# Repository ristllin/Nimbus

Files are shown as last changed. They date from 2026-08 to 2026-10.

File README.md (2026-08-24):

<p align="center">Nimbus - dotted teal ring logo</p>

# Nimbus

<!-- HERO PHOTO PLACEHOLDER: assembled device on a desk - ring lit, the touch
     panel showing the status screen. Add the photo to assets/ and embed it here. -->

<p align="center">
  
  
  
</p>

A DIY desk device that keeps you informed without stealing your screen.
Two modes on one firmware: an ambient **status light for AI coding sessions**
(encrypted Bluetooth, per-session ring segments), and a **self-hosted AI
assistant** with voice, Telegram, and long-term memory on its own SD card.
A 45-LED ring plus a 2.8" color touchscreen (or a Freenove all-in-one touch
board) on an ESP32-S3. Bring your own API key (Mistral, OpenAI, or Anthropic);
about **$60–75 in commodity parts** to build.

**Documentation: https://docs.cumulo-nimbus.ai/**

## What you need

- The electronics - dev board, display, LED ring, mic/amp/speaker, microSD,
  battery section: full list with sourcing links and prices in the
  **[bill of materials](docs/hardware/bom.md)** (~$60–75)
- A data-capable USB-C cable
- A computer with a Chromium browser (web flasher) or Python 3 + PlatformIO
- A 2.4 GHz Wi-Fi network
- One AI provider API key (Orchestrator mode; skip for the status light)
- Optional: a FAT32 microSD card for long-term memory, and a Telegram account

## Quick start

The step-by-step path - parts → flash → setup wizard → first conversation -
lives on the docs site:

1. **[What you need](https://docs.cumulo-nimbus.ai/quick-start/what-you-need)**
2. **[Flash the firmware](https://docs.cumulo-nimbus.ai/quick-start/flash)**
   - browser flasher, or `python3 tools/setup_device.py` over the DevKit's
   **UART** port (a factory-fresh board flashes only through that port)
3. **[Set up the device](https://docs.cumulo-nimbus.ai/quick-start/setup-wizard)**
   - join the `Nimbus-setup` network, walk the wizard
4. **[Your first conversation](https://docs.cumulo-nimbus.ai/quick-start/first-conversation)**
   - or the **[Notifier quick start](https://docs.cumulo-nimbus.ai/quick-start/notifier-quick-start)**
   for the status light

## Safety

This build contains a **2S lithium-ion pack** (two 18650 cells in series).
Use brand-name cells from a reputable vendor, always keep the 2S BMS between
the cells and everything else, never charge outside the BMS, and power off
immediately if anything gets warm that shouldn't. The firmware caps LED
brightness at 60% of maximum: sustained higher levels have been tested and
can overheat and damage internal electronics, so do not raise the limit. See
the [BOM safety note](docs/hardware/bom.md#safety-note--2s-li-ion).

**You build and operate this project entirely at your own risk.** It is a DIY
prototype, not a certified product, and comes with no warranty of any kind;
the author accepts no liability for damage or injury arising from building or
using it. Read [DISCLAIMER.md](DISCLAIMER.md) before you start, especially if
your build includes the battery.

## Building the firmware

Board support lives in the public
[solide-drivers](https://github.com/ristllin/solide-drivers) repository,
consumed as a PlatformIO library. `platformio.ini` expects it as a **sibling
checkout** (`symlink://../solide-drivers`):

```bash
git clone https://github.com/ristllin/Nimbus.git
git clone https://github.com/ristllin/solide-drivers.git   # sibling directory
cd Nimbus
pio test -e native            # host unit tests, no hardware
pio run -e esp32s3            # compile production firmware
python3 tools/setup_device.py # guarded install over the UART port
```

If you prefer not to keep a sibling checkout, point the `lib_deps` entry in
`platformio.ini` at the public git URL instead.

Nimbus speaks the [nimbus-notify](https://github.com/ristllin/nimbus-notify)
wire protocol (`pip install nimbus-notify` for the host-side broker), and
ships signed firmware updates from
[nimbus-fw-releases](https://github.com/ristllin/nimbus-fw-releases).

## Layout

- `lib/core/` - portable logic (no Arduino): protocol codec, profiles, power
  policy, the orchestrator memory engines and turn contract. Host-tested.
- `src/` - firmware: hardware glue (`hw/`), modes (`modes/`), the agent
  subsystem (`agent/`), the web surface (`net/`), entry point.
- `lib/harness/` - the agent policy/orchestration layer, host-testable.
- `test/` - Unity C++ **host** suites per module (run under `pio test -e native`,
  no hardware); golden framebuffers pin every screen.
- `tests/hil/` - the Python **hardware-in-the-loop** suite (drives a real board).
  (The `test` *build environment* is a third, unrelated thing - the firmware plus
  a serial console the HIL suite drives.)
- `docs/` - the canonical documentation tree
  ([map](docs/README.md)); `website/` publishes it to GitHub Pages.
- `hardware/` - the physical build: PCB manufacturing files (`fab/`) and a home for
  assembly notes, BOM, and CAD. The published build guides live in `docs/hardware/`.
- `tools/` - installer, recovery, calibration, generators, test harnesses
  ([index](tools/README.md)).
- `evals/` - orchestrator behavior benchmark (scenario corpus, scoring, reports).

Contributor guide: [CONTRIBUTING.md](CONTRIBUTING.md) and the
[development guide](docs/development.md) (build environments, test ladder,
golden-test flow, hard-won constraints).

## Community

Questions, builds, and ideas:
[GitHub Discussions](https://github.com/ristllin/Nimbus/discussions).
Bugs: [issues](https://github.com/ristllin/Nimbus/issues).

## License

Nimbus is **source-available for noncommercial use**:

- **Code, firmware, scripts** - [PolyForm Noncommercial License 1.0.0](LICENSE)
- **Documentation, hardware design files, images** -
  [CC BY-NC-SA 4.0](LICENSE-docs)
- Attributions and third-party notices: [NOTICE](NOTICE)

Build one, modify it, share your fork - just not commercially.

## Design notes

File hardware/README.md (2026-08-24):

# Hardware

Everything physical about a Nimbus build - what to source, how to assemble it, and
the board manufacturing files.

> **New here?** Start with the documentation, which walks the whole build:
> - [Bill of materials](../docs/hardware/bom.md) - what to buy, with sourcing links
> - [Build guide - Touch TFT](../docs/hardware/build-tft.md)
> - [Hardware reference](../docs/hardware.md) - pinout, wiring, power
>
> Those pages are also on the [documentation site](https://docs.cumulo-nimbus.ai/).

> **Safety and liability:** you build at your own risk. This is a DIY
> prototype involving lithium-ion batteries, not a certified product; no
> warranty, no liability. Read [DISCLAIMER.md](../DISCLAIMER.md) first.

## What's in this folder

| Path | Contents |
|---|---|
| [`fab/`](fab/) | PCB manufacturing outputs (Gerbers, drill, ODB++) for the Solide S3 carrier board, [how to order it (e.g. JLCPCB)](fab/README.md#ordering-the-pcb), and the [3D-printable enclosure STLs](fab/README.md#3d-printing-the-enclosure). Not required if you build from off-the-shelf modules. |

## Assembly notes, BOM extras, and CAD

This folder is the home for build material that isn't firmware: assembly photos and
step notes, a spreadsheet BOM, enclosure/CAD files, and any wiring harness details.
It starts light on purpose - add to it as the physical design settles. The canonical,
published build documentation stays under [`docs/hardware/`](../docs/hardware/) so it
ships to the docs site; this folder holds the source artifacts those pages describe.

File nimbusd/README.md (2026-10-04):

# nimbusd - the hosted Nimbus daemon

A **virtual nimbus**: the same Nimbus orchestrator the desk device runs (turn
engine, memory, tools, provider adapters, Telegram persona), running as a Linux
process in a container instead of on an ESP32. To cumulo it is just a device.
This directory is Phase 0 of the Virtual Nimbus plan
(`../../cumulo/docs-internal/virtual-nimbus-plan.md`): the daemon itself, before
the relay sidecar (Phase 1) and provisioning/billing (Phase 2).

## What is the real code, and what is new

Everything above the transport seam is the **same portable engine** the firmware
compiles - `lib/core` (turn contract, memory engines, tool registry, RBAC) and
`lib/harness` (turn engine, provider adapters, compose/apply). nimbusd is a
composition: it wires that engine to durable POSIX stores and a real network
transport, exactly as `tools/harness-lab` wires it to RAM and libcurl for host
testing. A bug reproduced here is a bug on the board, and vice versa.

New code lives only in this directory:

| File | What it is |
|---|---|
| `src/posix_fs.h` | `PosixEpiFs` (the `EpiFs` byte-file seam over a POSIX tree) + `fsutil` atomic tmp->rename writer |
| `src/posix_platform.h` | `agent::Platform` with **cgroup v2 heap accounting** so the engine sheds load before the kernel OOM-kills the pod |
| `src/daemon_http.h` | `agent::HttpTransport` over one persistent, connection-reusing curl handle; bodies never retained; keeps only the bounded error headers a request asks for (a 429's `x-ratelimit-*` quota window) |
| `src/posix_files.h` | disk-backed `files.*` / `artifact.save` (real bytes + `FileStore` index, `validSegment` gate) |
| `src/daemon_config.h` | `HarnessConfig` inputs from env + an optional config file (env wins); secret masking |
| `src/telegram.h` | Telegram channel over the portable `nimbus::tg::parseUpdates` + offset arithmetic; durable offset |
| `src/tg_access.h` | who may talk over Telegram: the device's fail-closed allowlist + approval queue + the shared RBAC `TenantStore`, durable on the instance volume |
| `src/tg_inbound.h` | routes each getUpdates batch through `tg_access.h`: approved text becomes a turn, anyone else is queued for approval and told so |
| `src/tg_web.h` | the device's `/api/telegram*` + `/api/tenant` routes over `tg_access.h`, so the web app's Telegram panel manages a hosted instance unchanged |
| `src/rig.h` | `NimbusdRig` - the composition, rehydrating all stores on construct and flushing after each turn |
| `src/engine_thread.h` | the concurrency layer: one engine thread + request mailbox + a snapshot for lock-free reads |
| `src/http_control.h` | the 127.0.0.1-only control surface (serves the web app + logo, health, replies, message, MCP, backup; delegates `/api/*` to `WebApi`), web-token gated |
| `src/web_api.h` | the `/api/*` surface the web app calls, answered with honest Virtual Nimbus semantics (real chat/memory/providers; hardware panels honestly virtual) |
| `src/web_ui.h` | assembles the served page and seeds the tunnel sign-in token ahead of the app script |
| `src/webui_page.h` | GENERATED (`tools/gen_webui.py`): the device's web app fragments, byte-parity with `tools/webui_page.snapshot`, plus the brand logo |
| `src/reply_buffer.h` | the bounded, thread-safe ring of recent chat entries (seq + timestamp + role) that backs `GET /api/replies` and `/api/chat` |
| `src/main.cpp` | the daemon entrypoint (config, threads, Telegram poll, graceful shutdown) |

## Durable data layout (`/data` by default)

```
/data/mem/vectors.bin        associative (vector) memory - atomic snapshot
/data/mem/episodic/*.jsonl   episodic append-log day-streams (durable per write)
/data/mem/scratchpad.txt     the model's working-memory tiers
/data/mem/memconfig.txt      retrieval/decay knobs
/data/mem/files/             file artifacts + .index
/data/mem/telegram.txt       Telegram allowlist, display names, consumed legacy seed and the
                             RBAC roles + limits, in ONE atomically written file
/data/tg_offset              Telegram long-poll offset (no re-delivery on restart)
```

**Memory survives restart.** The episodic append-log is durable per message; the
whole-file stores are flushed (atomic tmp->rename) after every turn and on a
clean shutdown, and rehydrated on construction. This is proven offline by
`tests/test_posix_stores.cpp` and `tests/test_rig.cpp`, and live (with real
embeddings) by the `restart` scenario.

## Build and test

```bash
make test        # offline unit/T2 suite (no keys, no network) - the CI marker
make daemon      # build ./build/nimbusd
make scenarios   # build ./build/nimbusd-scenarios (PAID to run - see below)
make check       # compile-only anti-rot gate
```

Host builds need ArduinoJson (populate `.pio/libdeps/native` once with
`pio test -e native` at the repo root) and a sibling `../solide-drivers` checkout
(the portable headers). The Docker build fetches both itself.

### Docker

```bash
docker build -f nimbusd/Dockerfile -t nimbusd:dev .   # context = repo root
docker run --rm -e TELEGRAM_BOT_TOKEN=... -e MISTRAL_API_KEY=... \
  -e NIMBUSD_WEB_TOKEN=... -v nimbus-data:/data nimbusd:dev
```

The build stage runs `make test`, so a broken build never produces an image.

### Connectors e2e (live, paid)

`tools/vn_connectors_e2e.py` drives a running instance over its HTTP surface the
way the web app does: it configures Studio connectors (gcal, notion, slack on
Mistral), runs the workspace probe via `POST /api/verify` and checks that the
connector badge, the Capabilities row and the model catalog agree; then it asks
"What is on my calendar today?" and asserts the reply names an event that one
independent Mistral call with the calendar connector sees. Secrets come only from
the environment (`NIMBUSD_WEB_TOKEN`, `MISTRAL_ORACLE_KEY`) and every evidence
file is redacted. `--skip-bc` runs the free configuration + probe step only. It
waits between paid calls (`--settle`) because a Mistral key's Studio connectors
have their own per-minute and per-day request quota (`x-ratelimit-*-custom-*`
headers). A turn the provider refused is retried once, after `--settle`, only
when the reply names a window that can reopen by then (per-minute, or none
named); a spent daily quota or a plan that allows no such request is recorded,
not retried. It recognizes those replies by the engine's own 429 copy
(`lib/harness/src/rate_limit.cpp`), which `tools/test_vn_connectors_e2e.py`
pins as part of `make test`.

## Configuration

Secrets come from the environment (a mounted Secret in k8s); non-secret settings
may also live in `<data>/config.env`. Env always wins. Nothing secret is logged
(masked to 4 chars).

| Key | Meaning |
|---|---|
| `OPENAI_API_KEY` / `ANTHROPIC_API_KEY` / `MISTRAL_API_KEY` | BYOK provider keys (Phase 0 key mode) |
| `TAVILY_API_KEY` | web.search (the router does not proxy it) |
| `TELEGRAM_BOT_TOKEN` | the instance's bot (validate with `nimbusd --getme`) |
| `NIMBUSD_TG_CHAT_ID` | **legacy**, optional: a one-time seed of an EMPTY Telegram allowlist (see Telegram access below). It is no longer a gate |
| `NIMBUSD_WEB_TOKEN` | required to reach the control surface (the sidecar injects it) |
| `NIMBUSD_DATA_DIR` | durable store root (default `/data`) |
| `NIMBUSD_CONTROL_ADDR` / `NIMBUSD_CONTROL_PORT` | control surface bind (default `127.0.0.1:8787`) |
| `NIMBUSD_DEVICE_NAME`, `NIMBUSD_PRIORITY`, `TZ` | display name, provider failover order, timezone |
| `NIMBUSD_SUB_PRIORITY` | sub-agent provider order (device `subPrio`); unset = same as `NIMBUSD_PRIORITY` |
| `NIMBUSD_ORCH_HOST` | pin the head provider (device `orchHost`); unset = the first keyed provider in `NIMBUSD_PRIORITY` |
| `NIMBUSD_TOOL_LOOP` | `1` (default) head tool loop, `0` single-shot head turns (device `orchLoop`) |

## Telegram access (the device model)

A hosted instance trusts **no** Telegram chat by default, exactly like the desk
device. With a bot token set and nobody approved, every chat is refused: it gets
no turn, one polite message saying the owner has to approve it (at most once per
10 minutes per chat), and it waits in the approval queue (the newest 5, RAM only).
The owner approves people in the instance's own web app (**Assistant, Connectors,
Telegram**): one tap on a waiting sender, or **Add** by chat ID. The allowlist and
the roles are stored on the instance volume, so they survive restarts and ride
`GET /backup`.

- **Roles are the existing RBAC.** An approved chat is a **user**; admin is only an
  explicit grant (click a chip's role to cycle admin, user, guest, or `POST
  /api/tenant`). This differs from the device, which adopts the first approved chat
  as admin: on a hosted instance the owner lives in the web app, and that rule would
  hand owner rights to whoever was approved first. A user or guest runs as
  themselves: their own memory namespace, their own recall, a prompt that says who
  is speaking, and no access to the owner's files. An approved chat of any role can
  use the owner's connectors and start sub-agents: approving someone is granting
  that.
- **One namespace's sub-agent work at a time.** The shared job engine keeps one pool
  of sub-agent results and folds it into whoever speaks next, so a hosted instance
  keeps queued, running and unreported work inside one data namespace: a spawn
  from another namespace is refused with the reason, and a member's turn from
  another namespace is held on the engine thread until that work is reported (the
  owner's own turns never wait).
- **Revoking** (role `unknown` through `POST /api/tenant`) or removing a chat takes
  effect on its next message; a revoked chat is told its access was removed, and a
  removed chat's role is erased (re-approving starts it as a user). Work it left
  running is not reported to it.
- **No open access.** The device's "Open access" switch is refused on a hosted
  instance: a public bot would spend the owner's keys and reach the owner's
  connectors.
- **`NIMBUSD_TG_CHAT_ID` is legacy.** If set, it seeds an EMPTY allowlist once (that
  chat becomes the admin, since the operator named it as the owner's) and is then
  consumed: a list the owner already manages is left alone, and a seeded chat the
  owner removes does not come back on restart.
- The web chat and the token-gated control API are the owner's own surfaces and
  always run as the admin; a Telegram chat id posted to `POST /api/message` is held
  to the same allowlist as the Telegram poll.

The routing and every rule above are host-tested offline in
`tests/test_tg_access.cpp` and `tests/test_sub_fabric.cpp`.

## Control surface (the seam the Phase-1 sidecar forwards to)

Bound to **loopback only**. The data routes require the web token
(`X-Nimbus-Token` header, `Authorization: Bearer <token>`, or `?token=`); only the
app shell (`/`, `/index.html`), the brand logo (`/logo.svg`), `/healthz` and the
pre-auth sign-in exchange are ungated. The relay sidecar injects the token on
every forwarded request, so the browser reaches all of these through the tunnel.

| Method + path | Purpose |
|---|---|
| `GET /` and `GET /index.html` | the assembled Nimbus web app (ungated shell; seeds the tunnel sign-in token) |
| `GET /logo.svg` | the brand mark (ungated; a logo is not sensitive) |
| `GET /healthz` / `GET /readyz` | liveness (ungated) / readiness (200 iff the engine thread is running) |
| `GET /api/state`, `/api/health`, `/api/orch` | Home / Assistant snapshots, served from the engine snapshot + immutable config (never enter the engine) |
| `POST /api/chat` + `GET /api/chat` | send a turn, then poll for the reply (the web app's chat surface) |
| `GET /api/replies?after=<seq>` / `POST /api/message` | the CUM-263 reply ring + enqueue-a-turn contract (kept stable) |
| `GET/PUT /api/mem/*`, `GET /api/tools` | memory dashboard, dispatched onto the engine thread (single-context safe) |
| `GET /api/themes`, `/api/qr`, `/api/docs/search` | pure/static surfaces (no engine, no hardware) |
| hardware panels (`/api/audio/*`, `/api/wifi`, `/api/ota/*`, ...) | honest "not on a hosted instance" - never a faked value or a dead control |
| `POST /mcp`, `GET /backup` | JSON-RPC to the tool registry / a consistent tar of the mem tree |
| `GET/POST /api/connectors` | the connector registry (device contract); each configured entry carries the derived `auth` the badge reads |
| `GET /api/connectors/catalog` | the model-facing `[PROVIDERS & CONNECTORS]` block exactly as the next turn gets it (text) |
| `POST /api/verify` | `provider=mistral` re-runs the Mistral workspace probe in the background; other providers are acknowledged |
| `GET /api/telegram`, `POST /api/telegram/{add,approve,deny,remove,rename,role,public}` | the Telegram allowlist + approval queue (device routes and shapes); `public` (open access) is refused on a hosted instance |
| `GET/POST /api/tenant` | RBAC roles + limits per approved chat (device routes, device guards) |

**Mistral Studio connectors (device parity).** A Studio connector (gcal, notion,
slack, ...) has no stored credential: it is usable once the Mistral key's workspace
lists it as active in `GET /v1/connectors` (the shared rule in
`lib/core/.../connectors_wire.h`; `is_authenticated` is only a hint, since it reads
false for connectors that work). The device runs that probe after each Mistral
verify; the hosted page has no verify button, so the daemon runs it at startup,
after a Mistral key is saved, after a connectors write while the workspace is still
unchecked, and on `POST /api/verify provider=mistral`. It is skipped (no request)
without a Mistral key or an enabled Studio connector, and until an answer lands a
Studio connector reads not usable (fail-closed). The catalog, the `/api/connectors`
badges and the `/api/tools` connector rows all read one auth-stamped view, and the
catalog names the head the turn really runs on (the first keyed provider, or the
`NIMBUSD_ORCH_HOST` pin). Studio connectors never ride a Mistral HEAD turn here
(`headProviderDeps`): the head's single-shot turn always carries the strict
structured-output schema, and Mistral does not answer a call that combines it with
a Studio connector (closed at 60 s, measured), so they run on a spawned Mistral
sub-agent (free text), and the catalog and `/api/tools` report them sub-agent-only.

**The web app (CUM-265).** `GET /` serves the device's own single-page app - the
exact fragment bytes the device serves (`tools/gen_webui.py` assembles them from
`include/web/ui_*.h`, byte-parity with `tools/webui_page.snapshot`) - so a Virtual
Nimbus is recognizably the same product, not a bare chat page. The shell is
ungated because it holds no instance data; every byte it shows comes from the
gated `/api/*` routes. **Tunnel sign-in:** the app gates its views on a per-device
token in the browser, which inside the tunnel there is no device screen to scan
for, so the served page seeds this instance's web token ahead of the app script -
the tunnel equivalent of the device's first-run auto sign-in. **Honest virtual
semantics:** the assistant panels (chat, memory, providers, usage, tools) are the
real engine; the hardware panels (ring, display, touch, battery, audio, Wi-Fi, ESP
OTA) report their honest virtual truth and never fabricate a reading or leave a
dead control, and software update is the platform rolling the instance image, not
an ESP OTA. A keyless instance still says so plainly rather than sitting silent.

## Sub-agent fan-out (device parity)

A spawned sub-agent is how the device runs a provider's connectors off its own
turn (a Mistral sub carries the Studio connectors server-side) and how it farms out
research. The hosted instance now runs the same machinery: the portable
`JobEngine` (queue, one dispatch per pump, round-robin poll, the synthesis turn)
over a fabric of five adapters (`src/sub_fabric.h`: anthropic, openai, mistral,
zai, cumulo) that call the same `providers::*Dispatch/Poll/Cancel` wire functions
the device adapters wrap, each resolving the instance's current key, model and
connectors at call time. The engine thread pumps the jobs after every task and on
every idle tick, so dispatches and the synthesis turn stay serialized with turns
(the device's one-work-slot rule). The job journal lives on the instance volume
(`<data>/mem/journal/j<slot>.json`), so an unfinished job re-attaches after a
restart instead of being dispatched again.

Every spawn runs the configured sub model for its provider (no live model catalog
to validate a per-spawn pick against), and a spawn on an unkeyed provider is
answered with an honest "couldn't start" message; one the provider refuses with
HTTP 429 also names the quota window, read the same way as a head turn's 429.
Not wired yet on a hosted
instance: skill capsules, document attachments, auto-saving a sub's result into a
project, and provider file capture (the engine passes the task through and notes
attachments instead of splicing them).

This replaces the Phase 0 "fabric-less" composition, under which the JobEngine
had no fabric and every spawn was dropped without a message, so a Mistral Studio
connector could never run under the default tool loop.

## The scenario suite (live, paid)

`make scenarios` builds `build/nimbusd-scenarios`, which runs the harness-lab
outcome scenarios **against the daemon composition** (real provider turns), plus
a daemon-only `restart` scenario (write a fact, tear the rig down, rebuild on the
same data dir, recall). Provider keys come from the env or a dotenv file
(`--env`, `NIMBUS_ENV_FILE`, `~/.env`). Scenarios with no key **skip loudly** - a
silent skip reads as a pass. A full run is ~100K input tokens.

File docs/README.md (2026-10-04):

# `docs/` - the canonical documentation tree

This directory is the **canonical source** for all Nimbus documentation. The
published site (https://docs.cumulo-nimbus.ai/) is a generated *view* of it:
`website/scripts/migrate-docs.mjs` copies every page listed in its `PAGES` table
into `website/docs/**` with front matter and link fixes. Edit here, re-run the
migrate script, commit. Two site pages are hand-written and live only under
`website/docs/` (the intro and the getting-started guides); the generated mirror
under `website/docs/{quick-start,guides,reference,contributing}/` is rebuilt on
deploy and is not committed.

Three other generators read this tree - keep them in sync when you edit:

- `tools/gen_docs_pack.py` (CURATED list) - embeds selected docs into the firmware
  so the on-device assistant can read them. Re-run after editing a curated file.
- `tools/check_status_doc.py` - CI gate keeping `notifier-status-language.md`
  byte-consistent with `lib/core/src/status_style.cpp`.
- `tools/sounds/gen_sfx_map.py` - **generates `sfx-map.md`. Never edit that file by
  hand.**

## The docs tree

### Quick start
| File | Covers |
|---|---|
| `quick-start/what-you-need.md` | Parts, tools, and prerequisites |
| `quick-start/computer-setup.md` | Set up your computer for the command-line flasher (terminal, Python, PlatformIO, drivers) |
| `quick-start/flash.md` | Flashing the firmware (browser flasher or the UART port) |
| `quick-start/setup-wizard.md` | Joining the setup network and walking the wizard |
| `quick-start/first-conversation.md` | First Orchestrator conversation |
| `quick-start/notifier-quick-start.md` | Bringing up the status light |

### Hardware
| File | Covers |
|---|---|
| `hardware.md` | Pinout, wiring, and first-flash guidance (overview) |
| `hardware/README.md` | Folder map for the hardware directory |
| `hardware/bom.md` | Consolidated bill of materials (all configurations) |
| `hardware/build-tft.md` | Build guide - touch TFT |
| `hardware/touch-tft.md` | Configuration A - touch TFT (Solide S3) |
| `hardware/all-in-one-cyd.md` | Configuration B - all-in-one (Freenove CYD) |

### Using Nimbus
| File | Covers |
|---|---|
| `modes-and-signals.md` | Every user-facing knob and what it changes |
| `led-ux.md` | The LED experience - motion and color |
| `notifier-status-language.md` | Session-status → color/animation map (CI-checked against code) |
| `sfx-map.md` | Audio state language (**generated** - never hand-edit) |
| `connectors.md` | External tools per provider |
| `mcp.md` | The device as an MCP client and server |
| `people-and-privacy.md` | Roles, quotas, and what stays private |

### Cloud
| File | Covers |
|---|---|
| `cloud-relay.md` | Cloud access: reach the device from anywhere (remote tunnel) |
| `cloud/cumulo-key.md` | Use your Cumulo key on the device and from your own code |

### How it works
| File | Covers |
|---|---|
| `architecture.md` | The system, layer by layer |
| `turn-anatomy.md` | What the model sees in a turn |
| `architecture/orchestrator-live-turn.md` | The live orchestrator turn |
| `orchestrator-world.md` | The agent's memory and control surface |
| `memory.md` | RAM pools, the turn budget, and compaction |
| `orchestrator-storage.md` | Storage tiering (SD / PSRAM / NVS / LittleFS) |
| `sub-sessions.md` | Background sub-agents, end to end |
| `harness.md` | The agentic harness |
| `provider-wire.md` | Structured outputs, tool loops, model catalog, and fallbacks per provider |
| `security.md` | The auth model and open items |

### Reference
| File | Covers |
|---|---|
| `reference/config-and-nvs.md` | Config keys and NVS layout |
| `reference/tool-catalog.md` | The tool catalog |
| `reference/turn-contract.md` | The turn contract |
| `reference/capabilities-matrix.md` | Provider x role x feature matrix, plus the memory-embeddings request per provider (generated from the catalog and the embeddings builder) |
| `tools-and-commands.md` | User and contributor tools and console commands |
| `changelog.md` | Release history |

### Forking & contributing
| File | Covers |
|---|---|
| `development.md` | Build environments, the test ladder, golden-test flow, constraints |
| `ota.md` | Over-the-air firmware updates |
| `self-hosted-ota.md` | Running your own OTA release channel |

## Page types (Divio)

Every page is one of the four [Divio](https://docs.divio.com/documentation-system/)
types, and the sidebar groups them by type so a reader lands in the right mode.
Keep new pages to one type; the few intentional blends below are called out so
they are not "fixed" into fragments (coherency over richness).

| Type (learning mode) | Sidebar group(s) | Pages |
|---|---|---|
| **Tutorial** (learning by doing) | Quick Start | `what-you-need`, `computer-setup`, `flash`, `setup-wizard`, `first-conversation`, `notifier-quick-start` |
| **How-to** (task recipes) | Hardware Build, Using Nimbus, Cloud, Forking & Contributing | `hardware/*`, `modes-and-signals`, `connectors`, `mcp`, `people-and-privacy`, `cloud-relay`, `cloud/cumulo-key`, `ota`, `self-hosted-ota`, `development` |
| **Reference** (look it up) | Reference | `reference/*`, `tools-and-commands`, `changelog`, `notifier-status-language`, `sfx-map`, `hardware/bom` |
| **Explanation** (understand why) | How It Works | `architecture`, `turn-anatomy`, `architecture/orchestrator-live-turn`, `orchestrator-world`, `memory`, `orchestrator-storage`, `sub-sessions`, `harness`, `provider-wire`, `security`, `led-ux` |

Intentional blends (kept whole on purpose):

- `what-you-need` is a tutorial that opens with a reference checklist; the
  checklist is what a first build needs in front of it.
- `flash` is a how-to whose back half is reference (reflash, recovery, build
  environments), clearly separated by a rule and a "the rest of this page is
  reference" line.
- `hardware.md` and `modes-and-signals.md` carry a short "for developers" source
  table at the end so a reader never has to leave the page to find where the
  behavior lives; the body stays single-type.

## Rules of the road

- **Site structure** lives in `website/sidebars.js`; a page migrated by `PAGES`
  but absent from the sidebar is an orphan the site never links to.
- **Generated files are never hand-edited**: `sfx-map.md`,
  `website/docs/{guides,reference,quick-start,contributing,cloud}/**`, and
  `lib/core/include/nimbus/docs_pack_data.h`.
- **Docs follow every commit**: rename or move anything user-visible and you grep
  for the old wording and fix every hit in the same commit; before a release,
  `cd website && npm run build` must pass with zero broken links.
- Copy style (Title Case for tabs/buttons, sentence case for labels, "Wi-Fi" not
  "WiFi", "restart" not "reboot", US English) is defined in `AGENTS.md`.

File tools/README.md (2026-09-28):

# tools/ - quick index

One line per tool, grouped by audience. This is the fast map; the full catalog
(what each does in depth, plus every console and Telegram command) is
[`docs/tools-and-commands.md`](../docs/tools-and-commands.md).

Run host scripts with `python3` from the repository root unless noted. Most need
only the standard library.

**⚠ Load-bearing** tools are marked below - breaking one breaks CI, the build, or
a release. See the [maintenance contract](AGENTS.md) before adding or moving a
tool.

## End-user device tools

Everything you need to install, recover, and manage a device you own.

| Tool | One-liner |
|---|---|
| `setup_device.py` | Guarded firmware installer over the UART port (MAC-confirmed; seeds display + mode on a fresh board). |
| `usb_reset.py` | Programmatic unbrick - a libusb bus reset, equivalent to replugging a wedged USB-serial port. |
| `tcal_wizard.py` | Touch-calibration wizard for the TFT variant (four-corner press → axis/orientation flags via `TCAL`). |
| `connectors_setup.py` | Push connector credentials from the root `.env` to a board via the token-gated API (`--list` to inspect). |
| `backup_device.py` | Pull a board's user data (files, vectors, scratchpad, state) over the web API into a dated folder. Read-only; never exports secrets. |
| `ring_check.py` | Quick LED-ring smoke test over serial (`LEDTEST` acknowledgement). |

## Generators (edit the generator, re-run, commit the output)

Every tool here owns a committed output; the generator is the source of truth.
The generator→output contracts are enumerated in the root
[`AGENTS.md`](../AGENTS.md) "Docs follow every commit" section - never hand-edit
a generated file.

| Tool | Generates |
|---|---|
| **⚠ `gen_docs_pack.py`** | `lib/core/include/nimbus/docs_pack_data.h` - the on-device docs pack (ships in firmware.bin). |
| `gen_nsn_vectors.py` | `tools/nsn_vectors.json` + embedded header - nsn codec test vectors, byte-locked to `nsnotify`. |
| `gen_qr_vectors.py` | QR known-answer vectors from Project Nayuki's `qrcodegen` (needs `pip install qrcodegen`). |
| `sounds/` | The sound-pack pipeline → `dist/` + manifest + `src/sfx/sfx_basic_data.h` + `docs/sfx-map.md` (see its README). |
| `logo/gen_logo.py` | The Nimbus logo and every derived artifact (`assets/logo*.svg`, website logo/favicon/social card, `include/web/ui_logo.h`). |

## CI gates (run in `.github/workflows/checks.yml`)

| Tool | ⚠ Breaks if it fails |
|---|---|
| **⚠ `check_param_consumers.py`** | Fails the build if a settings parameter has no functional consumer (a knob that changes nothing). |
| **⚠ `check_status_doc.py`** | Fails when `docs/notifier-status-language.md` drifts from `status_style.cpp`. |
| **⚠ `webui_concat_check.py`** | Asserts the `include/web/ui_*.h` fragments re-concatenate into a well-formed page (byte-compares the blessed snapshot). |

## Build & release

| Tool | Role |
|---|---|
| **⚠ `git_version.py`** | PlatformIO `extra_scripts` - injects `git describe` as `NIMBUS_FW_BUILD`. Runs on **every** build (platformio.ini). |
| **⚠ `make_manifest.py`** | Signs the OTA release manifest (release.yml). Message byte-identical to `nimbus::ota::buildSigMessage()`. |
| **⚠ `release/make_webflash_manifest.py`** | Builds the web-flasher manifest (release.yml). |
| **⚠ `release/check_known_patterns.sh`** | Pre-commit leak gate (private `ops/leak_patterns.txt`; warns-and-passes for public contributors). |
| `release/seed_public_root.sh` | Maintainer gate - builds + verifies the public-repo root cut. Needs the private `ops/leak_patterns.txt`; refuses to run without it. |
| `release/lizard_whitelist.txt` | Baseline for the pre-commit lizard complexity gate. |
| `build_all.sh` | Compile-only gate: builds every PlatformIO environment and flag path. |

## Dev / contributor

| Tool | One-liner |
|---|---|
| `tftpreview.py` | Color counterpart for the TFT golden suite - `contact` sheet + tap-`regions` linter. |
| `nsn_send.py` | End-to-end broker→Bluetooth→device validation (needs `bleak` + macOS BT entitlement). |
| `harness-lab/` | Runs the real agent harness on the Mac instead of the device (see its README). |
| `test_setup_device.py` | Unit tests for `setup_device.py`. |
| `test_tcal_wizard.py` | Unit tests for `tcal_wizard.py`. |
| **⚠ `release_gate/tag_shape.py`** | Release channel gate (release.yml): OTA tag vs virtual vn- tag, version.h coherence. |

Bench-only and board-specific scripts (a live connector-QA harness, the quality
benchmark, panic-capture, the connector-shape grid) live in the private `ops/`
tree, not this public repo. The **Battery Lab** is its own project at
[ristllin/nimbus-battery-lab](https://github.com/ristllin/nimbus-battery-lab);
it drives the firmware's `DRAIN`/`STORAGE` commands, which remain here.

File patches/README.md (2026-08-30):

# Pending driver patches (for the orchestrator)

## solide-drivers-0.7.2-healthy-flip-aware.patch

The real fix for CUM-231 (white-screen regression), against solide-drivers **v0.7.1**.
Touches `src/device/display_tft.cpp` (`healthy()`) and `CHANGELOG.md`.

**What it does.** v0.7.1's `healthy()` masked the MY/MX flip bits (0xC0) out of the
RDDST compare on both sides (`kMask=0x3E`) to stop the flip=1 watchdog thrash. That
also dropped fault detection: a partial state loss that raises MY/MX in RDDST
(got=0xE8) while the fixed bits stay correct read HEALTHY. v0.7.2 instead compares the
full byte (minus the refresh scan-toggle bit0) against `madctlFor(g_flip)` with the
flip bits cleared - `(got & 0xFE) == (madctlFor(g_flip) & ~0xC0)`, which is 0x28 for
both orientations. Keeps the no-thrash property; restores detection of got=0xE8; reset
(0x00) still fails.

**How the orchestrator lands it:**
1. `git -C <solide-drivers> checkout v0.7.1 && git apply <this patch>` (or cherry-pick
   the equivalent commit), review the one-line compare change.
2. Tag **v0.7.2** and push (driver repo: github.com/ristllin/solide-drivers).
3. Bump the nimbus pin: `platformio.ini` line 63 `...solide-drivers.git#v0.7.1` ->
   `#v0.7.2`, and the note at line 7 / the pin-bump commit message
   (`2b7a3fa`-style).

**Verification already done (host):** nimbus `test/test_panel_health` pins the exact
compare arithmetic and asserts both directions - v0.7.0 thrash at flip=1, v0.7.1 mask
miss at got=0xE8, and v0.7.2 correct on all. `pio test -e native -f test_panel_health`.

**Bench verify still owed** (CUM-231 DoD 4): repro white on v4.4.3 in setup mode, then
confirm the fix on the TFT. Blocked on device availability (owner onboarding nimbus-6);
lane TF-F6B will patch `.pio/libdeps/*/solide-drivers` locally for the bench build when
a device window opens (host-side first per TASK.md).

**Open RCA item (see CUM-231 comment):** the driver fix corrects `healthy()`'s
semantics, but a *stuck* white in setup mode is only fully explained together with the
firmware `renderAndPush()` dirty-gate probe (`src/hw/tft_out.cpp:142`). See the lane's
`src/hw/tft_out.cpp` change and the CUM-231 DECISION comment.

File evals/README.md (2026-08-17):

# Nimbus orchestrator benchmark

A reproducible evaluation of the on-device orchestrator's real behavior - honesty,
security, sub-agent fan-out, and connector use - run against a fixed scenario corpus
on live hardware. Each run produces a machine-readable corpus that reduces to a
comparable summary and renders to a human report.

## The two-layer verdict

Every scenario turn is graded twice, and the layering is the point:

- **Oracle - the hard gate.** A deterministic, ground-truth side-effect check
  (marker round-trip, a real file appearing at `GET /api/files/dl`, an error-free
  `/api/log`, a fan-out peak > 0). The oracle catches a lying "Done!" that no
  amount of fluent prose can talk its way past. A test asserts on the oracle.
- **Judge - a soft signal.** An independent, cross-provider LLM scores each reply
  for quality and honesty, given the prompt, the reply, the real device-side tool
  trace, and the oracle verdict. It is deliberately run on a *different* provider
  from the one under test, so a model is never its own judge. The judge never gates
  a build; it flags dishonesty and quality drift the oracle cannot express.

A scenario passes only when no repetition fails the oracle and none is judged
dishonest.

## The scenario corpus

The 51 scenarios live in [`tests/hil/scenarios_complex.py`](../tests/hil/scenarios_complex.py),
in four categories:

| category | focus |
|---|---|
| `multi-subsession` | sub-agent fan-out, review-then-synthesize, cross-turn recall |
| `research-artifacts` | research, citation, artifact save/deliver |
| `resilience` | degraded capabilities, refusals, honesty under failure |
| `connector-chains` | provider-hosted connector delegation (Gmail, Notion, Drive, ...) |

Each scenario names a deterministic `oracle` (a function in `ORACLES`) and is also
scored by the judge. Scenarios declare a `feasibility` (`runs_now` / `honesty_test`
/ `owner_setup`) and a `host` provider to pin.

## Triage vocabulary

A failing scenario is triaged so history can tell a harness fault from a device
fault. Triage never changes pass/fail - it only classifies the failure:

| class | meaning |
|---|---|
| `apparatus` | the test rig was wrong (bad prompt, bad oracle, flaky fixture) |
| `behavior` | suboptimal device behavior, but not a regression |
| `regression` | the device got worse than a previous known-good run |
| `transient` | a one-off (network blip, provider 429) unlikely to reproduce |
| `untestable` | cannot be judged on this device/config (e.g. trace needs an SD card) |

Overrides are supplied in a `triage.json` next to a corpus (see `SCHEMA.md`).

## Cost and time warning

This benchmark drives **real, paid LLM turns on live hardware**. A full run costs
provider spend and takes roughly minutes per scenario (sub-agent fan-out and
connector turns are the slowest). It is not a unit test - run it deliberately.

## Running a benchmark

The runner is [`tests/hil/run_scenarios.py`](../tests/hil/run_scenarios.py). It
drives each scenario over HTTP against a device on the LAN, applies the oracle,
invokes the judge, and appends a JSONL corpus (one row per scenario x repetition)
under `tests/hil/qa_runs/`.

```bash
python3 tests/hil/run_scenarios.py --reps 3 --cat multi-subsession
```

See the runner's `--help` for scenario/category selection, repetition count, and
preflight gating. Provider keys and device address come from the HIL secrets
fixture, never the command line.

## Turning a run into a report

```bash
# reduce a corpus to the comparable summary point (summary.json)
python3 evals/summarize.py <corpus.jsonl> --run <name> --fw <describe> \
    --board <id> --date <YYYY-MM-DD> --cats <a,b>

# render one or more corpora to a report (text | md | html); 2+ files show deltas
python3 evals/report.py <a.jsonl> [<b.jsonl> ...] --format text
```

`summarize.py` writes a `summary.json` (see `SCHEMA.md`) - per-scenario pass/fail
plus totals broken out by triage class. `report.py` prints headline metrics, a
per-category breakdown, and a per-scenario grid; with multiple corpora it prints
the first-to-last delta.

## Reading a result

- **Corpus** (`*.jsonl`) - the raw record, one JSON object per scenario x
  repetition. Fields are documented in `SCHEMA.md`.
- **Summary** (`summary.json`) - `totals.pass` / `totals.fail`, `fail_by_class`,
  and a `scenarios` map with each scenario's pass, repetition count, and oracle /
  judge failure counts.
- **Report** - headline oracle-pass and mean-judge, wedged count, and the grid.
  A `P` is a pass, `F` a fail, `-` a scenario absent from that run.

## Known limitations

- **N = 1 variance.** A live LLM benchmark is noisy; a single run is a data point,
  not a proof. Compare across repetitions and runs.
- **Trace needs an SD card.** Some oracles read the episodic tool trace, which is
  SD-gated. On a card-less board those scenarios are `untestable`, not failures.
- **The judge is a soft signal.** It can be wrong. It never gates a build; the
  oracle does.

## Layout

```
evals/
  README.md            this file
  AGENTS.md            contributor notes
  SCHEMA.md            the versioned corpus + summary contract
  summarize.py         corpus.jsonl -> summary.json
  report.py            corpus(es) -> text | md | html report
  samples/             a small redacted corpus + its summary (fresh-clone runnable)
  tests/               unit tests for summarize.py + report.py
  runs/                archived run artifacts (gitignored, local only)
```

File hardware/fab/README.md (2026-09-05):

# `fab/` - PCB manufacturing outputs

Fabrication files for the **Solide S3 carrier PCB** - the artifacts a board house needs
to manufacture the board.

**You do not need anything in here to build, flash, or use the Nimbus firmware.** For
wiring and pinouts see the [hardware reference](../../docs/hardware.md) and the
[touch TFT configuration page](../../docs/hardware/touch-tft.md).

| Path | Contents |
|---|---|
| [`gerbers/`](gerbers/) | Gerber layers (copper, silkscreen, soldermask, solderpaste, profile), the drill file, and the Gerber job file |
| [`odb/pcb3_v7.zip`](odb/pcb3_v7.zip) | ODB++ export of the same board (zipped - most fabs accept either format) |
| [`nimbus_classic_case.stl`](nimbus_classic_case.stl) | 3D-printable enclosure for the classic (touch TFT) build |
| [`nimbus_classic_case.3mf`](nimbus_classic_case.3mf) | Bambu Studio print project for the classic case: the case split into its two-color parts with print settings already set (Bambu Lab X1 Carbon, 0.4 mm nozzle, 0.2 mm layers) |
| [`nimbus_light_front.stl`](nimbus_light_front.stl) | Nimbus Light (Freenove CYD) enclosure, front half |
| [`nimbus_light_back.stl`](nimbus_light_back.stl) | Nimbus Light enclosure, back half |
| [`nimbus_light_stand.stl`](nimbus_light_stand.stl) | Desk stand for Nimbus Light (optional) |

Both PCB formats describe the same board; supply whichever your fab prefers. The
STLs are for 3D printing and are not board files.

## Ordering the PCB

This is a **2-layer** board. Any PCB house that accepts Gerber or ODB++ can make it.
These files were last ordered from **[JLCPCB](https://jlcpcb.com/)**, which was cheap
and straightforward for a board this size; the steps below are for that service, but
any fab works the same way.

1. **Zip the Gerbers.** Compress the whole [`gerbers/`](gerbers/) folder into one
   `.zip`. (Or skip this and upload [`odb/pcb3_v7.zip`](odb/pcb3_v7.zip) as-is -
   JLCPCB accepts either.)
2. Go to **[jlcpcb.com](https://jlcpcb.com/)**, click **Add gerber file**, and upload
   the zip. The board renders in the viewer so you can confirm it parsed correctly.
3. The auto-detected settings are right for this board. The ones worth checking:
   - **Layers:** 2
   - **Dimensions:** read from the profile layer automatically
   - **PCB thickness:** 1.6 mm
   - **Surface finish:** HASL (lead-free) is cheapest; ENIG if you prefer
   - **PCB Qty:** 5 is the usual minimum
   Leave the rest (colour, copper weight) at default unless you have a reason to change it.
4. **Add to cart** and check out. Turnaround is usually a few days plus shipping.

> This produces a **bare board** only. You still populate it with the parts in the
> [bill of materials](../../docs/hardware/bom.md). JLCPCB also offers assembly (PCBA),
> which needs a BOM and pick-and-place file that are not generated here.

## 3D-printing the enclosure

PLA or PETG both work for every part; the main bodies print without supports on most
machines.

- **Classic (touch TFT) build:** print
  [`nimbus_classic_case.stl`](nimbus_classic_case.stl). On a Bambu printer, open
  [`nimbus_classic_case.3mf`](nimbus_classic_case.3mf) in Bambu Studio instead: it
  carries the two-color part split and the print settings, so nothing needs
  configuring.
- **Nimbus Light (Freenove CYD):** print both halves,
  [`nimbus_light_front.stl`](nimbus_light_front.stl) and
  [`nimbus_light_back.stl`](nimbus_light_back.stl). The board and its parts are captive
  between the two halves, so there is nothing else to fasten.
- **Desk stand (optional):** [`nimbus_light_stand.stl`](nimbus_light_stand.stl) angles
  Nimbus Light up on a desk.

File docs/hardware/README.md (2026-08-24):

# `docs/hardware/`

Hardware documentation for the Nimbus device. Start at the
[hardware reference](../hardware.md) - it covers everything common across the boards
and links into the configurations.

Nimbus runs in **one of two display configurations**:

| File | Configuration |
|---|---|
| [`touch-tft.md`](touch-tft.md) | **Touch TFT** (`screenModel=tft`) - color ILI9341 + XPT2046 resistive touch, hand-built on the Solide S3 board |
| [`all-in-one-cyd.md`](all-in-one-cyd.md) | **All-in-one (Freenove CYD)** (`SOLIDE_BOARD=freenove_s3`, `screenModel=tft`) - one off-the-shelf module, capacitive touch, lowest effort |

The first is hand-built on the Solide S3 board; the second is a separate
off-the-shelf board with its pinout fixed at flash time.

Building one from parts? Start with the parts list ([`bom.md`](bom.md)) and
the step-by-step build guide: [`build-tft.md`](build-tft.md) (touch TFT).
The all-in-one needs no build guide - see its [pinout & happy-path page](all-in-one-cyd.md).

## Folder layout

| Path | Contents |
|---|---|
| `../hardware.md` | Top-level reference: board configurations + everything shared (first flash, peripherals, power, battery) |
| `touch-tft.md`, `all-in-one-cyd.md` | The per-configuration pages (pinout, config-specific pins, notes) |
| [`bom.md`](bom.md) | Consolidated bill of materials (all configurations, prices, sourcing links) |
| `build-tft.md` | The step-by-step build guide |
| [`diagrams/`](diagrams/) | Pinout SVG (`pinout-tft.svg`), block-level wiring SVG (`wiring-tft.svg`), the ring status-language drawing (`ring-status-language.svg`, embedded by `../led-ux.md`), and the touch-UI screenshots (`tft-*.png`) |
| [`hardware/fab/`](https://github.com/ristllin/Nimbus/tree/main/hardware/fab) | PCB manufacturing outputs (Gerbers, ODB++), now at the repo top level - archival, not needed to build or use the firmware |

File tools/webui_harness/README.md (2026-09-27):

# Web-app test harness (lane N1)

Host-side sim-e2e (T4) harness + Playwright suite for the embedded web app
(`include/web/ui_*.h`). It reconstructs the exact page the device serves - the
ordered concatenation of the PROGMEM fragments (`concat.mjs`, byte-identical to
`tools/webui_page.snapshot`) - serves it with mock `/api/*` responses
(`server.mjs` + `fixtures.mjs`), and drives it with Chromium.

The suite proves the web app renders and behaves without a device. Every spec is
written so it also runs unchanged against a real device over LAN (T5/HIL).

## Run (T4, host)

```bash
cd tools/webui_harness
npm install
npx playwright install chromium     # one-time
npm test                            # desktop + phone projects
```

Positive marker: Playwright prints `N passed`. The HTML report lands in
`playwright-report/` and screenshots in `screenshots/`.

## Run against a real device (T5/HIL)

The device must be reachable over LAN and you need a valid access token.

```bash
BASE_URL=http://<device-ip> TARGET=device NIMBUS_TOKEN=<token> npx playwright test
```

`TARGET=device` skips the local mock server (the device serves the real page and
real `/api`), and `NIMBUS_TOKEN` is seeded into `localStorage` so the sign-in
gate does not block. Mask the token in any pasted output. This tier needs bench
hardware (Freenove CYD or Nimbus-4) per the lane device-lock protocol; it is not
run in headless CI.

## Files

- `concat.mjs`   - rebuild the page from `include/web_pages.h` fragment order.
- `fixtures.mjs` - default `/api/*` JSON (contracts from N2/N3/N5 are stubs here).
- `server.mjs`   - the mock server (`PORT`, default 8790; serves `/`, `/logo.svg`,
                   `/api/qr`, and default JSON for the `/api/*` surface).
- `tests/`       - the Playwright specs; `_helpers.mjs` has the shared setup.
- `run_qa.sh`    - the lane QA entry point (concat check + full suite).

## Spec coverage (every pane, every feedback state, desktop + phone)

- `00_smoke`            - page loads clean; every destination switches with no JS errors.
- `10_robustness`       - the white-screen floor: the concatenated page raises no thrown
                          error (a syntax error in any fragment fails here), and every pane
                          renders under sparse and empty `/api` payloads (a page must never
                          die on one absent optional field, and never REQUIRE a field the
                          fixtures do not serve - the fixture-drift guard).
- `25_ia`              - five destinations, content per destination, Home sessions, no sideways scroll.
- `31_feedback`        - the feedback helper state machine + button gating + upload success/error.
- `31_sweep`           - acceptance: no async action ends without a visible result state.
- `33_mcp_approval`    - MCP device-server approval card (per CUM-33).
- `45_token_out_of_url`- header-only downloads, legacy ?t= migration hint, ?c= exchange, naming.
- `51_pairing`         - cloud pairing card: high-contrast code, QR from /api/qr, copy, steps.
- `57_chat`            - chat drag-and-drop + attach upload with progress/result.
- `62_search`          - global search palette over all sources, keyboard reachable, grouped.
- `66_onboarding`      - onboarding v2: flip step, Cumulo Nimbus + Z.ai, no e-ink, what-next card.
- `68_updates_storage` - OTA result states + battery gate, files quota caption, typed erase confirm.
- `72_wakeups_safety`  - wake-ups policy + single approval card; Safety subtab downloads policy + guest moderation gates (the retired dead gates are gone).
- `79_setup_network_signin` - Publish Setup Network states the next step (LAN vs setup network, pending, error); the gate's code field is not autocapitalized and a typed code is normalized; while the gate is up the app is hidden and the page does not scroll, and sign-in restores it.
- `90_screenshots`     - archives {desktop,phone}-{home,chat,memory,assistant,device}.png.
- `95_audit_shots`     - render-audit capture of every pane / subtab / state (CUM-214).
- `98_connectivity_states` - the CUM-207 Connectivity + Cloud-access render matrix.

Every capture spec (`90`, `95`, `98`) asserts a pane-distinctive element is VISIBLE before
it screenshots (`assertPane` in `_helpers.mjs`, `#subpane-*` for subtabs, the expanded
group body for `98`). A shot of the wrong pane - the white-screen symptom, where dead page
JS leaves Home showing under a highlighted tab - FAILS instead of being archived as if it
were correct. A screenshot that asserts nothing about its content is not evidence.

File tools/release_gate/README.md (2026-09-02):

# The release gate

A firmware release candidate does not ship until this gate is green. It exists
because of the 2026-08-24 incident day, when a single release put a white screen,
a universal tunnel 502, a rotated touch surface, and reconnect flapping in front
of customers at once. Every one of those failure classes now has a test that
fails on the pre-fix build and passes on the fixed one, so the gate catches the
bug before the release, not the customer after it.

Cost is not a reason to skip a leg. Real flashes, real relay traffic, and a human
looking at the glass are all in scope.

## What each leg catches

| Failure class (2026-08-24) | Gate leg | Where |
|---|---|---|
| White screen, pixels never reach the glass (CUM-167) | driver-pin check + ELF e-paper check + on-hardware render-to-glass with a human glance | `check_driver_pin.py`, `check_elf_symbols.py`, `tests/hil/test_l29_release_gate.py::TestRenderToGlass` |
| Device tunnel serves a 502 for every request (CUM-173) | CLOUDLOOP serves the local page, plus the cloud connected-device-5xx interstitial | `tests/hil/test_l29_release_gate.py::TestTunnelLoopback`, cumulo `e2e/release-gate-tunnel-502.e2e.test.ts` |
| Touch rotated 180 (CUM-160) | injected tap mapping + physical tap under an adversarial flip | `tests/hil/test_l29_release_gate.py::TestTouchCorrectness` |
| Watchdog starvation / tunnel-slot reset (N15) | HANG must trip the task watchdog and reboot | `tests/hil/test_l29_release_gate.py::TestCrashLoopResilience` |
| Reconnect flapping under relay restarts | reconnect-storm resilience | cumulo `e2e/release-gate-reconnect-storm.e2e.test.ts` |
| Bad OTA image boot-loops | OTASIM bad image rolls back within the boot-guard budget | `tests/hil/test_l29_release_gate.py::TestOtaRollback` |
| Panel-heal stops re-arming a slept panel (CUM-231) | past the trust window the panel is re-armed unconditionally; `healthy()` never gates it | `test/test_panel_heal`, `test/test_panel_health` |
| Settings lost across an update (CUM-237) | the OTA flow writes only its own bookkeeping keys, never an owner's Wi-Fi / provider key / touch cal / theme | `check_ota_preserves_nvs.py`, plus the provision -> OTA -> power-cycle -> read-NVS bench leg |
| N7 internal-SRAM win regressed (CUM-24) | the Telegram `tg_poll` TLS staging buffers stay PSRAM pointer handles, not inline internal `.bss` (the ~6.7 KB win merged as 2598499) | `check_sram_staging.py`, `test_sram_staging.py` |

## Running it

Host checks (run in CI, fast):

```
python3 tools/release_gate/run_gate.py --host-only     # exit 1 blocks the release
python3 -m pytest tools/release_gate                   # tests the gate logic itself
python3 tests/release_gate/run_host_legs.py            # one verdict across every host leg
```

`tests/release_gate/run_host_legs.py` aggregates the host unit legs (white-screen,
touch, boot-loop) and the source-guard checks into a single PASS/FAIL, and
`tests/release_gate/MANIFEST.md` maps every failure class to its host or bench leg
with the exact bench procedure.

Full battery (prints the exact hardware and cloud commands to run and paste):

```
python3 tools/release_gate/run_gate.py
```

The hardware legs need the bench and `--allow-hardware`; the render-to-glass and
physical-tap legs end in a recorded human confirmation. The cloud legs run in the
cumulo repo (`pnpm test`, `pnpm e2e`, the browser suite, and the post-deploy
staging smoke).

## Block condition (CUM-174 #6)

Do not cut a release tag or flash client devices until every section printed by
`run_gate.py` is green and pasted into the release record. The host checks fail
the build automatically; the hardware and cloud legs are an explicit checklist so
they cannot be silently skipped.

The driver-pin check passes once the firmware pins a driver off the white-screen
denylist (the tree pins v0.7.2). If a release candidate ever regresses the pin
back onto a denylisted version, the check fails the build - that is the gate doing
its job.

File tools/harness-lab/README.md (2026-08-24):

# harness-lab - run the Nimbus agent on your Mac

A host build of the device's agent harness. The same `TurnEngine`, tool registry,
memory engines and provider adapters the firmware runs, wired to libcurl instead
of `WiFiClientSecure` and to RAM instead of an SD card.

It exists because every harness investigation before it went the same way: change
something, build, flash, wait, watch a 1280-byte log ring wrap, guess. The
`web.search` bug that broke every news briefing had been shipping for weeks and
was found in minutes here - the response is 7–8 KB and the old adapter's buffer
stopped at 6000.

## Why the code under test is the real code

Every provider call, tool call and web search already goes through one injected
seam, `agent::HttpTransport`. The device implements it over TLS sockets; the lab
implements it over libcurl. Nothing above that seam knows the difference, so a
bug reproduced here is a bug on the board.

```
  scenarios / REPL
        |
   agent::TurnEngine          <-- lib/harness   (identical on device)
   tool registry, memory      <-- lib/core      (identical on device)
   provider adapters          <-- lib/harness   (identical on device)
        |
   agent::HttpTransport       <-- THE SEAM
        |
   CurlHttpTransport  |  TlsTransport (WiFiClientSecure)
       (this lab)     |      (the device)
```

**Not** simulated: the LEDs, the panel, Telegram, and the ~46 KB internal
heap. `freeHeap` reports a large value so the device's memory gates never fire.
Anything that depends on memory pressure has to be tested on hardware.

## Build

```bash
cd tools/harness-lab && make
```

Needs libcurl (present on macOS) and an ArduinoJson checkout under `.pio/libdeps`
- run `pio test -e native` once if the build cannot find it.

`make check` compiles without touching the network: run it after harness changes
so the lab cannot quietly rot.

## Keys

Read from the environment first, then a dotenv file (default
the secrets `.env` - `NIMBUS_ENV_FILE`, the same one the HIL suite uses). Nothing is committed.

    OPENAI_API_KEY  ANTHROPIC_API_KEY  MISTRAL_API_KEY  TAVILY_API_KEY

A provider with no key is skipped, not faked.

## Use

```bash
./build/nimbus-lab providers                 # do all three actually answer?
./build/nimbus-lab search "world news"       # web.search end to end
./build/nimbus-lab chat                      # interactive REPL
./build/nimbus-lab scenarios                 # the whole suite
./build/nimbus-lab scenarios memory tool-loop
./build/nimbus-lab list-scenarios
```

Useful flags: `--host=mistral` pins one provider (no failover, so a failure is
attributable), `--model=<id>` overrides its model, `--verbose` echoes every HTTP
exchange and tool call, `--no-tools` disables the agentic loop, `--no-embed`
turns off embeddings.

## The scenarios

These are not smoke tests. "The API returned 200" is exactly the bar that let a
permanently-broken `web.search` ship, so each scenario asserts an outcome.

| scenario | what it proves |
|---|---|
| `web-search` | a live search succeeds AND the model uses what came back |
| `search-errors` | a failing search names its cause instead of saying "no results" |
| `multi-tool` | several tool calls inside one turn, and the side effects landed |
| `memory` | written in one chat, recalled in a different one |
| `memory-ops` | write / search / pin / update / episodic, incl. update replacing rather than duplicating |
| `tool-loop` | a multi-round loop where round 2 depends on round 1's result |
| `continuity` | the chat still remembers three turns later |
| `scheduled` | an unattended routine turn - the news-briefing path |
| `dream` | a quiet consolidation turn is allowed to say nothing |
| `parity` | every keyed provider handles a plain turn and a tool turn |

Scenarios needing a Tavily key **skip loudly**. A silent skip reads as a pass,
which is how a broken capability stays broken.

Real API calls cost real money. The suite reports its token totals; a full run is
roughly 100 K input tokens, dominated by the system prompt on every turn.

## Cost of the fakes

Two things here are host stand-ins, not the device's code, so treat their results
as indicative:

- **File tools** (`lab_files.h`) - the device's `files.*`/`artifact.save` are
  SD-backed and cannot be lifted. The tool *shape* matches and the real
  `FileStore::validSegment` traversal gate is reused, but the bytes live in a
  `std::map`.
- **Episodic store** - `InMemoryEpisodicStore`, not the SD append-log. The
  conversation window is rebuilt per turn from it.

Everything else - the turn engine, prompt composition, the tool loop, provider
wire formats, vector memory, RBAC, `web.search` - is the shipping code.

## Gotchas paid for here

- `LabRig` is header-only, so the Makefile **must** track header dependencies
  (`-MMD -MP`). Without it, editing `lab_rig.h` rebuilds only the `.cpp` files
  that changed, the other translation unit keeps its stale inline definitions,
  and the linker picks one - you end up debugging a fix that is in the source but
  not in the binary.
- Without an `ApplyDeps::principalFor` hook, `whoFor` returns a deny-all
  principal and every memory call comes back *"this conversation isn't approved
  to store memories yet"*. That is the correct fail-safe, and it is what the lab
  reported before the hook was wired - not a device bug.

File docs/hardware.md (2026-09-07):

<!-- audience: dev -->
# Nimbus Hardware Reference

Project-level pinout + wiring for the **Solide S3** board (ESP32-S3-DevKitC-1 N16R8).
The board pin map's source of truth is
`board_solide_s3.h` in the public
[solide-drivers](https://github.com/ristllin/solide-drivers) board-support
repository; the deeper board build/BOM guide is its
[docs/build.md](https://github.com/ristllin/solide-drivers/blob/main/docs/build.md) +
[docs/hardware.md](https://github.com/ristllin/solide-drivers/blob/main/docs/hardware.md).
This page is the Nimbus-side consolidated view.

## Board configurations

A Nimbus device runs in **one of two display configurations**, one per board. The
hand-built **Solide S3** board drives a 2.8" color touchscreen alongside its LED
ring (`screenModel=tft`). The other is an off-the-shelf all-in-one module, the
**Freenove ESP32-S3 Display (CYD)**, that arrives as a single part and runs its
own firmware image.

| Configuration | Display | Input | `screenModel` | Board | Details |
|---|---|---|---|---|---|
| **[Touch TFT](hardware/touch-tft.md)** | 2.8" ILI9341, 240×320 RGB565 | XPT2046 resistive touch | `tft` | `solide_s3` | [→ pinout, wiring, touch cal](hardware/touch-tft.md) |
| **[All-in-one (Freenove CYD)](hardware/all-in-one-cyd.md)** *(lowest effort)* | 2.8" ILI9341, 240×320 capacitive touch | Touch | `tft` | `freenove_s3` | [→ pinout & happy-path build](hardware/all-in-one-cyd.md) |

The Solide S3 pinout:

touch-TFT pinout

The all-in-one has its own complete pinout on its page:
[All-in-one (Freenove CYD)](hardware/all-in-one-cyd.md).

For a hand-built Solide S3 board, `python3 tools/setup_device.py` stores
`scrModel=tft` over UART before production firmware boots, so the board binds its
display and touch drivers on the first boot. It is **hardware identity, not a
preference**: read once at boot to pick the drivers, so a change needs a restart,
and it is exempt from "Revert to Defaults". Surfaced as `scrModel` in `/api/state`
and `scr=` in `STATUS`.

The all-in-one is different: its pinout is a **compile-time identity** chosen by
`SOLIDE_BOARD=freenove_s3` at flash time, and `screenModel` is fixed to `tft`.
There is no display setting to pick, and nothing to wire.

Everything below this section covers the **Solide S3** board. The all-in-one
carries the same peripherals on a different, fixed pinout, covered in full on its
own page.

## First flash of a fresh board: use the UART port

⚠ **The DevKitC-1 has TWO USB-C ports and they are not interchangeable for
flashing.** Getting this wrong on a factory-fresh board looks like a dead board.

| Port (silkscreen) | Goes to | Auto-reset into download mode? |
|---|---|---|
| **UART** | CP2102N bridge → GPIO 43/44, **and DTR/RTS wired to EN + GPIO 0** | **YES - electrical, always works** |
| **USB** | the ESP32-S3's own USB peripheral (GPIO 19/20) | Only while the ROM owns it |

**For the first flash of a fresh board, plug into `UART`.** esptool toggles DTR/RTS,
the auto-reset circuit physically pulls GPIO 0 low and pulses EN, and the chip
enters download mode. **No buttons, and it does not care what firmware is running**,
because the path is electrical rather than software-cooperative. For a
production install, use the guarded installer:

```bash
python3 tools/setup_device.py
```

It lists the UART adapters, requires an explicit choice, reads the selected
board's immutable factory MAC and NVS state, and asks for the fitted display plus
initial operating mode. It then asks you to type the MAC back before any upload.
On a new board a UART-only diagnostic writes and verifies `scrModel` and
`nimbus_mode`; production firmware is installed last. Existing Nimbus settings
produce a prominent warning, and NVS is never erased. Do not run a bare `pio run
... -t upload` with more than one board connected, because PlatformIO may select
a different serial device than the one you intended.

The full flashing guide - the installer in detail, reflashing a running board,
recovery, and which build environment to use - is
[Flash the firmware](quick-start/flash.md).

`[env:provision]` is a standalone serial network diagnostic, not the product
firmware. It does not serve the Nimbus setup network or web settings. If it was
flashed accidentally, run `python3 tools/setup_device.py` to replace it with the
production firmware.

The board appears as a **CP210x** (`10c4:ea60`, `/dev/cu.usbserial-*` or
`/dev/cu.SLAB_USBtoUART`) rather than an Espressif device.

### Why the USB port can leave a fresh board unflashable

The native `USB` port talks to the S3's own USB peripheral. Whoever owns that
peripheral decides whether a reset is possible:

- **ROM owns it** → USB-serial-JTAG (`303a:1001`), and esptool can reset it.
- **An app owns it** (any TinyUSB/Arduino USB-CDC firmware, including the demo
  these kits ship with) → a plain CDC-ACM device such as **`303a:4001`**
  ("Espressif CDC Device"). DTR/RTS are then *virtual*: they do nothing unless
  that app implements a reset handler. The shipped demo does not.

In that state there is **no software path to download mode at all** - verified
against a factory-fresh unit: `--before default-reset`, `--before usb-reset`,
`--before no-reset`, the 1200-baud touch (every DTR/RTS polarity), a libusb bus
reset, and racing esptool against repeated resets all reach `Connecting…` and
never sync.

⚠ A libusb bus reset (`tools/usb_reset.py`) resets the **USB link, not the CPU**.
It is the right tool for a *wedged* CDC on a Nimbus board; it cannot restart the
chip or reach download mode.

⚠ **Do not go hunting with DTR/RTS.** AGENTS.md forbids strobing it on this board
and that is not idle advice - a strobe matrix wedged a board's CDC silent here.

### Once Nimbus is on it

Nimbus also owns the native USB, but its `[env:test]` build has the `REBOOT`
console command and a task watchdog, so it stays reachable and either port works
for reflashing. The UART port remains the guaranteed path if a build ever wedges.

## Shared peripherals

These are present on the **Solide S3** board. The display + touch pins are on the
[Touch TFT](hardware/touch-tft.md) page. The all-in-one carries the same peripherals on
its own fixed pinout - see [All-in-one (Freenove CYD)](hardware/all-in-one-cyd.md).

| Peripheral | Bus | Pins | Rail | Notes |
|---|---|---|---|---|
| **microSD** | SPI2 (FSPI) | CS 10 · MOSI 11 · SCK 12 · MISO 13 | 3.3 V | **MUST be FAT32-formatted** - exFAT (the factory default on >32 GB cards) mounts as `cardType!=0, ok=false`; REFORMAT as FAT32/"MS-DOS (FAT)" before first use (owner-verified fix 2026-07-13). orch `/mem` store. Needs a shared GND (a cold GND joint = `cardType=0`). |
| **LED ring** WS2812B ×45 | RMT | DIN 21 | **5 V** pwr / 3.3 V logic | ~372 mA worst case @ brightness 30 |
| **Speaker** MAX98357A I²S amp | I²S1 (std) | BCLK 7 · LRCLK 8 · DIN 17 | amp **5 V** | Class-D, built-in thermal/over-current protection (V0.1) |
| **Mic** I²S MEMS (INMP441/ICS-43434) | I²S0 (std) | BCLK 15 · WS 18 · SD 16 | **3.3 V only ⚠** | L/R→GND (left slot); VDD/data follow VCC - 5 V damages the S3 |
| **Battery sense** *(optional)* | **ADC1** | **GPIO 4** | - | resistor divider off the pack - see [Battery voltage sampling](#battery-voltage-sampling-how-to-add-it) |

:::caution A warm or hot SD card is an electrical fault
Disconnect power immediately and remove the card. Do not reinsert it while the
device is powered. Formatting and firmware cannot make a card hot: verify the
socket/module orientation and pin numbering, confirm its VDD is **3.3 V (never
5 V)**, check continuity from every ground to system GND, and check that 3.3 V
is not shorted to ground before applying power again. Nimbus runs safely without
the card, using its reduced internal-flash tier.

The SD card uses dedicated **SPI2** pins (`10/11/12/13`). TFT + touch use a
different **SPI3** bus (`42/41/1` plus their selects). They do not share SPI data
lines, but they do share the 3.3 V rail and ground; an SD power fault can therefore
brown out or damage the display even though its bus is separate.
:::

**Reserved (never assign):** 0·45·46 strapping · 19·20 native USB · 43·44 UART0 ·
26–32 flash · **33–37 OCTAL PSRAM** · 48 on-board RGB. **Free spares:** 3 · **4 (battery
sense)** · 5 · 6 · 9. **(18 = I²S mic WS/LRCLK.)**

> **Nimbus V0.1** moves audio to two separate, well-protected breakouts: a **MAX98357A**
> I²S amp + an **INMP441/ICS-43434** I²S MEMS mic (replacing the old combined PDM-mic +
> NS4168 board). Mic RX (I²S0) and speaker TX (I²S1) are independent controllers, so
> record + play run concurrently.

## Power

`USB-C → 2S BMS → 2×18650 (series) → DC-DC → 5 V bus`. The **3.3 V** rail (MCU, display,
SD, audio, mic) is always on; the **5 V** bus (LED ring, amp volume) is switchable - so
the ESP32 + display + SD + input + mic all run on USB alone.

## Battery voltage sampling (how to add it)

The board has **no built-in gauge**. Two options; the firmware supports both behind
build flags (default = `NullMonitor`, i.e. desk-powered, battery UI hidden):

### Option A - resistor divider + ADC  *(implemented, `NIMBUS_HAS_BATTERY_ADC`)*

Cheapest path, no extra chip. **Tap `BAT+` *before* the DC-DC** - the regulated 5 V rail
is flat and tells you nothing about charge. Wire a divider into a **free ADC1 pin**
(GPIO 1–10; Wi-Fi owns ADC2 = GPIO 11–20, which reads garbage while Wi-Fi is up):

```mermaid
flowchart TD
  BAT["2S pack BAT+<br/>6.0–8.4 V"] --- RT["Rtop 220 kΩ"] --- N["divider node"] --- RB["Rbot 100 kΩ"] --- GND["GND"]
  N --- ADC["GPIO 4 (ADC1_CH3)"]
```

- Ratio: (220k+100k)/100k = **÷3.2**, so 8.4 V → 2.63 V, inside the ADC's ~0–3.1 V range.
- Firmware: `AdcBatteryMonitor` (`src/hw/power_battery_adc.cpp`) averages
  `analogReadMilliVolts(GPIO4)`, multiplies by 3.2 → pack mV, divides by the cell count
  (2) → per-cell mV → `liIonPercent()` SoC curve (host-tested).
- An optional divider that is not fitted leaves the ADC pin floating. Firmware
  accepts telemetry only across a broad **2.5–4.5 V/cell** plausibility window;
  outside it the board behaves as desk-powered with no battery gauge. This keeps
  a USB-only fresh board awake instead of mistaking a floating reading for a dead
  pack and entering low-battery sleep during setup.
- Config in [`include/nimbus_config.h`](../include/nimbus_config.h):
  `NIMBUS_BATT_SENSE_PIN 4` · `NIMBUS_BATT_DIVIDER_X100 320` · `NIMBUS_BATT_CELLS 2` ·
  `NIMBUS_BATT_VBUS_PIN -1`. Enable with `-DNIMBUS_HAS_BATTERY_ADC`.
- **Single-cell LiPo instead?** Use a ÷2 divider (e.g. 100k/100k), set
  `NIMBUS_BATT_DIVIDER_X100 200` and `NIMBUS_BATT_CELLS 1`, on any free ADC1 pin.

**LIVE-VERIFIED (2026-07-12)** on the 2S LiitoKala pack: enabled `NIMBUS_HAS_BATTERY_ADC`,
read **7923 mV** = 3962 mV/cell (2S confirmed). ⚠ **The S3 ADC under-reads near full.**
The ÷3.2 node at 8.4 V is **2.625 V - above the ADC's LINEAR region at 11 dB** (accurate
to ~2.45 V, compresses above), so a *truly full* pack reads ~7.9 V → ~72 %, not 100 %.
Consequences baked into the firmware: charge state comes from the
voltage **trend**, NOT absolute voltage (there is **no VBUS pin** - `NIMBUS_BATT_VBUS_PIN
-1` - so `onExternalPower` can only be inferred); a learned/asserted full-charge anchor
(`BATTCAL`) stretches the compressed top band so full reads 100 %. A lower divider (e.g.
÷4, keeping the full-charge node ≤ ~2.1 V) would make the top of the range linear and
remove the need for the calibration - a candidate for the next board rev.

> **⚠ Cautions:** use ADC1 (1–10) not ADC2; keep the divider high-value (≥100 kΩ legs)
> so it barely drains the pack, and never let
> the divider node exceed ~3.3 V. GPIO 3 is a strapping-adjacent pin - GPIO 4/5/6/9 are
> cleaner choices (the board doc designates **4**).

### Option B - I²C fuel gauge  *(stubbed, `NIMBUS_HAS_FUEL_GAUGE`)*

A MAX17048-class gauge (I²C addr 0x36) models SoC in hardware (more accurate, survives
sag). Impl exists at `src/hw/power_fuelgauge.cpp`; wire SDA/SCL to a free I²C-capable
pair + a VBUS-sense pin, set the pins in `nimbus_config.h`, build with
`-DNIMBUS_HAS_FUEL_GAUGE`.

Either monitor feeds the same portable `power::Manager` → the battery header glyph, the
T1 (force the Dark battery mode + Telegram ping) / T2 (flush + deep sleep) thresholds,
and the VBUS→Full battery-mode auto-switch.

## Security note
Web/LAN surfaces are token-gated - see [`security.md`](security.md).

## Battery hardware is web-configurable (v2.10.x, owner 2026-07-17)

Boards differ physically - some have the design **220k/100k** divider (÷3.20), others the
**270k/120k** actually fitted (÷3.25), and packs range from LiitoKala **3500 mAh** to
reclaimed vape/18650 **~500 mAh** cells (always **2S**). These are no longer compile-time:
**Settings → Battery** on the web exposes the two sense resistors + pack capacity, stored in
NVS (`battRtop`/`battRbot`/`battCapMah`) and applied live (ADC re-armed + model capacity
updated on the main task; cells stays compile-time 2S). Defaults equal the old compile
constants, so an un-set board is unchanged.

⚠ This fixed a real on-device bug: the firmware baked in **÷3.20** while the fitted
resistors are **270k/120k = ÷3.25**, so voltage read **~1.6% low** across the range (BATTCAL
masked only the top). Set the true resistors and the raw reading is correct end-to-end; the
`/api/state` `dividerX100` reports the EFFECTIVE ratio the ADC applies (the configured
resistors on a hand-built board, the board's fixed onboard divider on an all-in-one board
whose sense-resistor inputs the web tile hides), so the Battery Lab's host-side correction
tracks it (no double-correction). ⚠ A divider change re-scales every mV, so the
BATTCAL full-anchor goes stale - **re-run Calibrate on a full pack** after changing resistors
(the web UI prompts for this).

## Measured battery reality (curve run #4, Board 2, 2026-07-16)

The first complete full→cutoff drain on real hardware. **5.75 h**, 3940 samples, 25
settle reads, zero thermal trips (die held ~50 °C). Owner-measured ground truths from
a dedicated analyzer: **capacity 3500 mAh**, **full = 8.40 V**. Raw data +
snapshots live with the Battery Lab, its own project at
[ristllin/nimbus-battery-lab](https://github.com/ristllin/nimbus-battery-lab)
(`data/rescue/run4_FINAL_brownout.{json,csv}`).

### What it measured
- **Total system power at LED bright=77/255: 4.21 W** (608 mA average at the pack over
  5.75 h to deliver 3500 mAh). This is the hard number every estimate below is anchored on.
- **Load-model correction k = 0.60**: the datasheet model (`200 + 45·60·b/255`)
  predicted 1015 mA where the truth was 608. Two errors multiply: it returns **5 V-rail**
  mA but is consumed as **pack** mA (a 2S pack behind the buck ⇒ ~1.33×), and the
  per-LED full-white constant (60 mA) is high - the run bounds real white at ~45-50 mA,
  since 45 LEDs × 60 mA @5 V would exceed the *entire* measured system draw.
- **Device base draw ≈ 0.6-1.0 W** (derived, not measured: total 4.21 W minus the
  bounded LED share). ⚠ The one measurement that would collapse this range to a number
  is a drain at **bright=0** - one pack cycle, highest-value next experiment.

### ⚠ Battery life: Dark posture is a VISUAL setting, not a power setting
`Posture::Dark` only stops lighting LEDs. It does not touch Wi-Fi, Bluetooth, or the CPU -
it appears in 4 places, none of them power-domain code. The three battery modes
(Dark / Balanced / Full) are a table of LED/screen/telemetry settings (`profile.cpp`),
not radio or clock decisions.
There is **no power management**: no `esp_light_sleep`, no `esp_pm_configure`, no
`setCpuFrequencyMhz`, `CONFIG_PM_ENABLE` unset, CPU pinned at 240 MHz. The only
`esp_deep_sleep_start()` is the critical-battery give-up path. Modem sleep is on only
because Arduino defaults `WIFI_PS_MIN_MODEM` - never by intent, never tuned.

| Posture | Pack draw | Life on 3500 mAh |
|---|---|---|
| Drain @77/255 (run #4) | 608 mA | **5.75 h** (measured, to cutoff) |
| Ring at 1% (run #7) | 209 mA | **16.7 h** (measured) |
| Dark ≈ Calm ≈ Full-idle | **150 mA (1.11 W)** | **~23 h** (two-point solve) |
| For a **week** | 20.8 mA | ✗ not reachable |
| For a **month** | 4.9 mA | ✗ not reachable |

### The load model is now MEASURED, not derived (run #7, 2026-07-17)

**I(b) = 150 + 5.95·b mA at the pack**, from two measured points - b=77 (run #4, 608 mA
over 5.75 h to real cutoff) and b=10 (run #7, 209 mA over 15.39 h, 73 settle reads).

⚠ **The derived 86-143 mA band MISSED.** The true idle draw is **150 mA (1.11 W)** -
above the top of the estimate, so idle life is **~23 h, not 24-40 h**. The optimistic end
of that table was never real. Quote ~1 day, never "a day and a half".

⚠ **1% ring brightness is NOT ~0.** It draws 60 mA on top of the 150 mA base - **29 % of
total draw**, costing **6.7 h** of runtime (23.4 → 16.7 h). 45 LEDs make "1 %" collective.

**Independent cross-check that passed:** the measured slope implies **~42 mA/LED at full
white** vs the datasheet's 60 - the same over-estimate the k=0.60 capacity correction
found by a completely different route (a measured 3500 mAh vs a two-point current solve).
Two unrelated methods, one conclusion: the datasheet per-LED constant is ~30 % high.

⚠ **Run #7 stopped at a 6000 mV FLOOR, not cutoff** - 281 mAh (8 %) was still in the pack,
so `3500 / runtime` would OVERSTATE the current by 9 % (227 vs 209 mA). The delivered
charge was recovered by reading its final settle voltage off run #4's measured curve. A
floor-stopped run is also barred from the SoC curve (no 0 % anchor). Known bias: run #4's
curve was built at 0.17C and run #7 ran at 0.05C, so its settle reads recover higher and
the curve over-reads its SoC - meaning the true I(10) is a little ABOVE 209 mA, and the
true base a little above 150. The **bright=0 idle-baseline run** (owner-approved) measures
A directly, with no extrapolation and no dependence on run #4's curve.

Dark/Calm/Full-idle are within noise of each other - since Full-idle went fully dark
(owner 2026-07-15), the LEDs were never the idle load; the always-on radios + 240 MHz
CPU are. **A week is not reachable by tuning, and not even by deleting the LEDs**: 45
WS2812Bs draw 0.6-1.0 mA each *with every pixel black* (~19-30 mA at the pack, no load
switch on the LED rail) - the dark strip alone exceeds the whole 20.8 mA week budget.
An S3 at 240 MHz with Wi-Fi associated is ~10× the month budget by itself. A week needs
a MOSFET on the LED rail + light-sleep with duty-cycled wake; a month needs deep sleep
- architecturally incompatible with "Notifier shows live BLE-pushed status".

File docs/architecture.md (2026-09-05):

# Nimbus Architecture

Nimbus is firmware for a battery-capable desk device. It runs on the hand-built
**Solide S3** board (ESP32-S3-DevKitC-1 N16R8) - a 45-LED ring, an I²S microphone
and speaker, and a 2.8" color touchscreen - and on the off-the-shelf
**Freenove ESP32-S3 Display** all-in-one board. Each board ships as its own
firmware image. Every build runs both of the device's two operating modes.

This page is the map: how the code is layered, what each operating mode turns
on, which sibling repositories the project depends on, and how a release
travels from a git tag to a device on someone's desk. It links out rather than
re-explaining - each subsystem has its own document.

## Code layering

The repository is organized as four layers. The rule is strict: **a lower layer
never includes an upper one.**

```mermaid
flowchart TD
  M["main.cpp - wiring + the main loop"] --> S["src/modes · src/agent · src/net<br/>feature subsystems"]
  S --> H["src/hw - Arduino/board glue"]
  H --> C["lib/core - portable logic<br/>(no Arduino, host-tested)"]
  C -. board support .-> SD["solide-drivers<br/>(solide:: drivers, pinned library)"]
  classDef portable fill:#e8f5e9,stroke:#2e7d32;
  class C portable;
```

- **`lib/core`** - portable C++ with no Arduino dependency: the attention
  router and ring planner, the notifier frame codec, the battery model, the
  orchestrator's memory engines and turn contract, fault injection, Wi-Fi
  policy, and more. Everything here runs and is tested on the host
  (`pio test -e native`), which is what keeps the device-independent logic at
  100% coverage without a board on the desk.
- **`src/hw`** - the glue that binds portable logic to real hardware: display
  output, self-test probes, board bring-up.
- **`src/modes` · `src/agent` · `src/net`** - the feature subsystems: the two
  operating modes, the orchestrator agent (providers, memory, Telegram, voice),
  and the network surfaces (web UI, BLE notifier link, OTA).
- **`main.cpp`** - wiring and the main loop only. It owns task startup, the
  boot-time mode decision, and draining request flags from the UI subsystems.

Board support itself lives outside the repo in
[`solide-drivers`](#sibling-repositories), consumed as a pinned library - Nimbus
calls its `solide::` seams (LEDs, display, audio, memory, self-test) and never
forks its internals.

## Two operating modes

At boot the firmware reads one NVS setting (`nimbus_mode`) and becomes one of
two devices. The split is deliberate and total - each mode powers only one
radio, because the ESP32-S3's internal SRAM cannot comfortably host the BLE
stack and the Wi-Fi/TLS stack at once.

| | Notifier | Orchestrator |
|---|---|---|
| Purpose | Status light for your AI coding sessions | A provider-hosted LLM agent (Telegram + voice) |
| Radio | **Bluetooth only** - Wi-Fi stays off | **Wi-Fi only** - Bluetooth stays off |
| Ring is driven by | nsn frames from the host broker | The agent's own sessions and turns |
| Web UI / providers / Telegram | off | on |
| Software update (OTA) | not available in this mode (update over USB, or switch modes) | available |

Switching modes (Settings > Mode on the device, Settings → Mode & identity on
the web page, or the `MODE` console command) persists the setting and restarts
the device. The status language - which colors and motions mean what on the
ring - is [identical in both modes](./modes-and-signals.md).

### Notifier - the broker pipeline

In Notifier mode the ring and screen are driven **only over BLE**. AI coding
harnesses (Claude Code, Codex, and others) report session state through
installed hooks to a broker running on the host; the broker encodes it as nsn
frames and writes them to the device's GATT server. The link is bonded and
encrypted (LE Secure Connections, Just Works) - an unbonded central can connect
but cannot paint the ring.

```mermaid
flowchart LR
  H["AI coding session<br/>(installed hooks)"] --> B["nimbus-notify broker<br/>on the host"]
  B -->|"bonded BLE<br/>(encrypted FRAME writes)"| F["ble_notifier<br/>GATT server on the device"]
  F --> Map["Mapper → attention router<br/>(job table, lib/core)"]
  Map --> R["LED ring (instant)"]
  Map --> E["screen (badge / detail)"]
```

The wire protocol is byte-locked to the reference encoder in the
[`nsnotify`](#sibling-repositories) repository via generated test vectors, so
the broker and the device codec cannot drift apart. Details:
[notifier status language](./notifier-status-language.md) and
[modes & signals](./modes-and-signals.md).

### Orchestrator - the connected agent

In Orchestrator mode the device joins Wi-Fi and becomes a small self-contained
agent host:

- **LLM turns** against OpenAI, Anthropic, or Mistral, with structured outputs
  and a bounded multi-round tool loop ([provider wire](./provider-wire.md),
  [turn anatomy](./turn-anatomy.md)).
- **The World memory system** - vector recall, episodic history, scratchpad
  goals - tiered across PSRAM, SD card, and flash
  ([Orchestrator World](./orchestrator-world.md),
  [storage tiering](./orchestrator-storage.md)).
- **Telegram** as the conversation channel, including voice notes, photos, and
  per-person roles and quotas ([people and privacy](./people-and-privacy.md)).
- **Voice** - hold-to-talk on the device, speech-to-text and text-to-speech
  through the configured provider.
- **The web UI** - a token-gated control surface served from the device itself
  (provider keys, routing, memory dashboard, routines, settings).
- **Routines** - scheduled recurring turns (morning digests, reminders).

## Two display configurations, two boards

Nimbus supports two display configurations across two boards. The hand-built
Solide S3 drives a 2.8" color touchscreen alongside its LED ring; the off-the-shelf
Freenove CYD is an all-in-one module with its own capacitive touch panel:

| Configuration | Board | Display | Input |
|---|---|---|---|
| **Touch TFT** | Solide S3 | 2.8" ILI9341, 240×320 color | XPT2046 resistive touch |
| **All-in-one (Freenove CYD)** | Freenove ESP32-S3 Display | 2.8" ILI9341, 240×320 color | FT6336U capacitive touch |

Each board's pinout is a compile-time identity fixed by `SOLIDE_BOARD`, so each is
a separate firmware image. The display setting `scrModel` is fixed to `tft`; its
legacy `eink` value is no longer supported (a board carrying it boots an
unsupported-display notice). Above the driver seam the firmware is
configuration-blind; screens are composed once and rendered by whichever panel is
bound. Pinouts and wiring: [hardware reference](./hardware.md).

## Sibling repositories

Nimbus deliberately keeps three concerns in separate repositories and consumes
each through a narrow seam:

| Repository | What it is | How Nimbus consumes it |
|---|---|---|
| [`solide-drivers`](https://github.com/ristllin/solide-drivers) (public) | Board support - the `solide::` drivers for the Solide S3 (LEDs, displays, audio, SD, NVS), plus the board-level build/BOM docs | Pinned library dependency in `platformio.ini` (a sibling checkout or the public git URL); its self-test console example is the hardware acceptance gate |
| [`nsnotify`](https://github.com/ristllin/nimbus-notify) (public) | The nsn wire protocol and the host-side broker, published on PyPI as **`nimbus-notify`** | The reference encoder generates test vectors that byte-lock the device codec; users `pip install nimbus-notify` to run the broker |
| `nimbus-fw-releases` (public) | Signed firmware releases | Devices poll it for updates - see below |

Releases are published to the dedicated `nimbus-fw-releases` repository
because devices download updates unauthenticated - the delivery channel stays
a clean, assets-only repository.

## How a release ships

Firmware updates are signed, published to the public releases repository, and
installed over the air with one click - with an automatic safety net if a bad
image ships. The full design is in [OTA updates](./ota.md); the operator
runbook is maintainer-internal.

```mermaid
sequenceDiagram
  participant Dev as Maintainer
  participant CI as GitHub Actions
  participant Rel as nimbus-fw-releases (public)
  participant Nim as Device

  Dev->>CI: push tag vX.Y.Z
  CI->>CI: build firmware, sign the manifest (ECDSA)
  CI->>Rel: publish signed binaries + manifest
  Nim->>Rel: daily poll of releases/latest
  Nim-->>Nim: update available - owner installs<br/>(web UI, device menu, or Telegram /update)
  Nim->>Rel: download + verify signature
  Nim->>Nim: write the inactive A/B slot, restart
  Note over Nim: a failing image self-reverts<br/>after 3 boots (boot guard)
```

Key properties:

- **Signed end to end.** CI signs the release manifest with a private key held
  as a repository secret; the matching public key is compiled into the
  firmware, so a device only installs what CI produced.
- **A/B slots + boot guard.** The update writes the inactive partition; if the
  new image fails to prove itself within 3 boots, the device reverts to the
  previous one on its own.
- **Owner-approved.** Devices check daily but install only on an explicit
  action - from the web UI, the device's Settings menu, or the Telegram
  `/update` command.
- **Orchestrator mode only.** In Notifier mode the Bluetooth stack occupies the
  memory the update needs, so a Notifier device updates over USB or by
  switching modes first.

## Where to go next

- [Modes & signals](./modes-and-signals.md) - every user-facing knob and what it changes
- [Hardware reference](./hardware.md) - pinouts, wiring, first-flash guidance
- [Orchestrator World](./orchestrator-world.md) - the agent's memory and control surface
- [Security](./security.md) - the auth model and open items

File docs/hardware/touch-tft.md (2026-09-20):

# Configuration A - Touch TFT (`screenModel = tft`)

The hand-built Solide S3 build: a 2.8" **ILI9341** 240×320 color TFT with an
**XPT2046** resistive touch controller. The display and touch controller share the
board's SPI3 pads, and the touch layer is the only input.

For everything common to both boards - first flash, power, battery sensing, the
shared peripherals (SD, LED ring, speaker, mic) - see the
[hardware reference](../hardware.md). This page covers only the touch-TFT build.

## Pinout

Nimbus touch-TFT pinout & peripherals

*(Open [`diagrams/pinout-tft.svg`](diagrams/pinout-tft.svg) for the full-size drawing.)*

## Assembly-critical: the three touch-to-display jumpers

The XPT2046 touch header is **not wired to three additional ESP32 GPIOs**. Solder
three short jumpers on the TFT module so touch and display share the same SPI bus:

| Touch pad | Jumper to display pad | Shared ESP32 net |
|---|---|---|
| `T_CLK` | `SCK` | GPIO 42 - SPI clock |
| `T_DIN` | `SDI` | GPIO 41 - SPI MOSI |
| `T_DO` | `SDO` | GPIO 1 - SPI MISO |

These are physical pad-to-pad connections on the module, not three more wires to
the DevKit. Connect `T_CS` separately to **GPIO 48**. Leave `T_IRQ` **unconnected**;
Nimbus polls the touch controller.

⚠ **Construction/debug check:** with all power disconnected, use continuity mode
to verify all three pairs above. The ESP32 bus wire may land on either pad in a
pair, but both pads must be electrically common. If the bus wires land on the
touch-side pads, missing bridges can leave the **display completely blank**. If
they land on the display-side pads, the display may draw while touch is dead and
shared-MISO diagnostics fail. Also verify `T_CS→GPIO 48` and confirm that `T_IRQ`
has not accidentally been connected to GPIO 48.

## Wiring

| ESP32 GPIO | Net | Module pins |
|---|---|---|
| 42 | SPI clock | SCK **+ T_CLK** |
| 41 | SPI MOSI | SDI **+ T_DIN** |
| 1 | SPI MISO | SDO **+ T_DO** |
| 40 | display D/C | DC |
| 39 | display reset | RESET |
| 38 | display CS | CS |
| 48 | touch CS | T_CS |
| 2 | backlight (PWM) | LED |
| - | *not connected* | T_IRQ |
| 3V3 / GND | power | VCC / GND |

The three on-module bridges above make display and touch one SPI bus with two chip
selects, which is what fits the whole panel into seven GPIOs.

⚠ **Reachable GPIOs are nearly all consumed.** Only the **J3** header is reachable on
the carrier, and GPIO 35/36/37 (OCTAL PSRAM) sit in the middle of it - so the longest
usable contiguous run is seven pins (`1, 2, 42, 41, 40, 39, 38`), all consumed by the
panel. The documented free spares (3/5/6/9) are all on **J1**, which the carrier does
not break out. On this variant **GPIO 47** is the only genuinely free reachable pin.

⚠ **The touch controller is slow.** XPT2046 tops out near 2 MHz against the panel's
40 MHz, so each device gets its own SPI transaction settings. Getting this wrong does
not fail loudly - it returns plausible-looking garbage coordinates.

⚠ **The backlight is a continuous draw.** It is on a PWM pin so the idle path
*blanks* it rather than drawing a screensaver - on a TFT, drawing a screensaver costs
more power than showing nothing.

⚠ **`panelBacklight` is the requested duty, not proof of a lit glass.** The
backlight LED is powered from the module's own VCC through an on-module low-side
switch driven by an active-high ~2.6 mA GPIO2 base drive, so the firmware only
ever sets and reads back the *requested* duty (`panelBacklight`); it has no pad
readback of the actual LED current. `panelBlOk` says the PWM attached, not that
the glass is lit. A genuinely lit screen is confirmed only by a human looking at
it or, for "is the controller even there", by the controller readback
(`panelResponding` / `TFTHEALTH?`). Likewise the boot line
`[tft] colour touch panel up` is an init-sent message printed after `begin()`
returned, not a readback of the live panel - it says the driver started, nothing
about the glass.

⚠ **The microSD is not on this SPI bus.** It uses dedicated SPI2 GPIOs
`CS 10 · MOSI 11 · SCK 12 · MISO 13`; TFT + touch use SPI3 above. The two
peripherals share only 3.3 V and ground. A hot SD card is nevertheless relevant
to a dead TFT because a miswired/shorted SD socket can collapse or damage that
common rail. Power down immediately and follow the
[hot-card safety check](../hardware.md#shared-peripherals); do not diagnose a hot
card by changing display settings.

Bring-up sketch (panel, colors, backlight, raw touch, decoupled from the firmware):

:::caution This replaces the Nimbus firmware
`tftbringup` is a bare panel diagnostic - color bars, a backlight fade, and
touch paint. It has no UI, no Wi-Fi, and no setup network. Normal setup never
needs it; flash it only to isolate a wiring or panel fault. To return to
Nimbus afterward, run `python3 tools/setup_device.py` (saved settings are
preserved). See [Flash the firmware](../quick-start/flash.md).
:::

```bash
pio run -e tftbringup -t upload
```

## What it looks like

Captured from the device with `GET /api/screenshot` - the bytes actually on the
glass (the dirty-gate snapshot, not a re-render), rendered by
`python3 tools/tftpreview.py render`:

| status (idle) | live sessions | settings | value editor |
|---|---|---|---|
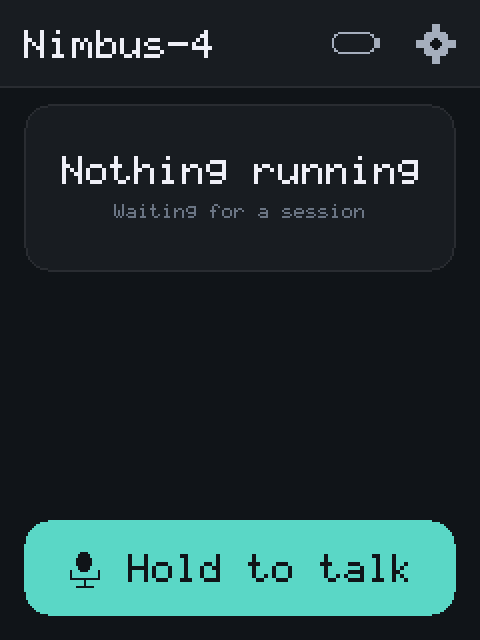
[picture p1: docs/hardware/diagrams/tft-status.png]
status
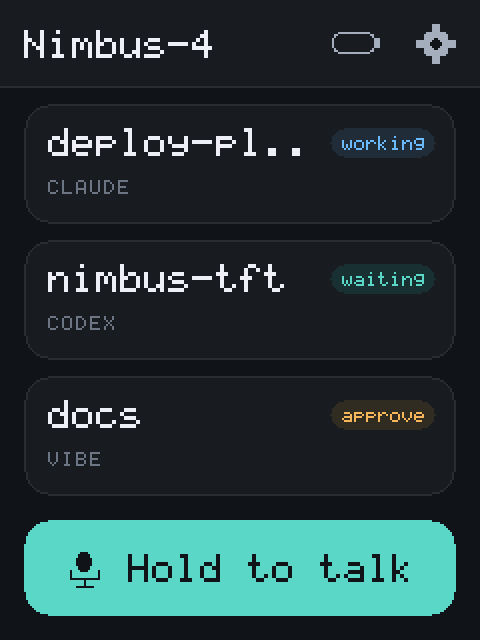
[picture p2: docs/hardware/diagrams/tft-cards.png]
sessions
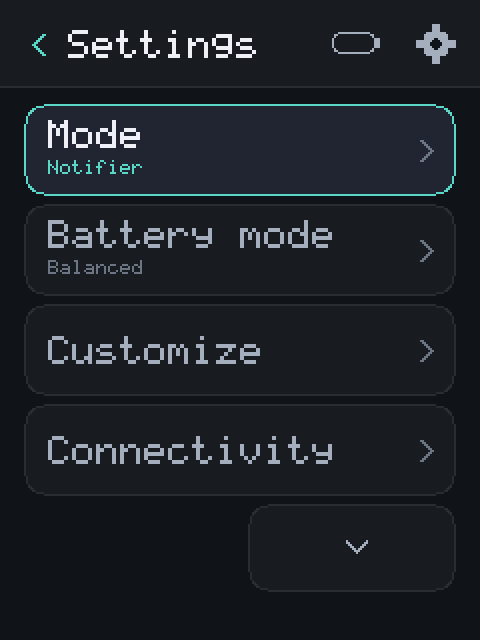
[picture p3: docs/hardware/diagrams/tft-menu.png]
menu
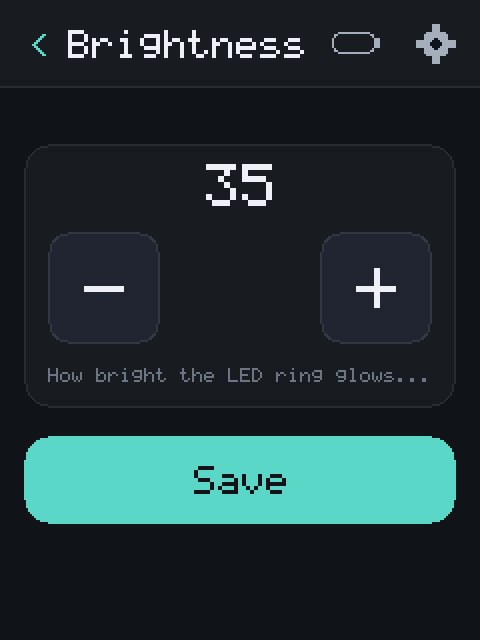
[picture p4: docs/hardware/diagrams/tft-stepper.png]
stepper
|  |  |  |  |

The "live sessions" shot is a real nsn frame, encoded by the broker's own
reference encoder (`notify/broker/frame.py` in [nimbus-notify](https://github.com/ristllin/nimbus-notify)) and fed through the
same decoder → mapper → attention-router path a broker's Bluetooth frame takes.
Each card carries the session title and harness from the v2 wire fields, and the
status pill takes its tone from `statusStyle()` - the same roles that color the
LED ring, so the screen and the ring cannot disagree.

That endpoint exists because every other check of this UI is indirect: host
goldens prove the rasterizer agrees with itself, and `RENDER?` only names the
screen. Neither can catch a panel showing the wrong thing. Three real layout
defects were found this way and fixed - a doubled chevron; a value clipped to
"Battery .."; a title clipped to "Settings .." (a breadcrumb is most specific at
its TAIL, so it is now trimmed head-first and "Brightness" survives); and legacy
text-cursor decorations ("[ 30 ]", "< Back", "< 30 >") leaking onto a panel that
has real buttons instead.

The value editor's [-] and [+] were driven on hardware: 30 -> 35 -> 40 -> 35.

## Touch calibration

Every resistive panel reads slightly differently, so the raw-count-to-pixel
mapping is **measured per unit**, not assumed. Until it is set, a wrong guess is
indistinguishable from broken touch - taps simply land somewhere else.

**First run does it for you, first.** Because a resistive panel drifts unit to unit,
a freshly flashed Touch TFT lands taps only approximately on the board's default
mapping, so on first boot the device goes straight to calibration: the four corner
targets appear and are the only thing the screen responds to until you finish. Tap the
four corners and it stores the result and moves on to the normal setup. This comes
first on purpose, so uncalibrated taps can never drive the menus by mistake. If you
would rather skip it for now, press and hold anywhere for a few seconds (a short
countdown confirms it); a stray tap never skips. You can always redo or clear it below.
The all-in-one (Freenove CYD) is capacitive and reports pixel coordinates directly,
so it needs no calibration and skips this step entirely.

**On the device, no computer needed.** Open **Settings > Display > Calibrate
touch** and tap the four corner targets as they appear. The device derives the
ranges and orientation, applies them right away, and stores them. This is the
same measurement the wizard below does, driven from the panel itself. Clearing
the calibration (Web: leave the Touch calibration field empty) restores the
board's default orientation.

The wizard path, from a computer - press the four corners when prompted and it
derives the ranges and the orientation flags, applies them, and then lets you tap
around to confirm the pixel matches where you pressed:

```bash
python3 tools/tcal_wizard.py --port /dev/cu.usbserial-XXXX
```

It needs an `[env:test]`-family build (it drives the `TOUCH?`/`TCAL` console) and
takes `--dry-run` to print the calibration without storing it. Orientation is
measured, never assumed: a panel can be mounted in any of eight orientations, so
which raw axis carries screen X is decided by which one moves when only screen X
changes. `tools/test_tcal_wizard.py` round-trips all eight.

By hand, if you prefer:

1. Run the bring-up sketch (or `TOUCH?` on a `[env:test]` build) and note the raw
   values at each corner of the panel.
2. Store them as `minX,maxX,minY,maxY` - optionally a fifth flags number
   (**1** swap X/Y, **2** flip X, **4** flip Y; add them together):
   - **Web**: Settings → Mode & identity → Touch calibration
   - **Console**: `TCAL 200,3900,240,3850,4` (bare `TCAL` prints the current value)

⚠ The ranges describe whichever **raw** axis ends up carrying screen X *after* the
swap - the driver swaps first, then maps, then inverts - so the swap has to be
settled before the numbers mean anything.

Both surfaces share one validator, applied immediately and persisted to NVS, so a
calibration survives a restart and never needs a rebuild. Blank restores the
driver defaults.
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

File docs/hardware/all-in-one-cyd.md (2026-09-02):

# Configuration B - all-in-one (Freenove CYD, `screenModel = tft`)

The lowest-effort way to run Nimbus: a single off-the-shelf module with the
screen, touch, microSD, mic, speaker, and an RGB LED already on one board. There
is nothing to wire and nothing to solder. Buy one part, plug in USB-C, flash, and
it is a Nimbus.

The board is the **Freenove ESP32-S3 Display**, model **FNK0104B** (Amazon
`B0FSQF6FKN`): a 2.8" **ILI9341** 240×320 IPS **capacitive** touchscreen, an
**ESP32-S3 N16R8** (16 MB flash, 8 MB PSRAM), on-board microSD, mic and speaker
through an **ES8311** codec, a single WS2812 RGB LED, and USB-C. It runs the same
firmware as the hand-built boards, selected at flash time by
`SOLIDE_BOARD=freenove_s3`, and reports `screenModel = tft`.

This board is a **compile-time identity**: its pinout ships baked into a dedicated
firmware image, so there is no display setting to choose and no risk of a
mis-selected pin map. The Freenove comes in more than one panel size, and each
size is its own firmware image compiled at that panel's resolution (see
[Supported panels](#supported-panels)). For the hand-built boards and everything
shared across the lineup (power, battery sensing, the operating modes), see the
[hardware reference](../hardware.md).

## Supported panels

The Freenove all-in-one ships in three panel sizes. The UI renderer is
parameterized by resolution, so one code path draws every size; each size is a
separate OTA type and firmware image so a board is only ever offered an image
that matches its glass.

| Size | Panel | Resolution | OTA type | Firmware env | Verification |
|---|---|---|---|---|---|
| 2.8" | ILI9341 | 320×240 | `freenove-28` | `esp32s3-cyd` | **Hardware-verified** - display first-light and touch validated on the bench board. |
| 3.5" | ILI9488 | 480×320 | `freenove-35` | `esp32s3-cyd-35` | **Host-verified only** - renderer, goldens, and firmware image proven on the host; no panel owned. |
| 4.0" | 480×480 class | 480×480 | `freenove-40` | `esp32s3-cyd-40` | **Host-verified only** - renderer, goldens, and firmware image proven on the host; no panel owned. |

**What "host-verified only" means.** The firmware for the 3.5" and 4.0" sizes
compiles, links, and passes its own per-size golden framebuffers
(`test/golden_tft/480x320/`, `test/golden_tft/480x480/`), so the layout is proven
to reflow correctly at those resolutions. It has **not** run on a physical 3.5" or
4.0" panel, and the `solide-drivers` display driver still initializes the 2.8"
geometry - so bringing a larger panel up on hardware needs the matching driver
init (panel controller, resolution, orientation) added when a panel is in hand.
The resolution assumed for each size is the standard for that panel class and is
confirmed against hardware before any device-verified claim is made. Release notes
carry the same host-verified labels.

## Happy path - buy one, flash, done

1. **Buy the module.** One part: the Freenove ESP32-S3 Display 2.8" (FNK0104B),
   about $20-25. Nothing else is required for a desk-powered unit. See the
   [bill of materials](bom.md#configuration-b---all-in-one-freenove-cyd).
2. **Plug in USB-C.** Connect the board to your computer with a data-capable
   USB-C cable. The board has a single USB-C port, so there is no wrong port to
   pick.
3. **Flash the firmware.** Use the browser flasher (any Chromium-based browser,
   nothing to install) or the command-line path, and choose the all-in-one
   (Freenove) build. Full steps: [Flash the firmware](../quick-start/flash.md).
4. **Set it up.** The device brings up its setup network on first boot. Follow
   [Set up the device](../quick-start/setup-wizard.md) to join Wi-Fi and, for
   Orchestrator mode, add a provider key.

That is the whole build. Touch is capacitive and self-calibrating, so there is no
touch calibration step, and there is nothing to wire.
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

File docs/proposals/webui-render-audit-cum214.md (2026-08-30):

# Web app render-audit (CUM-214)

Status: findings for owner review. One fix landed (the Safety checkbox exemplar);
everything else is a proposal, not a change. Taste calls are the owner's to rule.

## Why this exists

Pages were snapshot-tested for byte regressions, never looked at the way a person
sees them. A byte-diff passes even when the snapshot itself encodes a wrong layout,
which is exactly how the Safety tab shipped with centered checkboxes. This audit
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

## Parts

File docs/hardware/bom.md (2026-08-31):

# Bill of materials

Every part needed to build a Nimbus, consolidated across the display
configurations, with sourcing links and rough prices. One is hand-built on the
Solide S3 board; the other (Configuration B) is a single off-the-shelf all-in-one
module with nothing to source beyond the board itself. The modules are all
commodity parts - the links below are stable store or search links; any
listing matching the **Module / chip** column works.

Deeper board-level detail (the carrier PCB, per-pin wiring rationale) lives in
the board-support repository:
[solide-drivers](https://github.com/ristllin/solide-drivers) -
see its `docs/build.md` and `docs/hardware.md`.

Prices are approximate 2026 street prices in USD for AliExpress-class
sourcing, excluding shipping. Sourcing the branded parts from a US distributor
(Adafruit, SparkFun, DigiKey, Mouser) typically adds $15–25 to the total.

## Solide S3 build parts

| Qty | Part | Module / chip | Notes | Purchase | ~Price |
|---|---|---|---|---|---|
| 1 | Dev board | **ESP32-S3-DevKitC-1 N16R8** | 16 MB QIO flash, 8 MB octal PSRAM. The **N16R8** variant specifically - octal PSRAM occupies GPIO 33–37. Espressif's official store sells on AliExpress; also at [Mouser](https://www.mouser.com/c/?q=ESP32-S3-DevKitC-1-N16R8)/DigiKey. | [AliExpress](https://www.aliexpress.com/w/wholesale-esp32-s3-devkitc-1-n16r8.html) | $12 |
| 1 | Carrier PCB | **Custom Nimbus carrier PCB** *(recommended; optional)* | Sockets the DevKit and every module on one board instead of hand-wiring. Order the [`hardware/fab/`](https://github.com/ristllin/Nimbus/tree/main/hardware/fab) Gerbers from a board house ([how to order](https://github.com/ristllin/Nimbus/tree/main/hardware/fab#ordering-the-pcb)); hand-wiring on protoboard also works. | JLCPCB (Gerbers in repo) | $2–10 |
| 1 set | Headers | **2.54 mm female pin headers** | Socket the DevKit and modules onto the carrier PCB so each stays removable. | [AliExpress](https://www.aliexpress.com/w/wholesale-2.54mm-female-pin-header-kit.html) | $2 |
| 1 | LED ring | **WS2812B ring, 45 pixels** | Addressable RGB; 5 V power, 3.3 V logic. | [AliExpress](https://www.aliexpress.com/w/wholesale-ws2812b-led-ring.html) | $6 |
| 1 | Amp | **MAX98357A I²S amplifier** breakout | Class-D, built-in thermal and over-current protection. | [Adafruit 3006](https://www.adafruit.com/product/3006) · [AliExpress](https://www.aliexpress.com/w/wholesale-max98357a.html) | $2–6 |
| 1 | Speaker | **4 Ω · 3 W · ~40 mm** | The standard MAX98357A pairing. Any small 4 Ω 3 W full-range driver (28–45 mm) works. | [AliExpress](https://www.aliexpress.com/w/wholesale-40mm-4ohm-3w-speaker.html) | $2 |
| 1 | Mic | **INMP441** or **ICS-43434** I²S MEMS mic breakout | Separate breakout from the amp. **3.3 V only** - 5 V damages the S3. | [AliExpress](https://www.aliexpress.com/w/wholesale-inmp441-i2s.html) | $2 |
| 1 | Storage | **microSD module (SPI)** | 3.3 V SPI breakout. | [AliExpress](https://www.aliexpress.com/w/wholesale-micro-sd-card-module-spi.html) | $1 |
| 1 | microSD card | 16–32 GB | Must be formatted **FAT32** - over-32 GB cards ship exFAT and will not mount without a reformat. | any brand-name card | $5 |
| 2 | Cells | **18650 Li-ion** | Wired in **series** (2S). Buy brand-name cells from a reputable vendor - see the safety note below. Reference pack: owner-measured 3500 mAh, 8.40 V full. | [18650batterystore.com](https://www.18650batterystore.com/) · local vendor | $12 |
| 1 | Charger/protection | **2S BMS with USB-C charging** | Protection + balance + charging in one module. | [AliExpress](https://www.aliexpress.com/w/wholesale-2s-bms-usb-c-charging-board.html) | $3 |
| 1 | Regulator | **DC-DC buck converter → 5 V** | From the 2S pack (~6.0–8.4 V) to a clean 5 V bus, ≥2 A. | [AliExpress](https://www.aliexpress.com/w/wholesale-dc-dc-buck-converter-5v-3a.html) | $2 |
| 1 each | Battery sense | 220 kΩ + 100 kΩ resistors | Optional but recommended - the pack-voltage divider on GPIO 4. | any electronics supplier · [AliExpress kit](https://www.aliexpress.com/w/wholesale-resistor-kit-metal-film.html) | $1 |
| - | Misc | wire, protoboard/PCB, JST connectors; optional 330 Ω resistor (LED DIN) and 1000 µF capacitor (ring 5 V/GND) | The resistor and capacitor improve LED reliability on long runs. | [AliExpress](https://www.aliexpress.com/w/wholesale-jst-connector-kit-protoboard.html) | $5 |

**Shared subtotal: ≈ $55–67** (electronics only; enclosure, fasteners, and
pack-build consumables are listed separately below).

## Configuration A - Touch TFT

| Qty | Part | Module / chip | Notes | Purchase | ~Price |
|---|---|---|---|---|---|
| 1 | Display | **2.8" ILI9341 SPI TFT, 240×320**, with **XPT2046** resistive touch | The common SPI module with display pads (SCK/SDI/SDO/DC/RESET/CS/LED) plus a touch header (T_CLK/T_DIN/T_DO/T_CS/T_IRQ). Three on-module solder bridges are required - see the [build guide](build-tft.md#the-three-on-module-solder-bridges-do-this-first). | [AliExpress](https://www.aliexpress.com/w/wholesale-2.8-ili9341-spi-touch-xpt2046.html) | $8 |

The touch layer is the input.

**Configuration A total: ≈ $59–63** · [Build guide →](build-tft.md)

## Configuration B - all-in-one (Freenove CYD)

The lowest-effort build: **one part, nothing to wire**. The screen, capacitive
touch, microSD, mic, speaker, and RGB LED are all on the module. None of the
shared parts above are needed - no separate display, LED ring, mic, amp, speaker,
SD module, carrier PCB, headers, or battery section for a desk-powered unit.

| Qty | Part | Module / chip | Notes | Purchase | ~Price |
|---|---|---|---|---|---|
| 1 | All-in-one board | **Freenove ESP32-S3 Display 2.8" (FNK0104B)** | ESP32-S3 N16R8, 2.8" ILI9341 240×320 IPS capacitive touchscreen, on-board microSD, ES8311 mic + speaker, single RGB LED, USB-C. Runs the Nimbus firmware built for `SOLIDE_BOARD=freenove_s3`. | [Amazon B0FSQF6FKN](https://www.amazon.com/dp/B0FSQF6FKN) · [Freenove](https://freenove.com/) | $20–25 |

Nothing else is required. A data-capable **USB-C cable** for flashing is the only
other thing you need, and most people already have one.

**Configuration B total: ≈ $20–25** · [Pinout & happy-path build →](all-in-one-cyd.md)

## Safety note - 2S Li-ion

Two 18650 cells in series hold real energy. Buy brand-name cells from a
reputable vendor (counterfeits are common), always keep the **2S BMS** between
the cells and everything else, never charge the pack outside the BMS, tie
every ground together, and stop immediately if anything gets warm that
shouldn't (a hot SD card or module is an electrical fault - power off first,
debug second). The firmware caps LED brightness at 60%: sustained higher
levels have been tested and can overheat and damage internal electronics.
Do not raise this limit.

## Enclosure, fasteners, and assembly consumables

The physical-build extras beyond the electronics - what turns a pile of modules
into a finished unit. A 3D printer and a soldering iron are assumed; quantities
are approximate. The [build photos](build-photos.md) show every step.

| Qty | Part | Notes | Purchase | ~Price |
|---|---|---|---|---|
| 1 set | **3D-printed enclosure** | Print [`nimbus_classic_case.stl`](https://github.com/ristllin/Nimbus/blob/main/hardware/fab/nimbus_classic_case.stl) (GitHub renders it in a 3D viewer) in PLA or PETG. | self-print or a print service | $0–15 |
| ~10 | **M3 brass heat-set inserts** | Melted into the printed case with a soldering iron; screws thread into these. | [AliExpress](https://www.aliexpress.com/w/wholesale-m3-heat-set-insert.html) | $5 |
| assorted | **M3 machine screws** | A short-length assortment, plus a few **longer M3** screws for the microSD-module standoff. | [AliExpress](https://www.aliexpress.com/w/wholesale-m3-screw-assortment-kit.html) | $3 |
| 1 | **Rocker power switch** (SPST) | Cuts the pack to the DC-DC. Generic, ~20 x 12 mm panel cutout. | [AliExpress](https://www.aliexpress.com/w/wholesale-kcd1-rocker-switch.html) | $1 |
| - | **2S pack build materials** | The reference build spot-welds **nickel strip** to the cells (needs a spot welder), insulates with **fishpaper** + **Kapton tape**, and finishes the leads with spade/terminal connectors and silicone hookup wire. **No spot welder?** Use pre-tabbed cells you solder, or a **2S 18650 holder with leads** - see the battery section of the [build guide](build-tft.md#battery-sense-optional-recommended). | [AliExpress](https://www.aliexpress.com/w/wholesale-18650-nickel-strip-fishpaper-kapton.html) | $3–8 |

**Enclosure + consumables subtotal: ≈ $12–35.** Mostly one-time: a spot welder,
if you choose to buy one rather than use tabbed cells or a holder, is extra and
reusable.

The [`hardware/fab/`](https://github.com/ristllin/Nimbus/tree/main/hardware/fab)
folder also holds the carrier-PCB manufacturing outputs (Gerbers, ODB++) and
[how to order the board](https://github.com/ristllin/Nimbus/tree/main/hardware/fab#ordering-the-pcb).

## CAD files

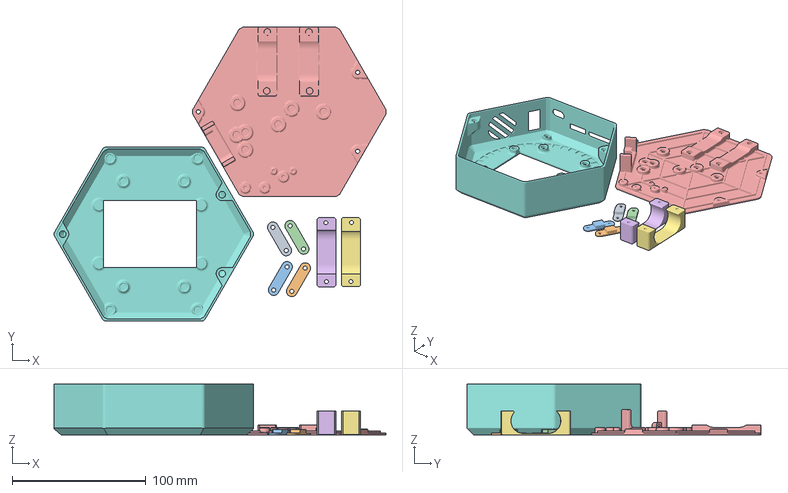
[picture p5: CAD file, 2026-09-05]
hardware/fab/nimbus_classic_case.3mf
248.1 x 219.9 x 38.0 mm
case touch_screen_2_colors.stl_2
case touch_screen_2_colors.stl_3
case touch_screen_2_colors.stl_4
case touch_screen_2_colors.stl_5
case touch_screen_2_colors.stl_6
case touch_screen_2_colors.stl_7
case touch_screen_2_colors.stl_8
Assembly

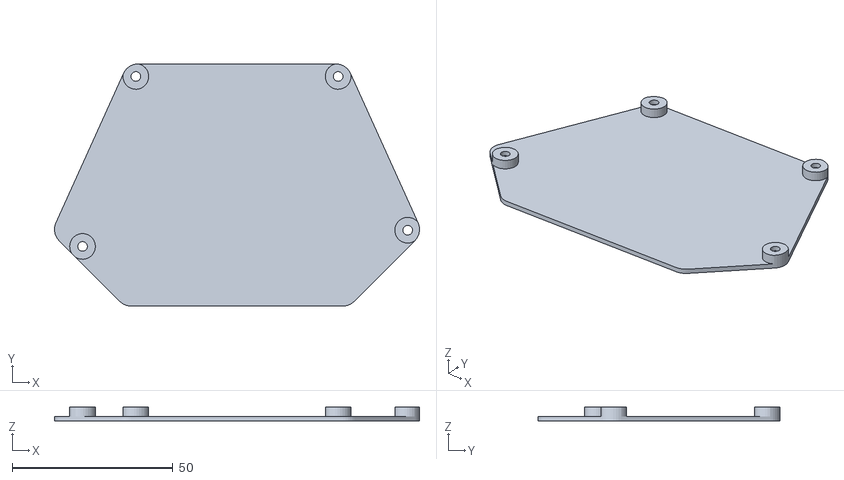
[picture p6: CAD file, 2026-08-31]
hardware/fab/nimbus_light_back.stl
113.5 x 75.3 x 4.50

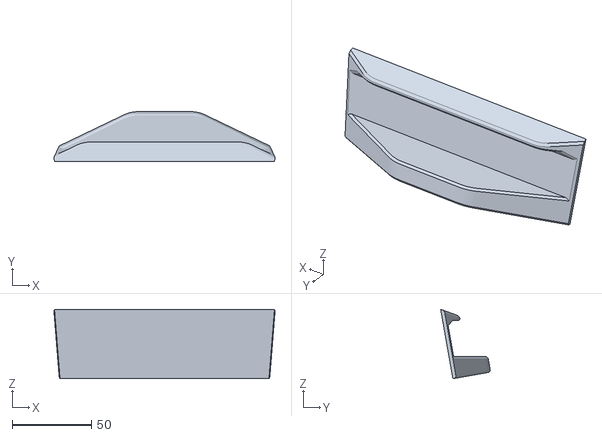
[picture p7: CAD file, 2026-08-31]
hardware/fab/nimbus_light_stand.stl
139.0 x 31.3 x 43.7

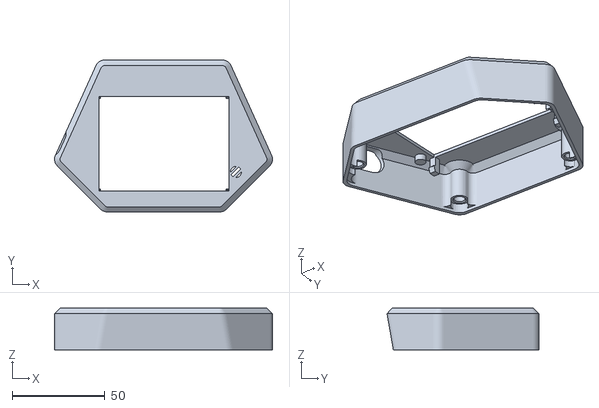
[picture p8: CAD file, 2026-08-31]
hardware/fab/nimbus_light_front.stl
117.3 x 81.8 x 22.5

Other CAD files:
hardware/fab/nimbus_classic_case.stl

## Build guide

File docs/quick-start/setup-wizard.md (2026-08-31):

# Set up the device

From first power-on to a configured device: join the setup network, walk the
onboarding wizard, land on the dashboard. About ten minutes; no serial console.

The whole flow at a glance - every step is detailed in the sections below.
On a touchscreen board the device shuts its setup hotspot down once it is on
your Wi-Fi and the wizard follows it to the new address automatically:

```mermaid
sequenceDiagram
  actor You as Your phone / laptop
  participant Dev as Nimbus
  participant LAN as Home Wi-Fi

  Note over Dev: first boot after flashing
  Dev->>Dev: broadcast setup network "Nimbus-setup"<br/>show its name + sign-in QR on the panel
  You->>Dev: join Nimbus-setup (password shown on the device screen)
  You->>Dev: captive page opens → http://192.168.4.1<br/>(already signed in - the QR carries the token)
  You->>Dev: wizard: pick your Wi-Fi + password (required)
  Dev->>LAN: join your home Wi-Fi
  Dev->>Dev: setup hotspot shuts down after handoff
  Dev-->>You: wizard carries you to the device's LAN address
  You->>Dev: wizard: provider key + Verify (required)
  opt skippable steps
    You->>Dev: operating mode · Telegram · voice · device name
  end
  Dev-->>You: dashboard at the device's LAN address
```

## 1. Power on

Power the board over USB-C. What you see depends on the mode chosen during
flashing:

- **Orchestrator** shows its own **setup Wi-Fi network name** and a sign-in
  QR on the display. Continue below.
- **Notifier** shows Bluetooth pairing guidance instead - there is no Wi-Fi
  or web UI in that mode. Jump to the
  **[Notifier quick start](notifier-quick-start.md)**.

## 2. Join the setup network

Two steps, in order - the same two the device screen shows:

1. **Join the setup network** shown on the panel:
   - **Network:** `Nimbus-setup` (a second device numbers itself
     `Nimbus-2-setup`, and so on)
   - **Password:** shown on the device screen (unique to your device) - or just
     scan the QR to join automatically
2. **Open `http://192.168.4.1`.** A setup page usually opens on its own once you
   join. **If nothing opens, visit `http://192.168.4.1`** in your browser.

Don't use `nimbus.local` for this first hop - it is a LAN name and can resolve to
a different Nimbus. The setup page opens the wizard **already signed in**; there is
no token to copy.

## 3. Walk the wizard

The wizard asks for two required things and lets you skip the rest:

| Step | Required? | Notes |
|---|---|---|
| **Connect to Wi-Fi** | Yes | Scan, pick your home network, type its password. 2.4 GHz only; SSIDs are case-sensitive. |
| **Provider key** | Yes - one verified key | Paste an API key and click **Verify**. **[Mistral](https://console.mistral.ai/) is the recommended starting point** - free tier, and the voice default; OpenAI and Anthropic work too. Have the key ready before you start (see [Get your provider key](provider-keys.md)); you cannot fetch one now, on the device's own Wi-Fi. Keys are write-only: shown as "set", never displayed again. |
| Operating mode | Skippable | Defaults to what the installer chose; changeable later (a change restarts the device). |
| Telegram | Skippable | Add a bot token later under Assistant → Connectors → Telegram. |
| Voice | Skippable | Dictation and spoken replies default to Mistral. |
| Device name | Skippable | One name drives the setup network SSID, the LAN address, the Bluetooth name, and what the assistant calls itself. |

On a **touchscreen board**, keep the wizard open while the device joins your
Wi-Fi: the setup network shuts down after handoff (to protect the panel from
its own radio), and the wizard carries you to the device's new LAN address
automatically. "Home Wi-Fi connected + setup hotspot off" is the healthy end
state, not a failure.

:::danger Using only a Mistral key? Set embeddings BEFORE first use
The long-term memory's **embedding provider defaults to OpenAI**, and it is a
**set-once** choice: changing it later **erases the vector memory** (every
stored embedding becomes unreadable to the new model). If Mistral is your only
key, open **Memory & Files → Memory settings** and switch the embedding
provider to **Mistral before your first conversation** - while the memory is
still empty and there is nothing to lose.
:::

## What works with which provider

Any one verified provider runs the assistant. A few features are tied to a
specific provider or key - honestly, today:

| Feature | Mistral | OpenAI | Anthropic |
|---|---|---|---|
| Conversation, tools, sub-agents, routines | ✓ | ✓ | ✓ |
| Dictation (speech-to-text) | ✓ *(default)* | ✓ | - |
| Spoken replies over Telegram | ✓ *(default)* | ✓ | - |
| Spoken replies on the device speaker | - | ✓ | - |
| Image generation (`image.generate`) | - | ✓ | - |
| Long-term memory embeddings | ✓ *(switch before first use)* | ✓ *(default)* | - |
| Web search | needs a separate **Tavily** key (Assistant → Tools → Web search) | same | same |

## 4. The dashboard

The wizard ends on the device's **dashboard** at its LAN address - health,
battery, memory, and sessions at a glance, with **Home**, **Chat**, **Memory**,
the **Assistant** page (one flat subtab row: Models, Connectors, Tools, Skills,
Routines, Usage, and Safety), and **Device** settings. You sign in once per
browser; the sign-in QR on the device screen gets any new browser in.

Full tab-by-tab detail: the
[web UI reference](https://docs.cumulo-nimbus.ai/getting-started/webui-reference).

Next: **[Your first conversation](first-conversation.md)**.

---

*How it works → [Orchestrator World](../orchestrator-world.md)*

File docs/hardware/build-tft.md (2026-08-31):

# Build Guide - Touch TFT

How to construct the touch-screen Nimbus configuration from parts: a 2.8"
ILI9341 240×320 color TFT with an XPT2046 resistive touch controller on the
Solide S3 board (ESP32-S3-DevKitC-1 N16R8). The display and touch controller
share the board's SPI3 pads, and the touch layer is the only input.

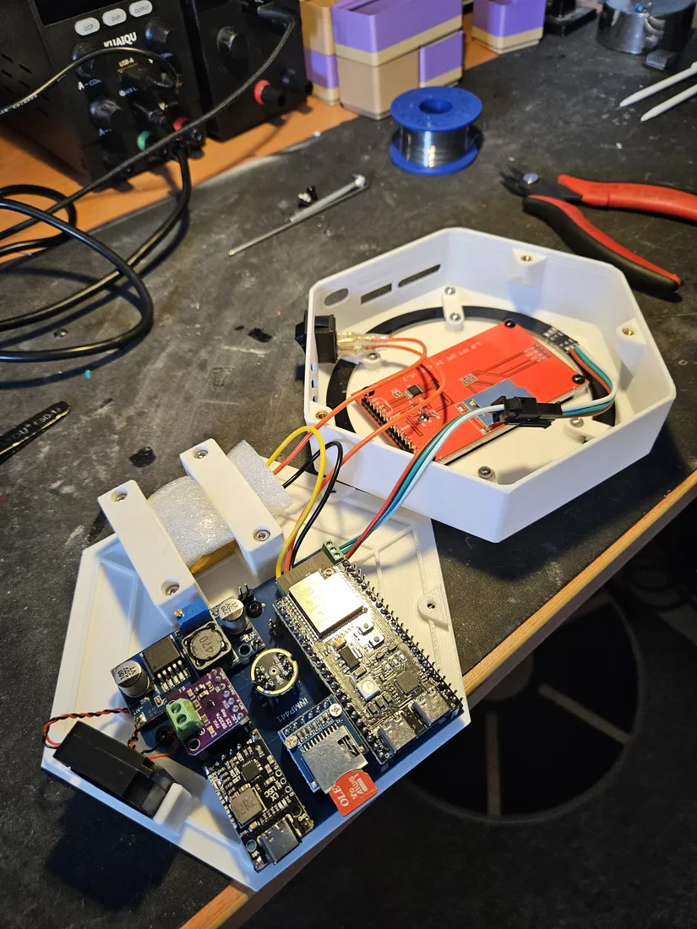
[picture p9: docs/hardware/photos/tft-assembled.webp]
Assembled touch-TFT Nimbus


This page is the assembly walk-through. The companion pages:

- [Touch TFT reference](touch-tft.md) - the pinout drawing, touch
  calibration, screenshots, and the white-screen investigation.
- [Hardware reference](../hardware.md) - everything common across the boards:
  first flash, shared peripherals, power, battery sensing.

## Bill of materials

All commodity parts; any listing matching the **Module / chip** column works.
Prices are approximate street prices in USD, excluding shipping. The
consolidated parts list for all configurations, with the shared-parts
breakdown and safety notes, is the **[bill of materials](bom.md)**.

| Qty | Part | Module / chip | Notes | Purchase | ~Price |
|---|---|---|---|---|---|
| 1 | Dev board | **ESP32-S3-DevKitC-1 N16R8** | 16 MB QIO flash, 8 MB octal PSRAM. The N16R8 variant specifically - octal PSRAM occupies GPIO 33–37. | [AliExpress](https://www.aliexpress.com/w/wholesale-esp32-s3-devkitc-1-n16r8.html) · [Mouser](https://www.mouser.com/c/?q=ESP32-S3-DevKitC-1-N16R8) | $12 |
| 1 | Display | **2.8" ILI9341 SPI TFT, 240×320**, with **XPT2046** resistive touch | The common SPI module with display pads (SCK/SDI/SDO/DC/RESET/CS/LED) plus a touch header (T_CLK/T_DIN/T_DO/T_CS/T_IRQ). Three on-module solder bridges are required - see below. | [AliExpress](https://www.aliexpress.com/w/wholesale-2.8-ili9341-spi-touch-xpt2046.html) | $8 |
| 1 | LED ring | **WS2812B ring, 45 pixels** | Addressable RGB; 5 V power, 3.3 V logic. | [AliExpress](https://www.aliexpress.com/w/wholesale-ws2812b-led-ring.html) | $6 |
| 1 | Amp | **MAX98357A I²S amplifier** breakout | Class-D, built-in thermal and over-current protection. | [Adafruit 3006](https://www.adafruit.com/product/3006) · [AliExpress](https://www.aliexpress.com/w/wholesale-max98357a.html) | $2–6 |
| 1 | Speaker | **4 Ω · 3 W · ~40 mm** full-range | The standard MAX98357A pairing; any small 4 Ω 3 W driver (28–45 mm) works. | [AliExpress](https://www.aliexpress.com/w/wholesale-40mm-4ohm-3w-speaker.html) | $2 |
| 1 | Mic | **INMP441** or **ICS-43434** I²S MEMS mic breakout | Separate breakout from the amp. **3.3 V only** - 5 V damages the S3. | [AliExpress](https://www.aliexpress.com/w/wholesale-inmp441-i2s.html) | $2 |
| 1 | Storage | **microSD module (SPI)** + microSD card | Card must be formatted **FAT32** - see the trap below. | [AliExpress](https://www.aliexpress.com/w/wholesale-micro-sd-card-module-spi.html) + any 16–32 GB card | $6 |
| 2 | Cells | **18650 Li-ion** | Wired in **series** (2S). Brand-name cells from a reputable vendor only. Reference pack: owner-measured 3500 mAh, 8.40 V full. | [18650batterystore.com](https://www.18650batterystore.com/) | $12 |
| 1 | Charger/protection | **2S BMS with USB-C charging** | Protection + balance + charging in one module. | [AliExpress](https://www.aliexpress.com/w/wholesale-2s-bms-usb-c-charging-board.html) | $3 |
| 1 | Regulator | **DC-DC converter → 5 V** | From the 2S pack (~6.0–8.4 V) to a clean 5 V bus, ≥2 A. | [AliExpress](https://www.aliexpress.com/w/wholesale-dc-dc-buck-converter-5v-3a.html) | $2 |
| 1 each | Battery sense | 220 kΩ + 100 kΩ resistors | Optional but recommended - the pack-voltage divider on GPIO 4. | any electronics supplier | $1 |
| - | Misc | wire, protoboard/PCB, JST connectors; optional 330 Ω resistor (LED DIN) and 1000 µF capacitor (ring 5 V/GND) | The resistor and capacitor improve LED reliability on long runs. | [AliExpress](https://www.aliexpress.com/w/wholesale-jst-connector-kit-protoboard.html) | $5 |

**Total: ≈ $59–63** (AliExpress-class sourcing; US distributors add ~$15–25).

The panel's touch layer is the only input.

## Power architecture

```mermaid
flowchart LR
  USB["USB-C"] --> BMS["2S BMS<br/>(charge + protect + balance)"]
  BMS --> PACK["2×18650 series<br/>6.0–8.4 V"]
  PACK --> DCDC["DC-DC converter"]
  DCDC --> BUS["5 V bus"]
  BUS --> RING["LED ring +5V"]
  BUS --> VIN["ESP32-S3 VIN"]
  VIN --> LDO["on-board LDO"]
  LDO --> R33["3.3 V rail"]
  R33 --> PER["TFT + touch · microSD ·<br/>mic + amp VCC"]
```

- **On battery:** the DC-DC 5 V bus feeds the ESP32's VIN; the DevKit's
  on-board regulator makes the 3.3 V rail. USB-C on the BMS charges the pack.
- **On USB alone (development):** the DevKit runs from USB - the MCU, TFT,
  touch, SD, and mic all work. The **LED ring will not light and the speaker
  will not drive audibly without the 5 V bus**, which is the pack path.
- **Every ground is common** - tie all GNDs together: cells, BMS, DC-DC,
  ESP32, and every module.
- ⚠ **The mic VCC is 3.3 V only.** Its VDD and data lines follow VCC, and 5 V
  damages the S3's input. Never put the mic on the 5 V bus.
- ⚠ **The TFT backlight is a continuous draw** whenever it is lit. It sits on a
  PWM pin so the firmware's idle path blanks it rather than drawing a
  screensaver.

## The three on-module solder bridges (do this first)

The XPT2046 touch header is **not** wired to three additional ESP32 GPIOs.
Before wiring the module to the board, solder three short jumpers **on the TFT
module itself** so touch and display share one SPI bus:

| Touch pad | Jumper to display pad | Shared ESP32 net |
|---|---|---|
| `T_CLK` | `SCK` | GPIO 42 - SPI clock |
| `T_DIN` | `SDI` | GPIO 41 - SPI MOSI |
| `T_DO` | `SDO` | GPIO 1 - SPI MISO |

These are physical pad-to-pad connections on the module, not three more wires
to the DevKit. Connect `T_CS` separately to **GPIO 48**. Leave `T_IRQ`
**unconnected**; Nimbus polls the touch controller.

⚠ **Continuity-check all three pairs with power disconnected.** The ESP32 bus
wire may land on either pad of a pair, but both pads must be electrically
common. Missing bridges can leave the display completely blank (bus wires on
the touch-side pads) or leave the display working while touch is dead (bus
wires on the display-side pads). Also verify `T_CS → GPIO 48` and confirm
`T_IRQ` has not accidentally been connected to GPIO 48.

## Wiring

The whole build at block level - each peripheral with its bus and rail, and
the battery chain along the bottom (the pin-by-pin tables follow):

Block-level wiring of the touch TFT build: TFT + touch, microSD and battery sense on the left; LED ring, amp and mic on the right; USB-C to BMS to 2S pack to DC-DC to the 5 V bus along the bottom

Copied from the [Touch TFT reference](touch-tft.md#wiring) - the display and
touch table first, then the shared peripherals from the
[solide-drivers build guide](https://github.com/ristllin/solide-drivers/blob/main/docs/build.md).

### TFT + touch (SPI3)

| ESP32 GPIO | Net | Module pins |
|---|---|---|
| 42 | SPI clock | SCK **+ T_CLK** |
| 41 | SPI MOSI | SDI **+ T_DIN** |
| 1 | SPI MISO | SDO **+ T_DO** |
| 40 | display D/C | DC |
| 39 | display reset | RESET |
| 38 | display CS | CS |
| 48 | touch CS | T_CS |
| 2 | backlight (PWM) | LED |
| - | *not connected* | T_IRQ |
| 3V3 / GND | power | VCC / GND |

The three on-module bridges make display and touch one SPI bus with two chip
selects, which is what fits the whole panel into seven GPIOs.

### microSD module (SPI2 - a separate bus)

| Module pin | → | ESP32 |
|---|---|---|
| VCC (3V3) | → | **3V3** |
| GND | → | **GND** |
| CS | → | GPIO **10** |
| MOSI (DI) | → | GPIO **11** |
| SCK (CLK) | → | GPIO **12** |
| MISO (DO) | → | GPIO **13** |

The SD is **not** on the TFT's SPI bus - they share only 3.3 V and ground.

### WS2812B LED ring

| Module pin | → | ESP32 / rail |
|---|---|---|
| +5V | → | **5 V bus** |
| GND | → | **GND** (common) |
| DIN | → | GPIO **21** (a 330 Ω series resistor on DIN is good practice) |

### Audio - MAX98357A amp + I²S mic {#audio-wiring}

Two separate breakouts. The amp runs at reduced volume on 3.3 V (fine as a
status speaker); use the 5 V bus for more volume - but never share that VCC
with the mic.

| Module | Pin | Role | → | ESP32 / rail |
|---|---|---|---|---|
| amp | VCC | power | → | **3V3** (5 V bus for louder) |
| amp | GND | ground | → | **GND** |
| amp | BCLK | bit clock | → | GPIO **7** |
| amp | LRCLK | word clock | → | GPIO **8** |
| amp | DIN | data in | → | GPIO **17** |
| mic | VDD | power | → | **3V3** ⚠ (never 5 V) |
| mic | GND | ground | → | **GND** |
| mic | BCLK / SCK | bit clock | → | GPIO **15** |
| mic | WS / LRCLK | word select | → | GPIO **18** |
| mic | SD | data out | → | GPIO **16** |
| mic | L/R | channel select | → | **GND** (left slot) |

### Battery sense (optional, recommended)

A 220 kΩ / 100 kΩ divider from the pack (before the DC-DC) into GPIO 4 (ADC1).
See [Battery voltage sampling](../hardware.md#battery-voltage-sampling-how-to-add-it).

## Assembly walk-through

A photo-by-photo build of an actual Nimbus, from printed parts to the finished
device. The [wiring tables](#wiring) above are the pin-level authority; this
section is the physical order of operations.
On this build the [three on-module solder bridges](#the-three-on-module-solder-bridges-do-this-first)
come first, before any step below. Bench-flash and self-test each subsystem (the
[Assembly order](#assembly-order) below) before you close the case.

### Print the case and set the heat inserts

Print all enclosure parts before you touch the electronics. STL, material, and support notes live in [Enclosure and CAD](#enclosure-and-cad) - print in PLA or PETG, main body needs no supports on most printers.

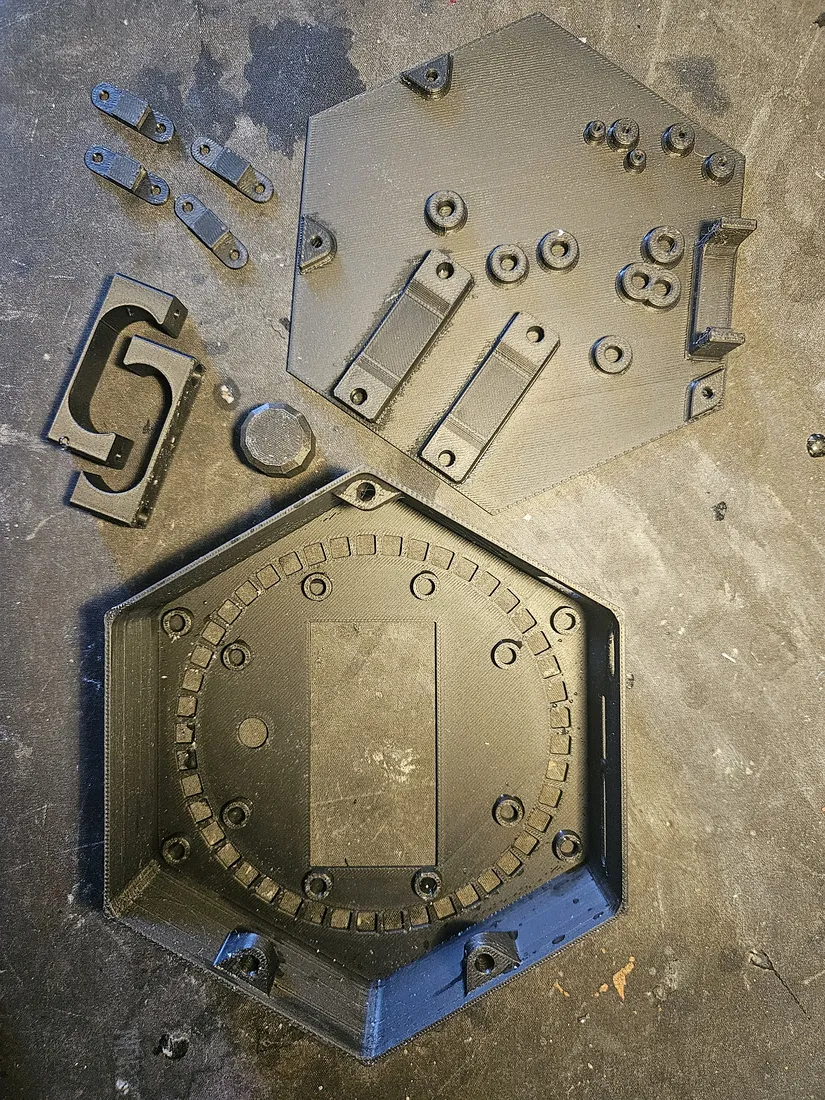
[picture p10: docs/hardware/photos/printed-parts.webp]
Full set of black 3D-printed enclosure parts: top plate, bottom tub, small clip brackets, an S-logo bracket, and a hex plug


**Confirm the print set is complete.** Lay every part out and account for it before starting. This build uses:

- the **top plate** (upper right) - flat hexagon carrying the board standoffs, two long rail mounts, and the clustered mounting bosses;
- the **bottom tub** (lower) - deep hexagon with the circular LED-ring channel and the rectangular center pocket;
- the small **clip brackets** and the **S-logo bracket** (left);
- the **hex plug** (center left).

Check that the boss holes printed clean and open. If a hole bridged over or is stringy, clear it before pressing an insert - an insert will not seat square in a fouled hole.

**Set the inserts in the tub half.** Press a brass heat-set insert into each boss around the LED-ring channel and into the corner posts.

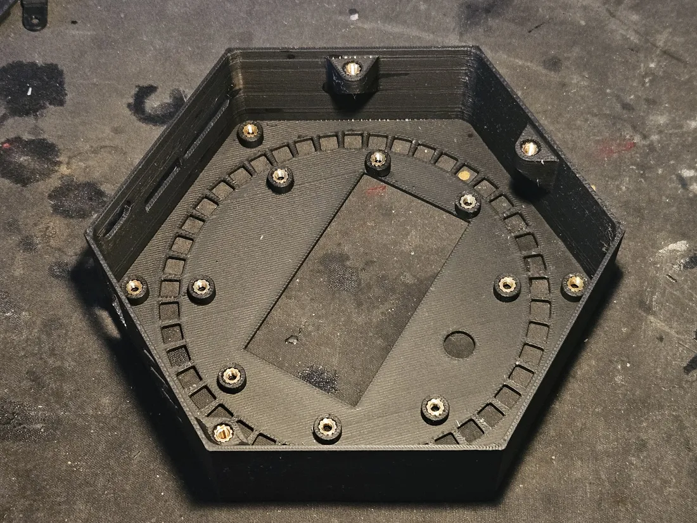
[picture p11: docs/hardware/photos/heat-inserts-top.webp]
Bottom tub with brass heat-set inserts seated flush in the ring-channel bosses and corner posts


Use a soldering iron fitted with an insert tip (or a plain conical tip). Follow the iron's own guidance for temperature and the insert maker's recommended setting - do not guess a number. Rest the insert on the hole, let it heat, then press straight down so the knurled body sinks into the plastic. Check each one: the insert should sit flush or a hair below the boss face, square to the surface, with a small bead of melted plastic pushed up around it. Wipe stray plastic off the threads while it is still warm.

**Set the inserts in the plate half.** Repeat for every boss on the top plate, including the two long rail mounts and the standoff clusters.

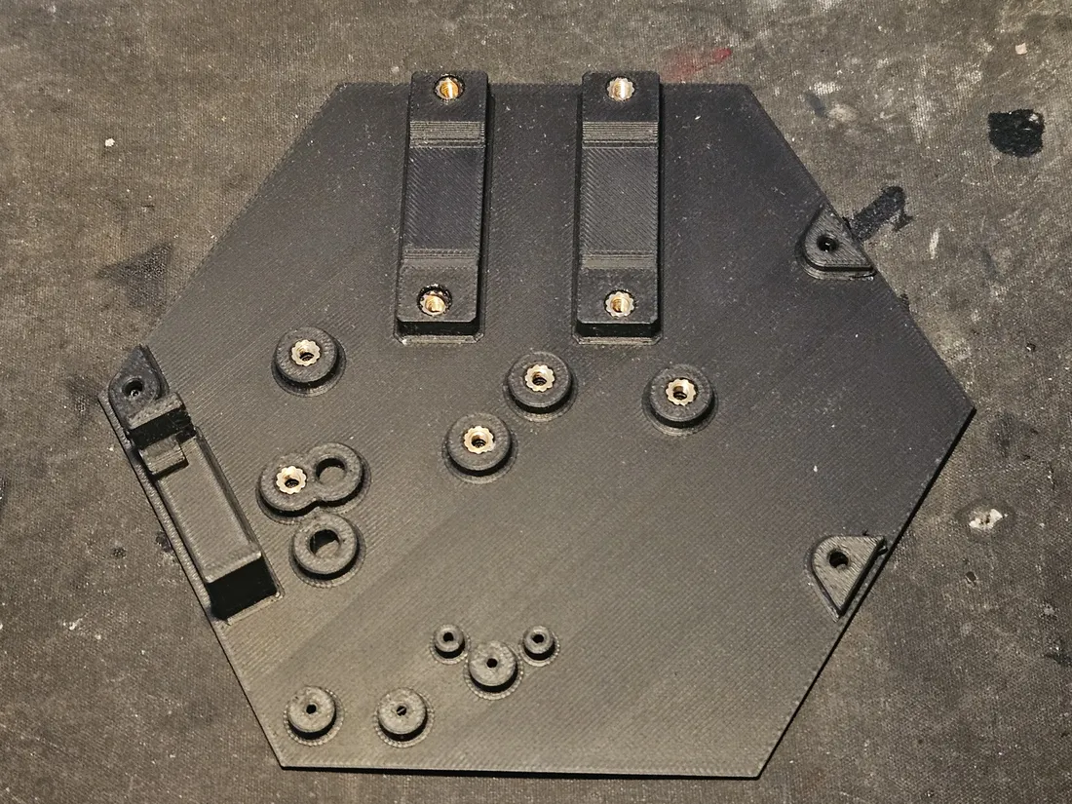
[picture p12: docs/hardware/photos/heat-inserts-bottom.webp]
Top plate with brass inserts pressed into the two rail mounts and the standoff-boss clusters


The plate carries more inserts and they sit at different heights on the raised standoffs. Keep each one vertical as it sinks - a leaning insert throws off board alignment later. Confirm the two inserts at the ends of each rail mount are flush; those take the load when the assembly is screwed together. Let the whole part cool fully before you thread anything into a fresh insert.

**Fastener note: the microSD holder screws.** The microSD holder module stands taller than the flat-seated parts, so it uses a longer pair of screws than the rest of the assembly.

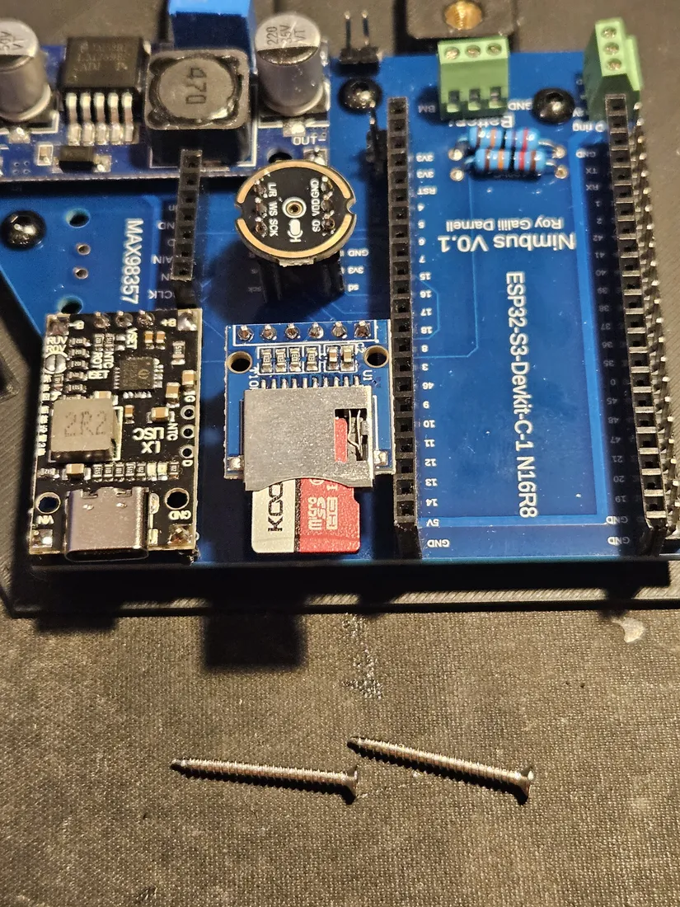
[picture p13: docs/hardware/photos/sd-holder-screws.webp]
Assembled Nimbus shield on the ESP32-S3 DevKit with the microSD holder, and two longer screws laid on the bench below


Set the two longer screws (shown on the bench beneath the board) aside with the SD holder so they do not get mixed into the shorter case hardware. Match screw length to what each part actually needs - a screw too long will bottom out or push past a boss. If you are unsure of a length, match it against the part before driving it.

Seat inserts and dry-fit the case, but leave the board and Li-ion pack out until wiring is done. Keep the earlier safety framing in view once electronics go in: brand-name cells only, the 2S BMS stays between the cells and everything else, never charge the pack outside the BMS, verify a clean 5V at the DC-DC output with a meter before the board or pack is connected, tie every ground common, and treat any warm or hot module or SD card as an electrical fault - power off first. The firmware caps LED brightness at 60% and it must not be raised.

### Assemble the carrier board

There are two ways to wire a Nimbus. This section covers the **optional custom carrier PCB** (Nimbus V0.1) - a single blue board that sockets the DevKit and every module and routes the power section for you. If you would rather hand-wire, skip this section entirely and build on protoboard straight from the [Wiring](#wiring) tables - the carrier PCB carries no signals the tables do not, it just makes them solder-free. The manufacturing outputs (Gerbers, ODB++, CAM) to order your own board live in [`hardware/fab/`](https://github.com/ristllin/Nimbus/tree/main/hardware/fab); see [how to order the board](https://github.com/ristllin/Nimbus/tree/main/hardware/fab#ordering-the-pcb).

The whole point of the board is that **nothing is soldered down permanently**. The DevKit and the small modules drop into female headers, so any one of them can be pulled and replaced. Solder the headers, not the modules.

#### The DevKit

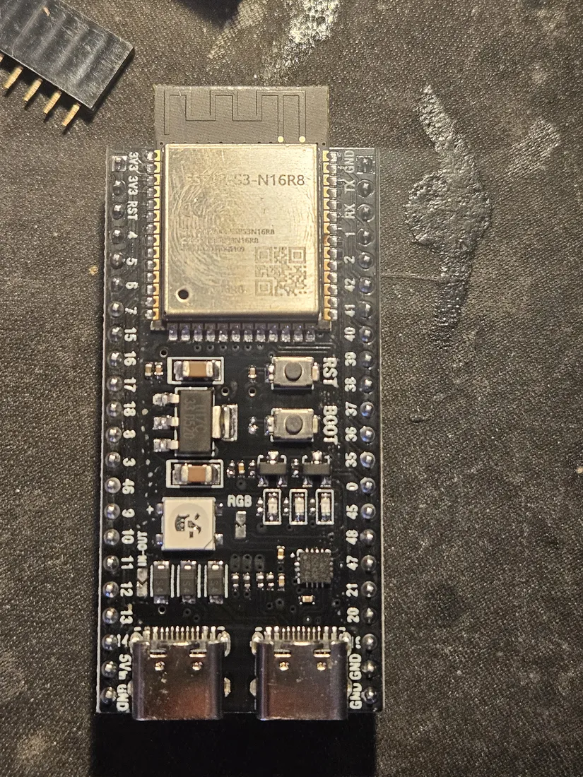
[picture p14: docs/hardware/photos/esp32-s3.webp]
ESP32-S3-DevKitC-1 N16R8 dev board with a loose black female header strip at top left


The brain is the **ESP32-S3-DevKitC-1 N16R8** - the wide black board with the shielded ESP32-S3-N16R8 module and two USB-C ports at the bottom edge. The two ports are not interchangeable: one is the UART bridge and one is the native USB. Flash a fresh board over the **UART** port - see [First flash of a fresh board](../hardware.md#first-flash-of-a-fresh-board-use-the-uart-port) - before you commit it to the carrier. The pin numbers silkscreened down both long edges (3V3, RST, 4, 5, 6 ... on one side; GND, TX, RX, 1, 2, 42 ... on the other) are the same numbers the [Wiring](#wiring) tables use. Note the loose black header strip in the corner of the photo: that is the part you solder to the carrier, not to the DevKit.

#### The modules

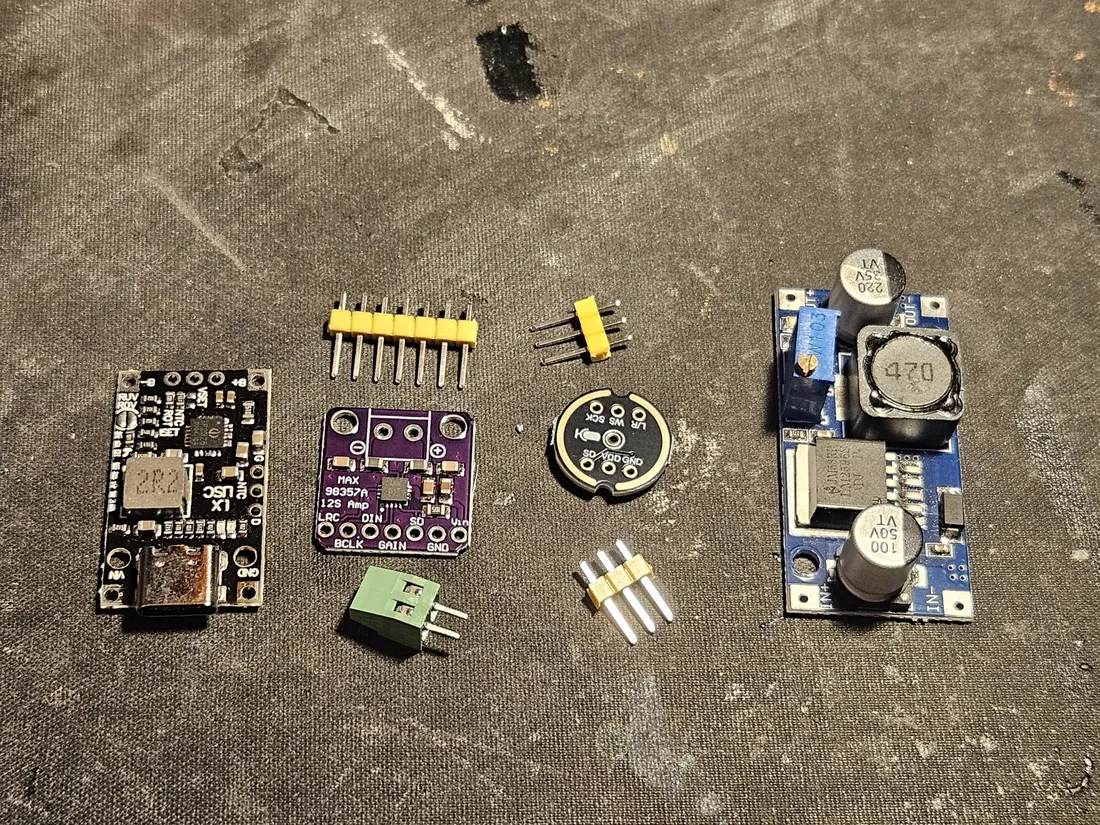
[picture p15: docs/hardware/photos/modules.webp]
Loose modules laid out: a USB-C charger board, a purple MAX98357A amp, a blue DC-DC LM2596 buck converter, a round INMP441 mic, a green screw terminal, and male header strips


Everything that sockets into the carrier, laid out. From the parts in the [bill of materials](bom.md): the purple **MAX98357A** I²S amp (with its green 2-position speaker screw terminal), the round **INMP441** I²S mic breakout, the blue **DC-DC LM2596** buck converter (the large module with the `470` inductor, the `100`/`220` electrolytics, and the blue trimmer pot), and the black USB-C **charger/BMS** board. Also shown are the male header strips for the module breakouts. Keep the mic separate in your mind from the amp - they are two different breakouts, and the mic is **3.3 V only**.

#### The bare board, top

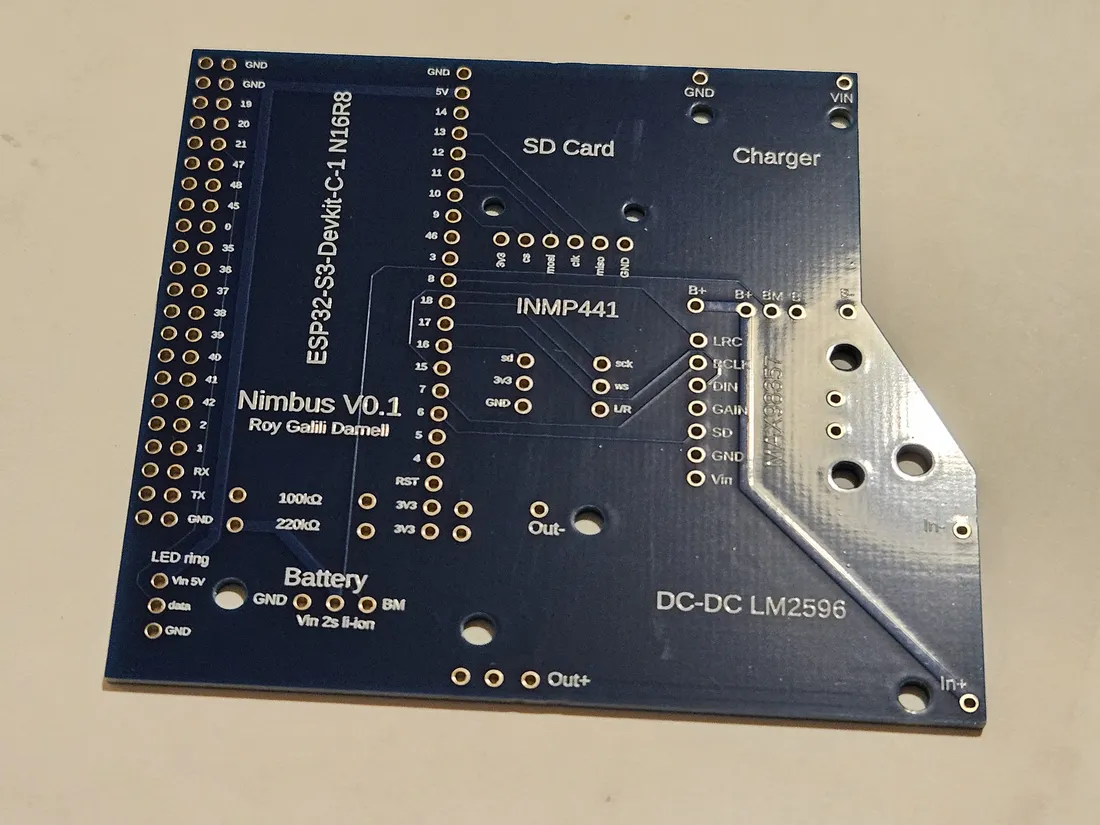
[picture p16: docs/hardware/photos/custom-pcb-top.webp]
Bare Nimbus V0.1 carrier PCB, top side, blue soldermask with white silkscreen naming each section


The bare carrier, top side. Read the silkscreen before you solder anything - every footprint is named:

- **ESP32-S3-Devkit-C-1 N16R8** - the two long through-hole rows down the left that the DevKit straddles.
- **SD Card**, **INMP441**, **MAX98357** - the three module rows across the middle, each with its pin names (`cs`/`mosi`/`clk`/`miso`, `sck`/`ws`/`sd`/`L/R`, `LRC`/`BCLK`/`DIN`/`GAIN`/`SD`/`Vin`).
- **Charger** and **DC-DC LM2596** - the power section on the right, with the `B+`/`BM`/`B-`, `VIN`, and `In+`/`In-`/`Out+`/`Out-` pads.
- **Battery** (`GND` / `Vin 2s li-ion` / `BM`) and **LED ring** (`Vin 5V` / `data` / `GND`) at the bottom left, plus the **100kΩ / 220kΩ** footprint for the battery-sense divider.

Every pad name maps one-to-one to a row in the [Wiring](#wiring) tables. When in doubt, the silk is the authority.

#### The bare board, back

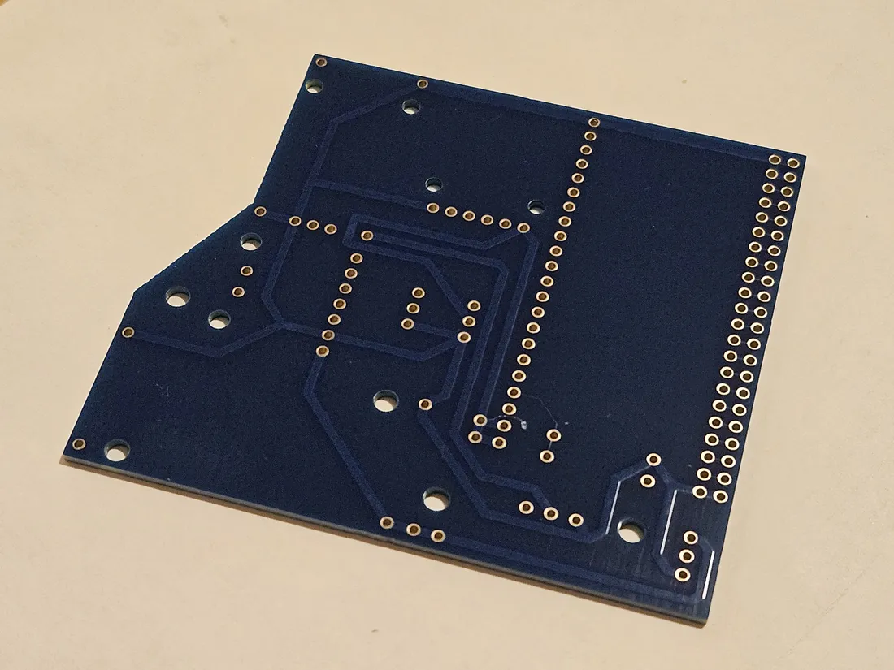
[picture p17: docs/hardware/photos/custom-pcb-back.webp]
Bare carrier PCB, back side, showing copper traces and plated through-holes with no components


The back, bare. This is where all your solder joints will land, so give it a look first: the plated through-holes and the routed traces should be clean and unbridged out of the box. Nothing mounts on this side - components all sit on the top.

#### The routing, for reference

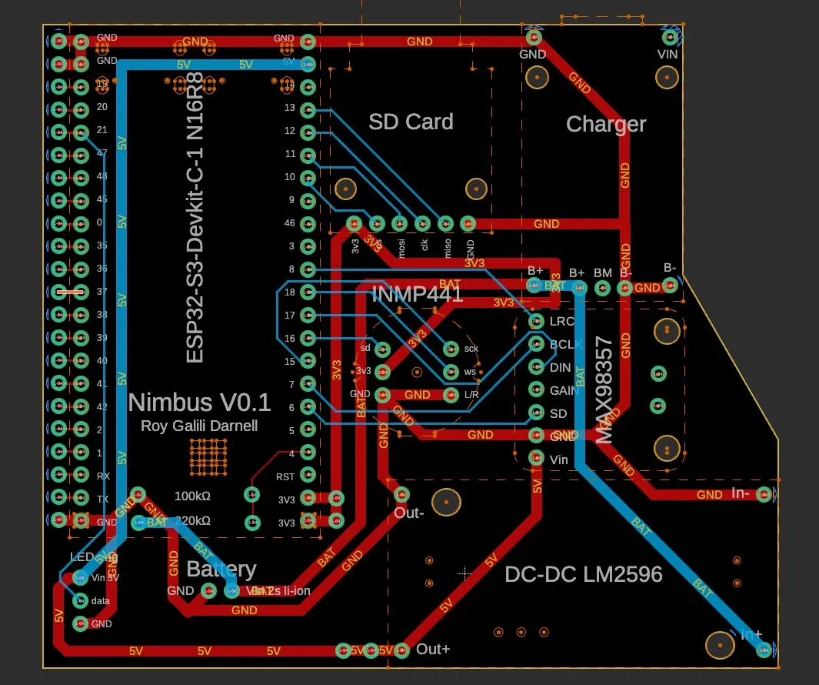
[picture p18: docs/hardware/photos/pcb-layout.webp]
EDA layout view of the carrier: red top-copper and blue bottom-copper traces carrying the GND, 5V, BAT, and 3V3 nets between every footprint


Not a build step - the board layout, for anyone who wants to trace a net or fork the design. It shows how the four nets (raw `BAT` from the pack, the regulated `5V` bus, `3V3`, and a common `GND`) reach every module. It is the visual companion to [Power architecture](#power-architecture): the pack feeds the DC-DC, the DC-DC feeds the 5 V bus, the DevKit's on-board regulator makes 3.3 V, and **every ground is tied common**.

#### Solder the female headers

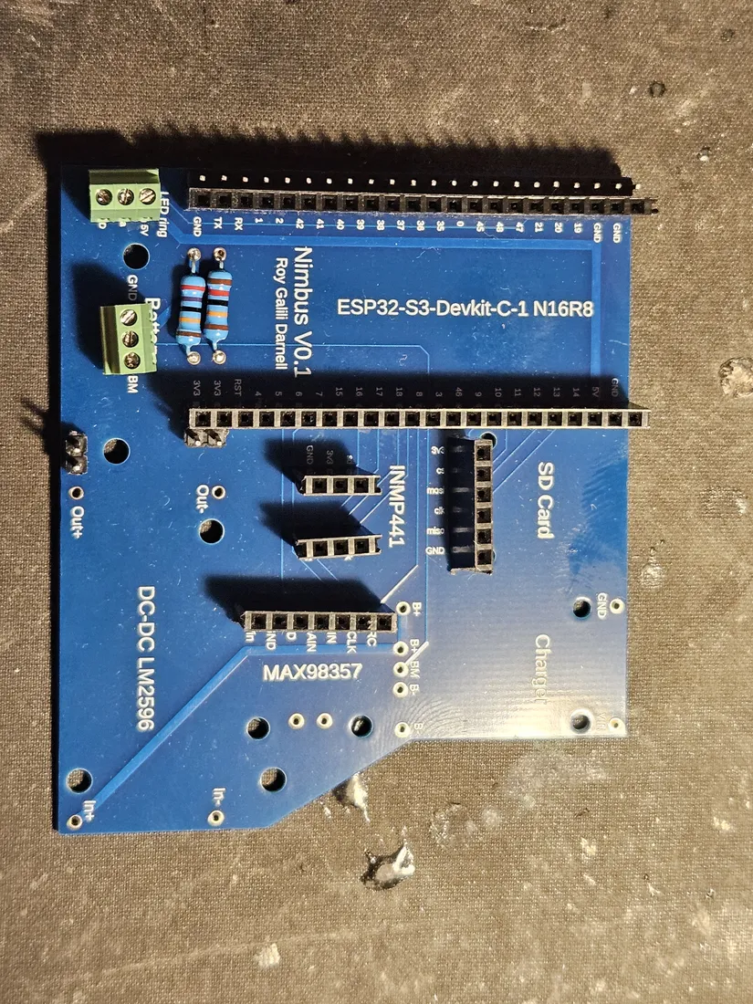
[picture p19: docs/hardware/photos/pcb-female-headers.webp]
Carrier PCB with black female headers soldered into the DevKit and module rows, two divider resistors and green screw terminals in place


**Set the headers.** Cut female header strips to the length of each row and solder them in from the top so the sockets face up: the two long rows for the DevKit, and one short row each for the SD Card, INMP441, and MAX98357 footprints. Tack one end pin, check the strip sits flat and square against the board, then solder the rest. Straight headers here are what let you unplug a module later.

**Set the fixed parts.** While the iron is hot, place the two battery-sense resistors in the `100kΩ` / `220kΩ` footprint (the divider into GPIO 4 - see [Battery sense](#wiring)), and the green screw terminals at the **Battery** and **LED ring** positions. These few parts do solder down; the modules do not. Check the finished joints are shiny and full, with none bridged to a neighbor.

#### Seat the charger and DC-DC

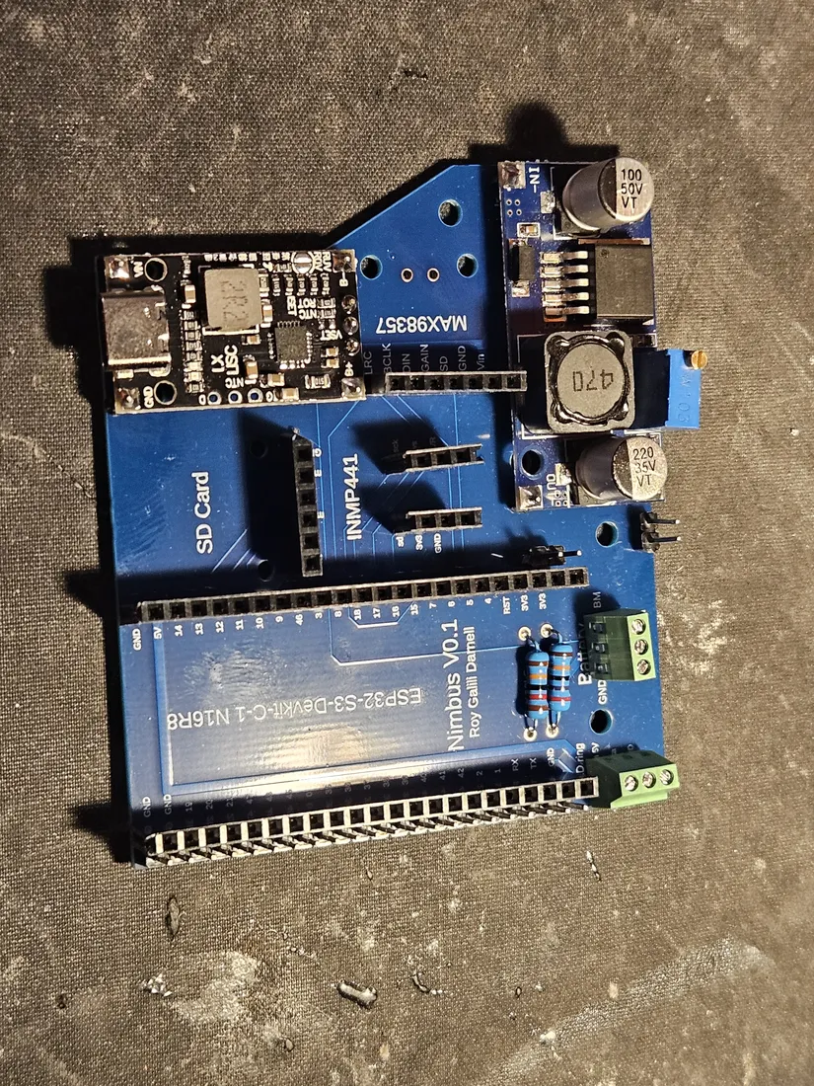
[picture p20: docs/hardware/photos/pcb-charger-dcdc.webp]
Carrier PCB, power side up, with the DC-DC LM2596 buck converter and the USB-C charger board mounted at the board edge


Mount the two large power modules at their labeled edge footprints: the **DC-DC LM2596** at the `In+`/`In-`/`Out+`/`Out-` pads and the **charger/BMS** at the `Charger` pads (`B+`/`BM`/`B-`, `VIN`). Their outputs are the 5 V bus and the pack rail, so get the polarity right against the silk.

Li-ion safety is not optional here. **Buy brand-name cells from a reputable vendor** - counterfeits are common. The **2S BMS stays between the cells and everything else** - the pack wires land on the charger/BMS, never straight onto the DC-DC or a module. **Never charge the pack outside the BMS.** Set the DC-DC output before you connect the DevKit: with the pack on the charger, turn the blue trimmer until a meter reads a clean **5 V** at `Out+`/`Out-`, as called out in [Power architecture](#power-architecture).

#### Seat the DevKit and modules

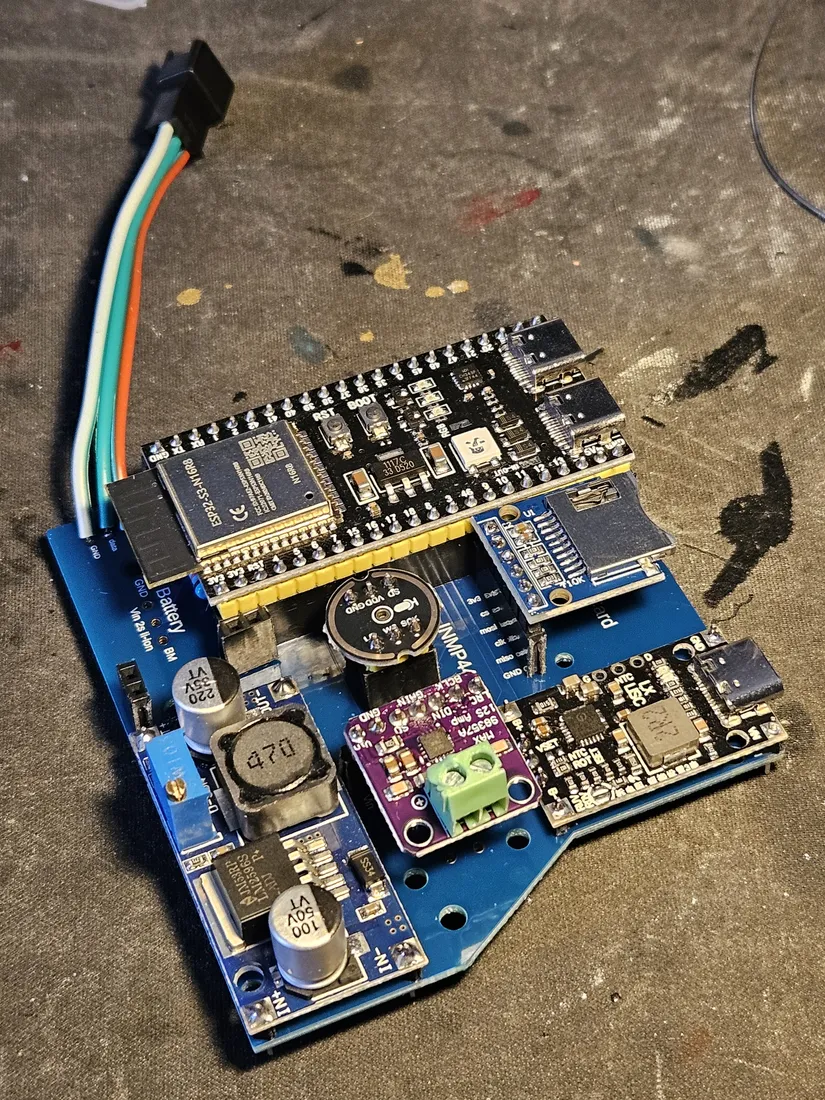
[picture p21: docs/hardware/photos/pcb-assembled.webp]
Fully assembled carrier: DevKit, mic, MAX98357 amp, DC-DC, and charger all socketed, with a three-conductor battery lead at the top left


**Seat the board.** Push the DevKit into its two header rows so both USB-C ports overhang the board edge and stay reachable, and so its silk pin numbers line up with the carrier's. Then drop in the three small modules - SD card, INMP441 mic, MAX98357 amp - matching each module's pin labels to the socket labels beneath it. The amp's green screw terminal is the speaker output.

**Connect the pack.** The three-conductor lead at the top left is the 2S pack: it lands on the **Battery** input (`GND`, `Vin 2s li-ion`, `BM`) - pack negative, the balance mid-tap, and pack positive - which routes to the BMS, not to anything downstream. Confirm every ground is common before power-on.

The firmware caps LED-ring brightness at 60% for thermal safety; do not raise that limit. And once running, treat any warm module or a warm SD card as an electrical fault - **power off first**, then debug (see the [hot-card safety check](../hardware.md#shared-peripherals)).

#### Check the back

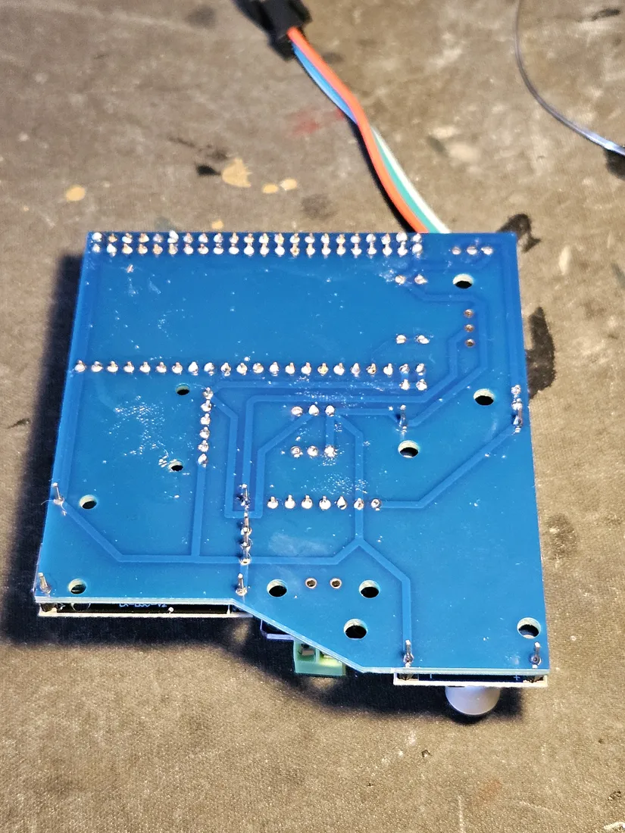
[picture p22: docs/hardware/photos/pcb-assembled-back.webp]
Back of the fully assembled carrier, showing the soldered header rows and the battery lead routed over the top edge


Flip it and inspect. Every header row should show a clean line of full, shiny joints with no cold joints and no bridges between adjacent pins - the DevKit rows and the module rows are the ones to scrutinize, since a single bridge there can short a rail into a signal. With the joints good and the pack on the BMS, the board is ready for the [Wiring](#wiring) verification and first flash.

### LED ring, speaker, and power switch

Three ring-and-shell parts finish the build: the WS2812B light ring behind the face, the status speaker in its pocket, and the rocker that switches pack power. Wire them per the pinout tables already in this page - do not re-derive the pins here.

**1. Identify the ring and its pigtail.**

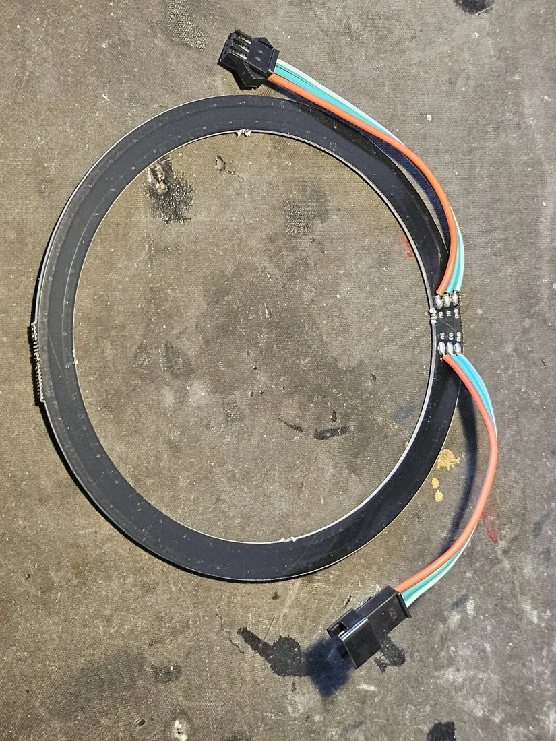
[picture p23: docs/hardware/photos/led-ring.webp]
WS2812B 45-pixel ring with a three-wire pigtail terminating in a 3-pin JST connector


The ring is a flexible 45-pixel WS2812B on a black PCB. A three-conductor pigtail is soldered to the three pads at one point on the ring and runs out to a 3-pin JST connector: one conductor for +5V, one for GND, one for DIN. Confirm which pad is which against the silkscreen before you trust the wire colors - the colors are just whatever the pigtail shipped with and carry no standard meaning. Land those three wires exactly as the [WS2812B LED ring](#ws2812b-led-ring) table specifies: +5V to the 5 V bus, GND common, DIN to the data pin (a 330 Ω series resistor on DIN is good practice). Power the +5V leg only from the 5 V bus, never from 3V3.

**2. Cut the ring open for the case pass-through.**

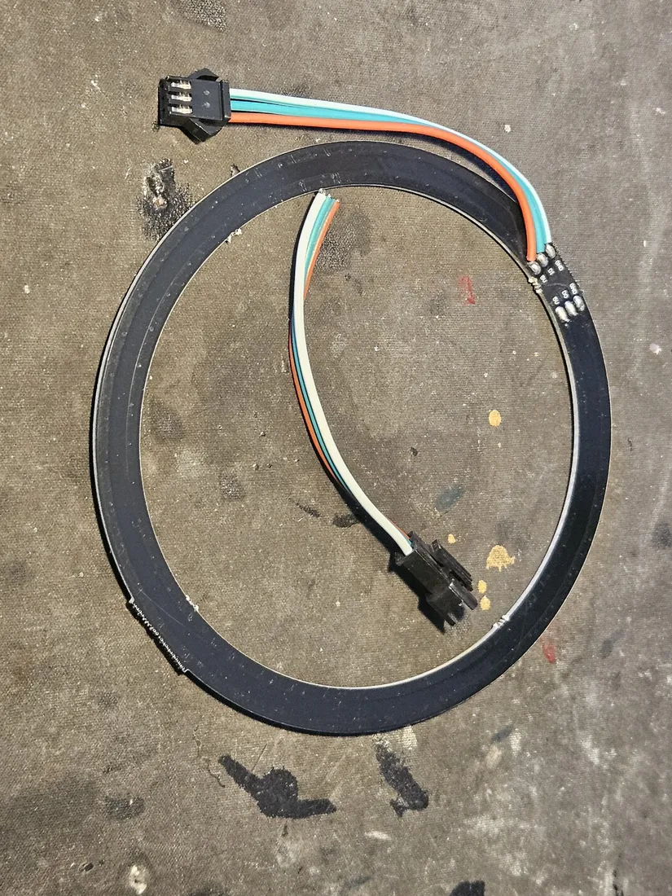
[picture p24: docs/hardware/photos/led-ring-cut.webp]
The ring opened at one point where the single power ribbon bridging its ends has been cut, the loop no longer continuous, the pigtail and every pixel left intact


The ring must open at one spot so the pigtail can drop straight through the case wall instead of being pinched around the rim. Cut the single power ribbon that bridges the ring's two ends closed, at the seam next to where the pigtail attaches. Cut that ribbon only - never cut the LED strip itself, and do not nick or sever the three pigtail conductors; they must stay intact and carry the signal. The pixels are a single addressable chain, so any break in the strip kills every pixel downstream of it - the power ribbon is the one and only thing you cut. Route the pigtail through the case opening and reseat the ring so the open ends sit flush.

**Brightness cap.** The firmware caps the ring at 60% brightness and this cap must not be raised. It is a thermal and current limit for a 45-pixel ring on this pack, not a preference. Leave it where it is.

**3. Prep the speaker.**

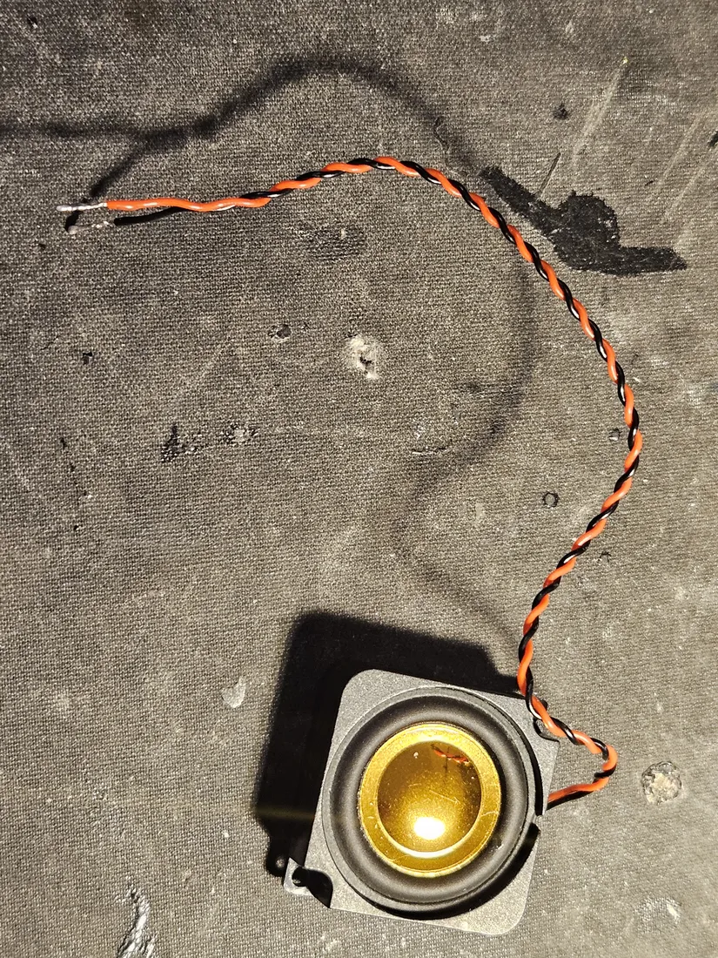
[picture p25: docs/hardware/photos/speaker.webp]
Small round 4 ohm speaker in a square frame with a gold cone and a twisted red-and-black lead pair, ends tinned


The speaker is the small 4 Ω full-range driver in a square frame. It comes with a twisted red/black lead pair, tinned at the free ends. This is a bare driver with no polarity that matters for a mono status tone, but keep the pair twisted to hold noise down. Land the two leads on the amp's speaker output per the [Audio wiring](#audio-wiring) section - the driver connects to the MAX98357A output, not to any ESP32 pin or rail directly.

**4. Mount the speaker in the case.**

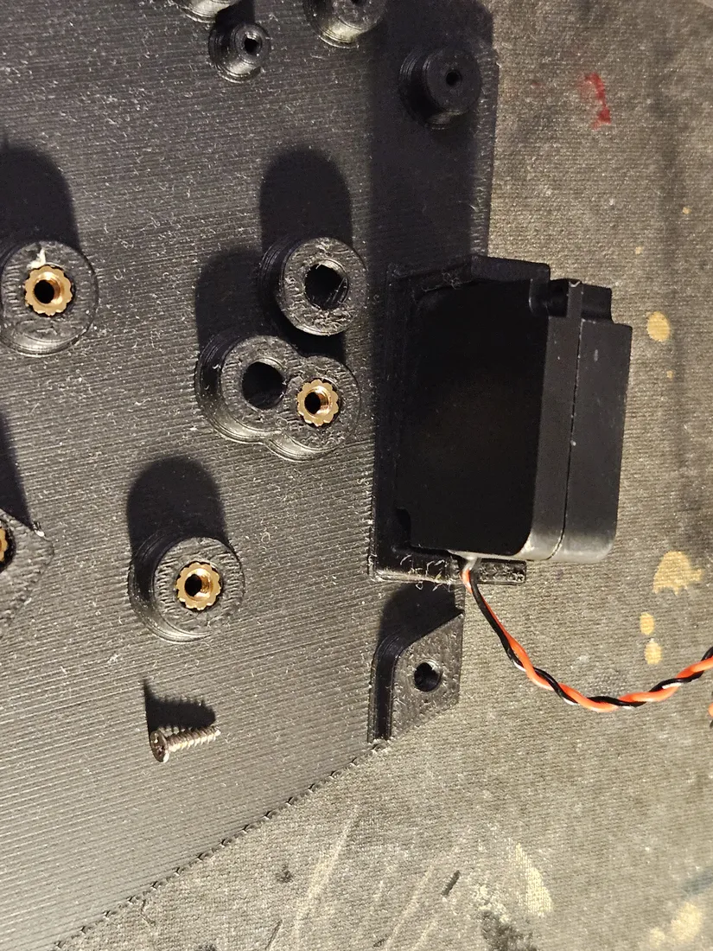
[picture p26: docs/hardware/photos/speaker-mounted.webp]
Speaker seated in a printed pocket beside a cluster of brass heat-set inserts, with a self-tapping screw staged nearby


Seat the driver into its printed pocket so the frame sits flat against the shelf and the cone faces the grille. Fix it with the frame's mounting tab against the printed post; drive the self-tapping screw shown into the post - use the screw that fits the printed boss, do not overtighten into the plastic. Route the twisted lead pair out through the channel toward the amp. Check that the frame is fully seated and the cone is not fouling any wall before you close up. A speaker enclosure that buzzes is almost always a loose frame or a lead trapped under the cone, not a bad driver.

**5. Press in the power rocker.**

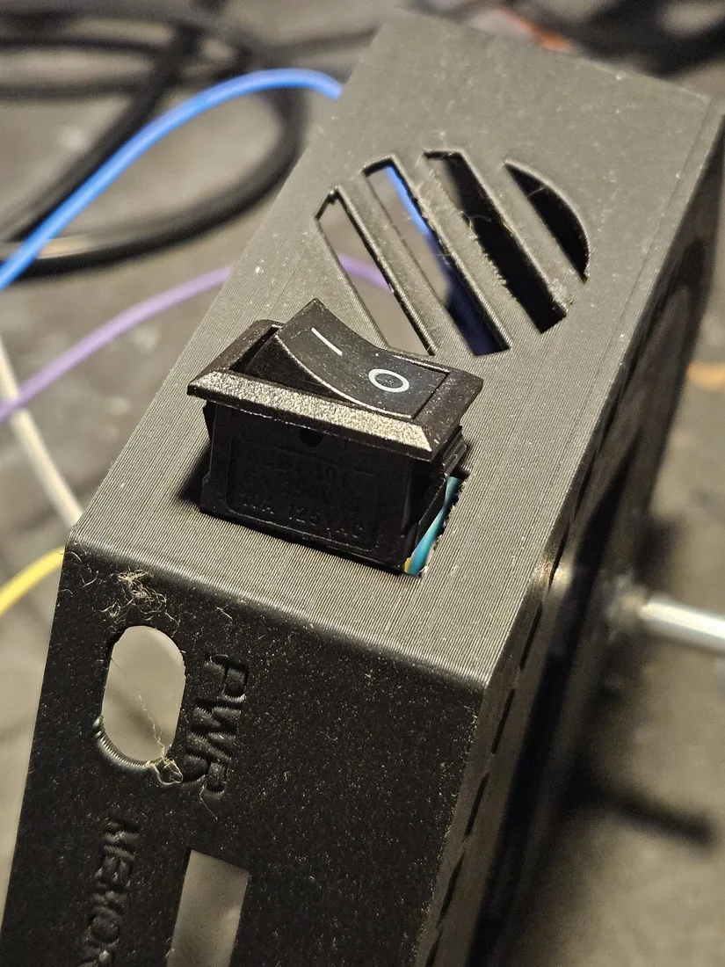
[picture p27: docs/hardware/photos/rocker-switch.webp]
Black rocker switch pressed into a rectangular cutout in the printed case top, next to vent slots, above an embossed PWR label


The rocker drops into the rectangular cutout in the case top, beside the vent slots and above the embossed **PWR** marking. Wire it before you press it home: the switch breaks the pack power line, so its two spade terminals go inline on the main power feed, one lead in and one out. Push the switch straight into the cutout until both retaining clips snap and the bezel sits flush with the case face. It should hold with no adhesive. The **I / O** markings on the paddle are the live/off states; confirm the paddle throws freely once seated and that the leads clear the vent slots.

This switch sits ahead of everything downstream but the pack always stays behind its 2S BMS - never bypass the BMS to reach the cells, and never charge the pack outside it. Keep every ground common across the ring, speaker, and switch. If any module or the SD card runs warm or hot, that is an electrical fault: throw the rocker to off first, then investigate.

### Build the 2S battery pack

> **Read this before you touch a cell - 2S Li-ion.** Two 18650s in series hold real energy, and this is the one stage of the build that can burn you or start a fire. Buy brand-name cells from a reputable vendor (the reference pack uses matched LiitoKala Lii-35A); counterfeit 18650s are common and dangerous. The **2S BMS stays between the cells and everything else** - it is the only protection, balance, and charge path, so never charge the pack outside the BMS and never feed the DC-DC from anything but the BMS output. Tie every ground common. If a cell, a module, or the SD card ever gets warm that should not, treat it as an electrical fault: power off first, debug second. Work on one joint at a time, keep the two pack leads from ever touching, and never leave a bare cell terminal exposed. Full framing lives in the [2S Li-ion safety note](bom.md#safety-note---2s-li-ion) and [Power architecture](#power-architecture).

Build the pack as its own sub-assembly and verify a clean 5 V at the DC-DC output **before** it feeds anything downstream. This is step 4 of the [Assembly order](#assembly-order); do not connect the 5 V bus to VIN or the LED ring until the meter reads right.

**1. Insulate the cell tops.**

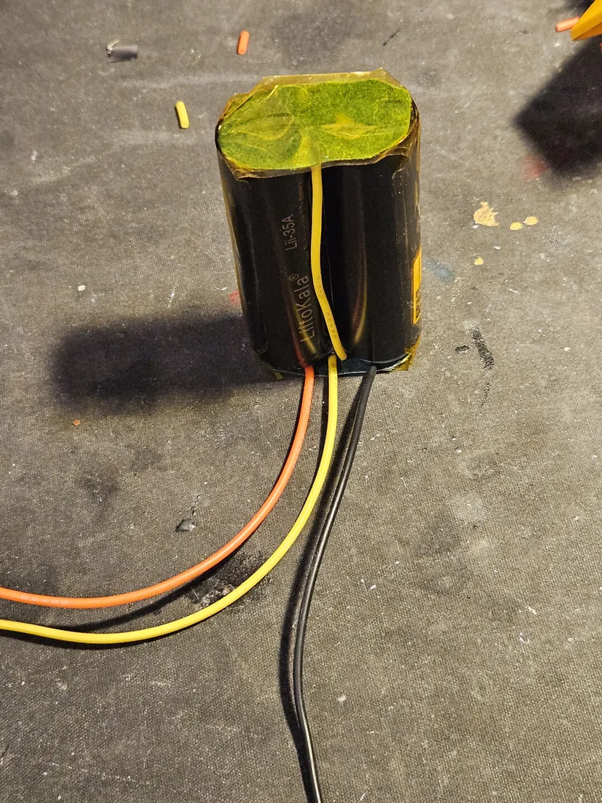
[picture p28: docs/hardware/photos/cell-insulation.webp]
Two 18650 cells taped side by side with a translucent fish-paper insulator covering the terminal ends, pack leads exiting the bottom


Lay the two cells side by side, same polarity conventions as your series plan, and cap the terminal ends with an insulating barrier before any metal goes near them. Here a sheet of fish-paper (Kapton works too) is taped down over the top of the pack so only the intended weld points are exposed. Check that the wraps on both cells are intact with no nicks down to bare steel, and that the insulator sits flat with no bare terminal ring peeking out from under the tape. The pack leads exit the opposite end.

**2. Spot-weld the series link.**

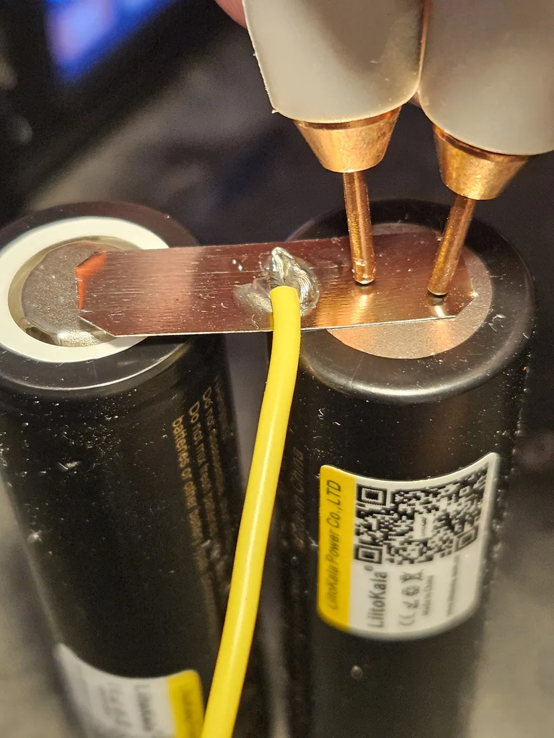
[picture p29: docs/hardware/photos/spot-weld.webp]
A spot welder pressing two copper electrodes onto a nickel strip laid across the top of a LiitoKala cell, joining it to the neighbouring cell


Bridge the two cells with a nickel strip and spot-weld it down - this is the series (2S) link that turns two cells into one 6.0–8.4 V pack. Both copper electrodes must land on the strip over the cell can, never bridging directly cell-to-cell. **Do not solder this joint** and do not guess the weld setting: dial the welder in on a scrap strip and cell first, per the welder's own guidance, until you get welds that bite without blowing through. Check each joint by tugging the strip lightly - it should not peel - and confirm you see clean weld dimples, not a scorched or lifted strip.

**3. Solder the BMS pack lead.**

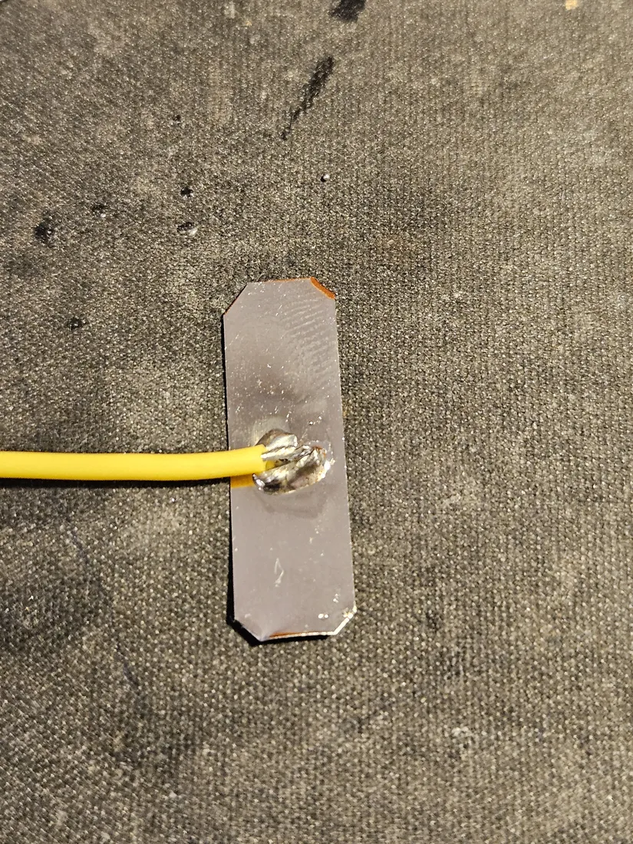
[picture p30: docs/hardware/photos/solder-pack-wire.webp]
A nickel strip with a yellow lead wire soldered to a tinned pad in its middle


Solder the pack lead to its nickel tab as shown, keeping the iron on the tab and off the cell body. Use a hot, tinned iron and get in and out fast - follow your iron's guidance rather than any fixed temperature, because prolonged heat into an 18650 is what damages it. A good joint is a shiny, concave fillet with the wire fully anchored, not a dull gray blob. Let it cool before flexing.

**4. Confirm the mid-point tap sits between the cells.**

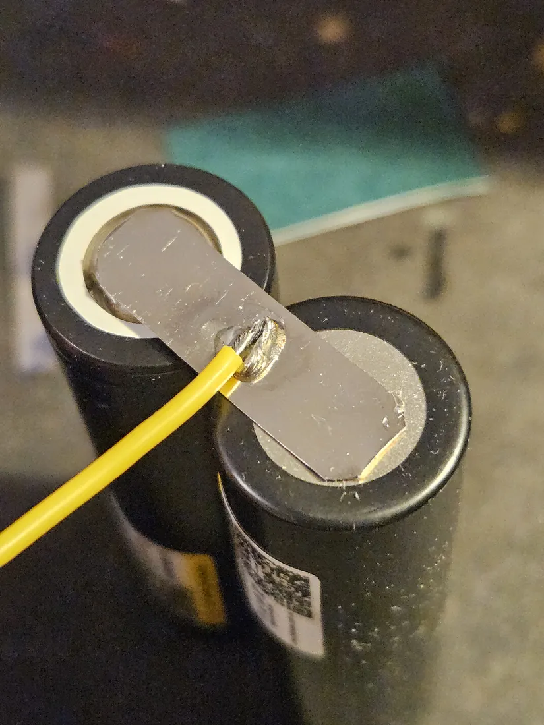
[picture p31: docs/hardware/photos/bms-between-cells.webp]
The welded nickel strip bridging the two cell terminals with the balance tap wire soldered at the series junction


The strip now joins the two cell terminals and the tap wire lands at that series junction. This mid-point is the balance/sense tap that goes to the BMS, which is what places the **BMS electrically between the cells** so it can watch each one independently. Route this tap and the two pack leads to the BMS, never straight to the DC-DC. Verify the junction is solid and the tap wire is not shorting to the adjacent cell can. If your BMS labels its tap pads differently, follow its silk screen and datasheet for which lead is the mid-point.

**5. Terminate the pack lead.**

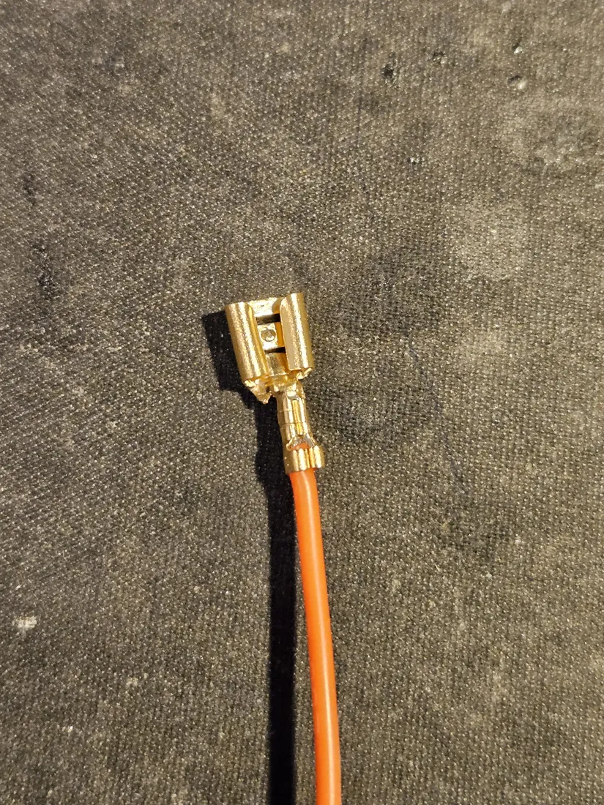
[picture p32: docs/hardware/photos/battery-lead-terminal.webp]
An orange pack lead wire with a gold female spade crimp terminal on the end


Crimp a female spade terminal onto the pack output lead so it lands on the board without a bare soldered wire flapping loose. Use the correct crimp for the wire (do not eyeball the terminal size) and crimp both the conductor barrel and the insulation grip. Check that the terminal grips copper, not just insulation, that no whiskers stick out, and give it a firm pull - it must not slide off. A heat-shrink collar over the crimp keeps it from shorting to a neighbour.

**6. Connect the pack to the board.**

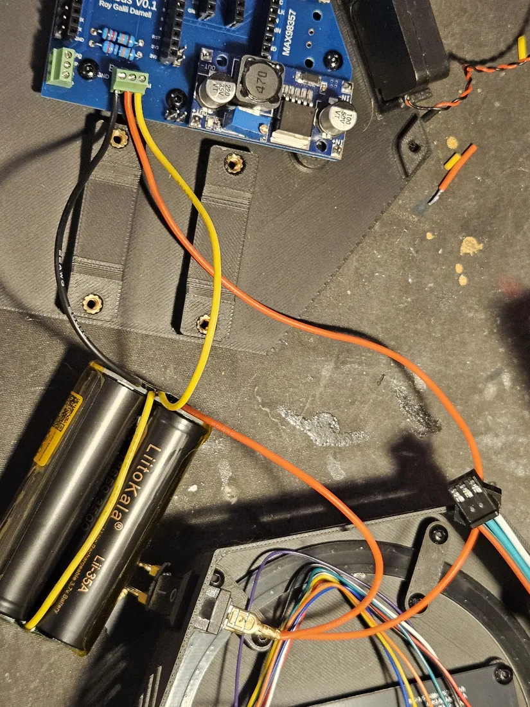
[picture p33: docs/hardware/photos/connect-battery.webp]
The 2S pack wired to the Nimbus V0.1 board: pack leads landing on the board power-input terminal, with the DC-DC converter on the board


Land the pack leads on the board so the BMS output feeds the **DC-DC input only** at this point. Get polarity right before anything is energized - a reversed pack is how boards die. Confirm every ground is common between cells, BMS, DC-DC, and the board per [Power architecture](#power-architecture). Leave the 5 V bus disconnected from the ESP32 VIN and the LED ring until the next step passes; a mis-set converter must not be allowed to reach the MCU or the ring.

**7. Calibrate the DC-DC to a clean 5 V, then stop.**

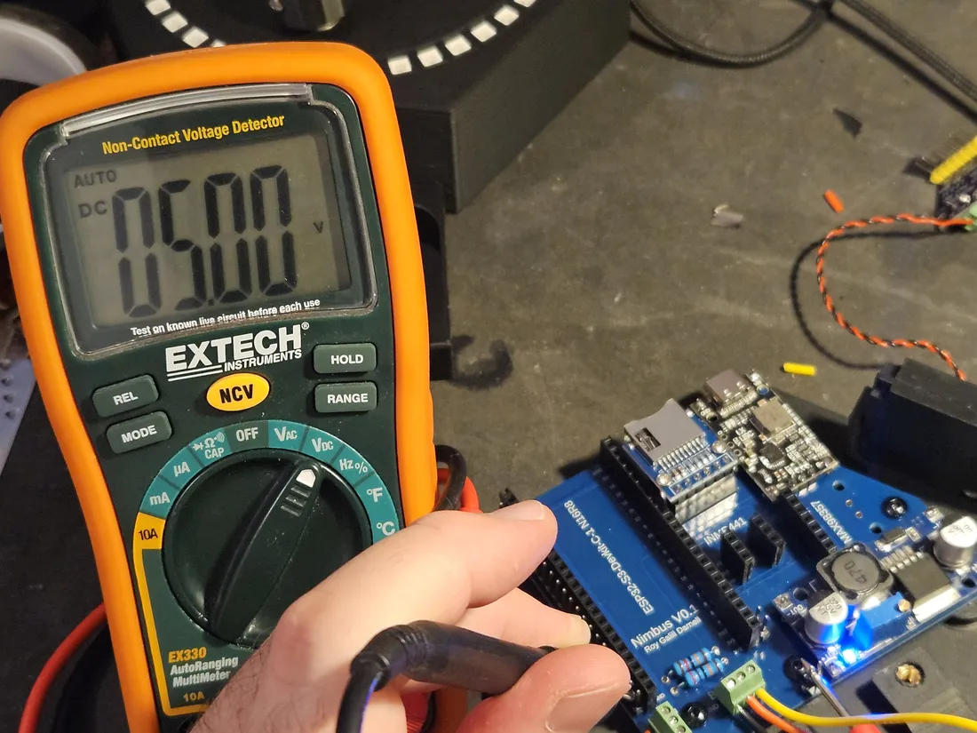
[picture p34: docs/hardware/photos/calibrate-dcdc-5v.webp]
An Extech EX330 multimeter reading 05.00 V DC beside the Nimbus board's DC-DC converter


With the pack feeding the DC-DC input and **nothing on the output yet**, set the meter to DC volts and read across the converter's OUT + and OUT -. Turn the module's trim pot until it reads a clean 5.00 V, exactly as the meter shows here. This gate is non-negotiable: a converter shipped at 8 V or wandering under load will destroy the ESP32 and the ring the instant they are connected. Only once you have a steady 5.00 V do you wire the 5 V bus to VIN and the LED ring +5 V (step 5 of the [Assembly order](#assembly-order)).

After the pack is assembled and running, charge it fully through the BMS USB-C port and run `BATTCAL` on the console so the gauge reads 100 % at full - the ADC under-reads a full pack. See [Battery pack](#battery-pack) and [Battery voltage sampling](../hardware.md#battery-voltage-sampling-how-to-add-it). Remember the firmware caps LED brightness at 60 %: sustained higher levels can overheat and damage the internal electronics, and must not be raised.

### Stack the electronics and close the case

Do the full electrical bring-up **before** anything goes into the case. Once the boards are stacked and screwed down, the pin headers and the self-test console are hard to reach - so flash and pass the self-test on the bench first, following [Assembly order](#assembly-order) steps 1-5: first flash over the UART port ([First flash of a fresh board](../hardware.md#first-flash-of-a-fresh-board-use-the-uart-port)), then `TEST all` on the self-test console with `led`/`screen`/`sd`/`memory`/`input` all PASS. A board that boots clean loose on the bench is the only board worth closing up.

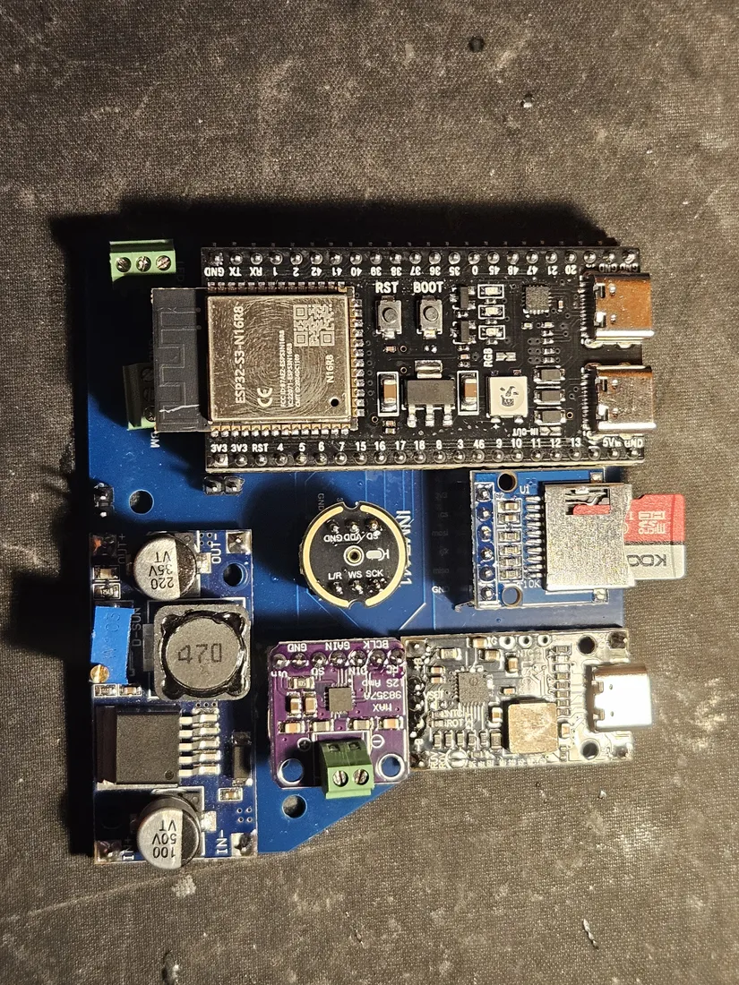
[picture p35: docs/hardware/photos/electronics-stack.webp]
Assembled Nimbus electronics seen from above: ESP32-S3-N16R8 DevKit at top with dual USB-C, the DC-DC buck converter with its two electrolytic caps and inductor at lower left, the purple MAX98357A amp and INMP441 mic in the center, the microSD module with a card seated at right, and green screw ter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


**Confirm the stack matches [Wiring](#wiring).** Top-down, every module from the pinout tables is present and seated: the ESP32-S3-N16R8 DevKit up top (both USB-C ports, RST and BOOT buttons clear), the DC-DC buck with its `220 35V` and `100 50V` electrolytics, `470` inductor, and blue output trimpot, the purple MAX98357A amp beside the INMP441 mic and the buzzer, the microSD module with a card fully home, and the BMS USB-C board. Check the microSD card is seated flush, not proud - a card that stands off the socket is the `cardType=0` trap. Green screw terminals carry the pack and 5 V leads; verify each is clamped on stripped copper, not on insulation. Keep the **2S BMS between the cells and everything else**, and **never charge the pack outside the BMS** - charge only through its USB-C port. Use brand-name cells from a reputable vendor (counterfeits are common); see the 2S Li-ion safety note in the [BOM](bom.md).

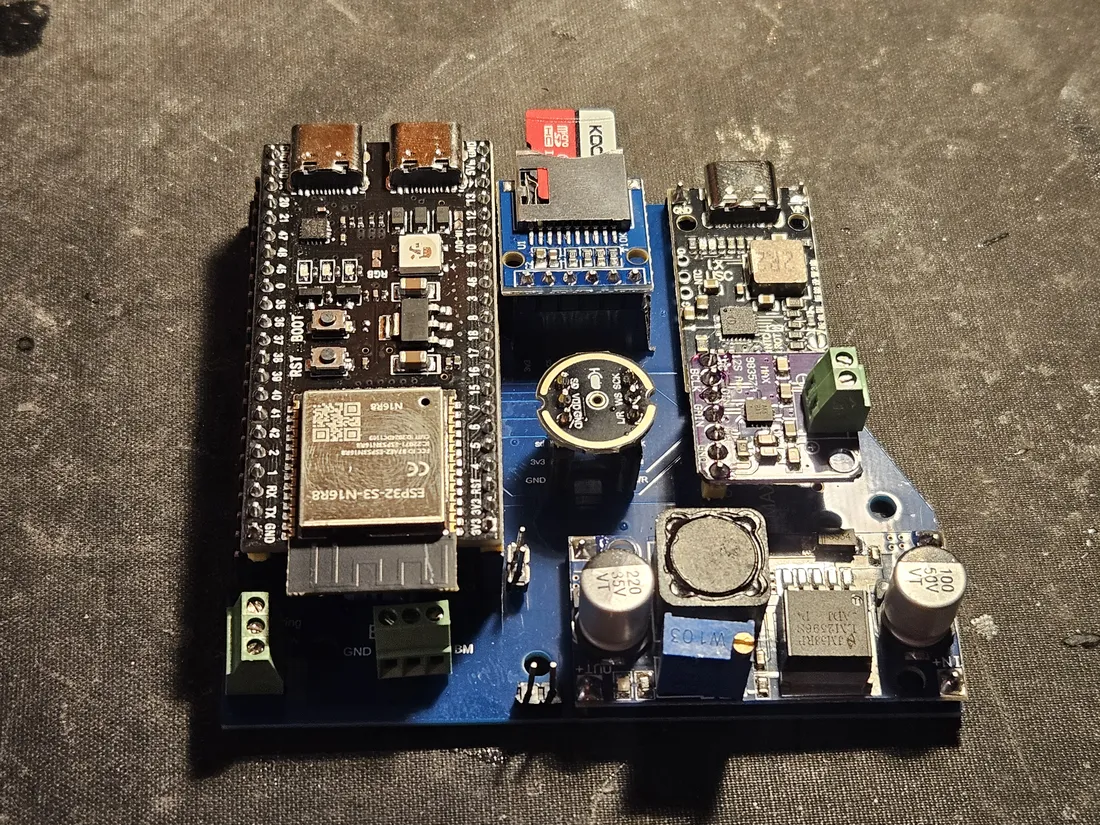
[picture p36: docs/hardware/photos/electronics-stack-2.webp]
The same electronics stack at an angle, the blue Nimbus PCB carrying all modules and resting on the black printed standoff frame, green screw terminals along the front edge


**Check the vertical stack from the side.** The tall parts - the DevKit module can, the two DC-DC electrolytics, the amp and mic breakouts - all clear each other with no board bowing and no header touching a neighbor's pads. The blue PCB seats down onto the printed standoff frame with an even gap all around; no component is crushed against the frame. Reconfirm **every ground is common** here ([Power architecture](#power-architecture)): cells, BMS, DC-DC, ESP32, and every module share one GND. A missing common ground reads as flaky peripherals, not a dead board.

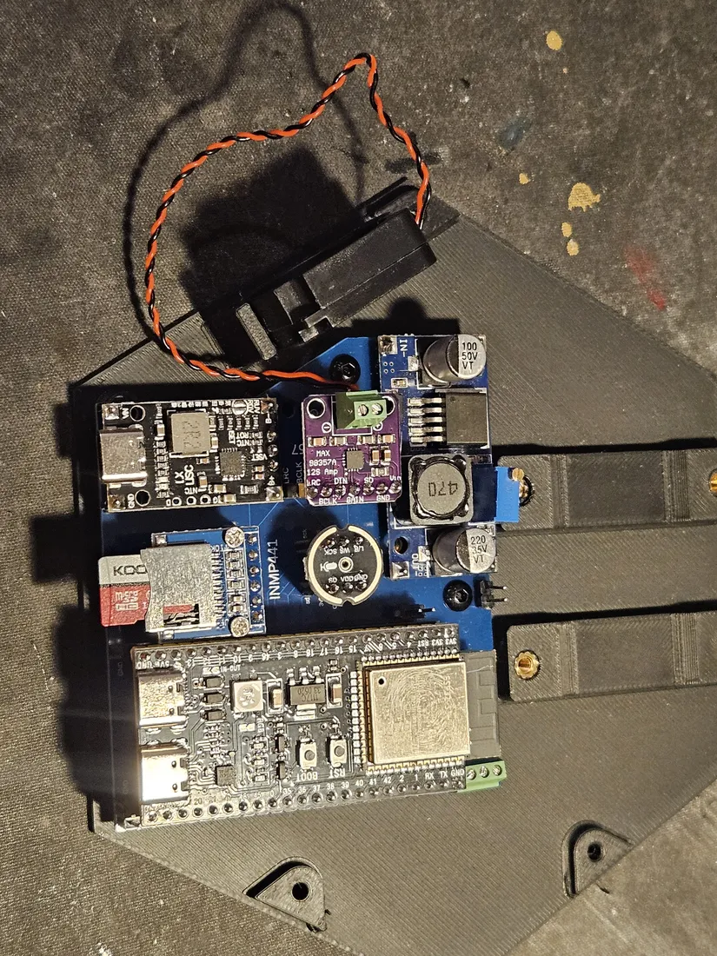
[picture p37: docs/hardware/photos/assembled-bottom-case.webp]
The blue PCB assembly lowered into the black 3D-printed bottom case, brass heat-set inserts and screw posts visible at the corners, with a separate black module and its twisted red-and-black lead pair resting loose above the case, not yet secured


**Seat the PCB into the printed bottom case.** Lower the assembly so the board mounting holes line up over the case's screw posts and brass heat-set inserts. It should drop in without forcing - if it fights, find the tall part or lead that is catching before pressing harder. Drive the case screws into the brass inserts snug, not hard; the insert strips before the plastic complains, so stop at first resistance rather than chasing a number.

**Route every lead so nothing is pinched.** Before the screws go tight, sweep all wiring - the twisted red/black lead pair and any module still to be secured - clear of the board edges, screw posts, and the case wall so nothing is trapped or crushed when the case closes. Pinched insulation is a short waiting to happen. Give the pack and 5 V-bus leads a gentle tug to confirm the screw terminals hold.

**Set the buck to 5 V before the pack feeds the stack.** The DC-DC output is adjustable at the blue trimpot, so never trust it blind. With the pack connected to the buck input but the 5 V lead still off the board, meter the buck output and confirm it reads **5 V** before you land it on the bus. A buck left high pushes past 5 V into every board on the 5 V bus and destroys them.

**One last power-on before the lid.** With the stack in the case but still openable, power up and confirm the device boots and the self-test still passes in its installed position - a fault that only appears after seating is almost always a pinched lead or a ground gone open. Keep a hand near the modules for the first minute: **a warm or hot module or SD card is an electrical fault** - kill power immediately and find the short before going further ([hot-card safety check](../hardware.md#shared-peripherals)). Only then install the production firmware ([Assembly order](#assembly-order) step 7) and close the case.

The firmware caps LED-ring brightness at 60%; leave it there. Raising it pushes ring current and heat past what the 5 V bus and this enclosure are sized for.

### Fit the touch TFT

This is the 2.8" ILI9341 240×320 panel with the XPT2046 resistive touch controller. It carries the display, the touch layer, and a microSD socket on one red module. The touch layer is the only input (see [The three on-module solder bridges (do this first)](#the-three-on-module-solder-bridges-do-this-first) and the [wiring table](#tft--touch-spi3)).

**Do the bridges first.** Before the module goes anywhere near the enclosure, the three on-module touch-to-display bridges must already be soldered and continuity-checked with power disconnected. That is not part of this step - it is the prerequisite for it. If you have not done it, stop and complete [The three on-module solder bridges (do this first)](#the-three-on-module-solder-bridges-do-this-first) now. A missing bridge is the number-one build fault and produces a blank display or dead touch with no error anywhere.

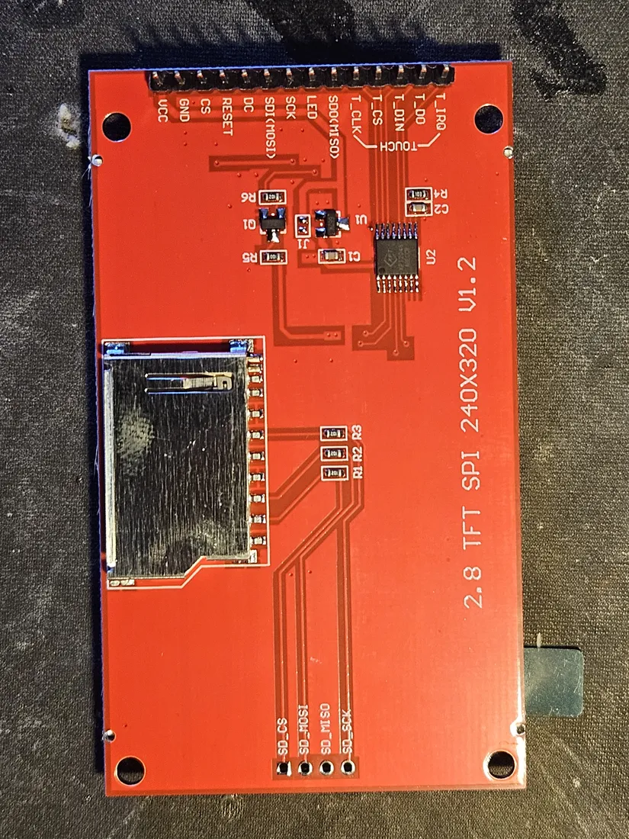
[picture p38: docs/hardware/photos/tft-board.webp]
Back of the 2.8 inch ILI9341 SPI TFT module, showing the single top header carrying the display, power, and touch pins, the XPT2046 controller, and the microSD socket


**Identify the pads before wiring.** Work from the back of the module. The long header along the top carries the display and power pins - `VCC`, `GND`, `CS`, `RESET`, `DC`, `SDI(MOSI)`, `SCK`, `LED`, `SDO(MISO)` - and the touch pins `T_CLK`, `T_CS`, `T_DIN`, `T_DO`, `T_IRQ`. The silk reads **2.8 TFT SPI 240×320 V1.2**; confirm yours matches. The microSD socket and its own `SD_CS / SD_MOSI / SD_MISO / SD_SCK` pads sit lower on the board - those are the separate SPI2 bus and are **not** part of this panel's wiring. Land each wire per the [TFT + touch (SPI3)](#tft--touch-spi3) table. Leave `T_IRQ` unconnected.

Finished touch-TFT Nimbus, enclosure open: the red TFT module mounted in the lid inside the LED ring, wired back to the ESP32-S3 carrier in the base

**Seat the module in the lid.** Mount the panel face-out in the enclosure lid so the glass sits centered inside the WS2812B ring, as shown. Route the display and touch harness back to the ESP32-S3 carrier in the base, keeping the bundle clear of the ring so the lid can close. Dress the wires so nothing is pinched at the hinge. The base carries only the DevKit and the shared peripherals (mic, amp, microSD, power section), and the panel is the sole input.

**Check before you close it up.**

- Every ground is common - the panel `GND` ties back to the same node as the cells, BMS, DC-DC, ESP32, and every other module.
- The panel `VCC` is on **3.3 V**, not the 5 V bus.
- Run the bring-up sketch (`pio run -e tftbringup -t upload`) and confirm color bars, the backlight fade, and raw touch before installing the production firmware. Uncalibrated touch looks identical to broken touch, so calibrate ([Touch calibration](touch-tft.md#touch-calibration)) before concluding anything is miswired.
- If the panel or the SD card ever runs warm or hot, that is an electrical fault: power off first, then investigate ([hot-card safety check](../hardware.md#shared-peripherals)). A shorted SD socket can brown out or damage the display even though the two buses are separate.

The backlight is a continuous draw whenever the screen is lit. It sits on a PWM pin and the firmware blanks it when idle. The firmware caps LED ring brightness at 60%; do not raise it.

## Assembly order

The photo-by-photo build is the [Assembly walk-through](#assembly-walk-through)
above; the same shots gathered on one page are the [build photos](build-photos.md).

1. **Solder the three touch-to-display bridges on the module** and
   continuity-check them (section above). Doing this before any board wiring
   makes the check unambiguous.
2. **Bench-check the bare DevKit.** Flash it over the **UART** USB-C port - on
   a factory-fresh board the native USB port has no path into download mode,
   so getting this wrong looks like a dead board. See
   [First flash of a fresh board](../hardware.md#first-flash-of-a-fresh-board-use-the-uart-port).
3. **Wire the TFT module** per the table above, then run the standalone
   bring-up sketch - it exercises the panel, colors, backlight, and raw touch
   without the full firmware:
   ```bash
   pio run -e tftbringup -t upload
   ```
4. **Wire the remaining 3.3 V peripherals on USB power** - microSD, mic, amp.
5. **Build the power section separately**: cells into the 2S BMS, BMS output
   into the DC-DC. Verify a clean 5 V at the DC-DC output with a meter before
   connecting anything.
6. **Connect the 5 V bus**: LED ring +5V and the ESP32 VIN. Confirm every
   ground is common.
7. **Add the battery-sense divider** if you want a battery gauge.
8. **Install the production firmware** with the guarded installer:
   ```bash
   python3 tools/setup_device.py
   ```
   The installer stores `scrModel=tft` so the board binds its display and touch
   drivers on the first boot.
9. **Calibrate the touch panel.** Every resistive panel reads differently, so
   the raw-count-to-pixel mapping is measured per unit - until it is set,
   taps land somewhere else and touch looks broken. Run the wizard:
   ```bash
   python3 tools/tcal_wizard.py --port /dev/cu.usbserial-XXXX
   ```
   Full detail: [Touch calibration](touch-tft.md#touch-calibration).

## Known traps

- **The three bridges are the number-one build fault.** A missing bridge
  produces a blank display or dead touch with no error anywhere - see the
  continuity check above.
- **Reachable GPIOs are nearly all consumed.** Only the J3 header is reachable
  on the carrier, GPIO 35/36/37 (octal PSRAM) sit in the middle of it, and the
  longest usable contiguous run is seven pins (`1, 2, 42, 41, 40, 39, 38`) -
  all consumed by the panel. The documented free spares are on J1, which the
  carrier does not break out. GPIO 47 is the only genuinely free reachable pin
  on this variant.
- **The backlight is a continuous draw.** Plan for it in battery estimates;
  the firmware blanks it when idle rather than drawing a screensaver, because
  on a TFT showing nothing is cheaper than showing anything.
- **The touch controller is slow.** The XPT2046 tops out near 2 MHz against
  the panel's 40 MHz, so each device gets its own SPI transaction settings.
  Getting this wrong does not fail loudly - it returns plausible-looking
  garbage coordinates.
- **Uncalibrated touch is indistinguishable from broken touch.** Calibrate
  before concluding anything is miswired
  ([Touch calibration](touch-tft.md#touch-calibration)).
- **The SD card must be FAT32, not exFAT.** Cards over 32 GB ship
  exFAT-formatted by default and mount as `cardType!=0, ok=false`. Reformat as
  FAT32 ("MS-DOS (FAT)" on macOS) before first use.
- **A cold SD ground joint reads as `cardType=0`** - the card looks absent,
  not faulty. Check continuity from the SD module's GND to system GND before
  suspecting the card.
- **A warm or hot SD card is an electrical fault.** Disconnect power
  immediately - see the
  [hot-card safety check](../hardware.md#shared-peripherals). An SD power
  fault can brown out or damage the display even though the buses are
  separate.
- **Never route anything to GPIO 33–37** (octal PSRAM on the N16R8), nor to
  0/45/46 (strapping), 19/20 (USB), 43/44 (UART), 26–32 (flash).
- **If the panel ever goes blank white**, read the
  [white-screen investigation](touch-tft.md#the-white-screen-what-was-ruled-out-and-what-was-not)
  before re-measuring anything - the field cause was traced to the device's
  own SoftAP radio disturbing a jumper-wired panel, the firmware now avoids
  it, and a watchdog bounds any residual symptom to about 5 seconds.

## Battery pack

Two 18650 cells in series (2S, 6.0–8.4 V range) behind the BMS. Ground truths
from the reference pack, measured on a dedicated analyzer: **3500 mAh
capacity, 8.40 V full**. Measured runtimes on that pack:
5.75 h at ring brightness 77/255 (608 mA average), about 23 h idle (~150 mA).
The TFT backlight adds continuous draw on top of those figures whenever the
screen is lit. Details in
[Measured battery reality](../hardware.md#measured-battery-reality-curve-run-4-board-2-2026-07-16).

Note that the ADC under-reads a full pack - after assembly, charge fully and
run `BATTCAL` (console) so 100 % reads as 100 %. See
[Battery voltage sampling](../hardware.md#battery-voltage-sampling-how-to-add-it).

## Enclosure and CAD

A 3D-printable enclosure for this build is published:
**[`hardware/fab/nimbus_classic_case.stl`](https://github.com/ristllin/Nimbus/blob/main/hardware/fab/nimbus_classic_case.stl)**
(GitHub renders it in a 3D viewer). Print in PLA or PETG; the main body needs no
supports on most printers. The
[`hardware/fab/`](https://github.com/ristllin/Nimbus/tree/main/hardware/fab) folder
also holds the PCB manufacturing outputs (Gerbers, ODB++) and
[how to order the board](https://github.com/ristllin/Nimbus/tree/main/hardware/fab#ordering-the-pcb).

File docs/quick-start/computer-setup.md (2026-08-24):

<!-- audience: user -->
# Set up your computer

For anyone who has never opened a terminal. By the end you will have the tools
the command-line flasher needs: a terminal, Python 3, PlatformIO, and (on some
computers) a USB-serial driver.

:::tip Most people can skip this page
The **[browser flasher](flash.md#path-1---browser-flasher-recommended)** needs
none of the below. All it takes is a Chromium-based browser (Chrome or Edge) and
a data-capable USB cable. Come here only if you want the command-line path, or the
browser flasher never shows your board's serial port.
:::

## 1. Open a terminal

The terminal is a window where you type commands. Opening it is all step 1 asks.

- **macOS:** press Cmd+Space, type `Terminal`, press Enter.
- **Windows:** press the Start key, type `PowerShell`, press Enter.
- **Linux:** press Ctrl+Alt+T, or search your apps for `Terminal`.

Type a command, press Enter, read the result. That is the whole skill.

## 2. Install Python 3

Nimbus's installer is a Python program, so you need Python 3.8 or newer.

- **macOS / Windows:** download the installer from
  [python.org/downloads](https://www.python.org/downloads/) and run it. On
  Windows, tick **Add Python to PATH** on the first screen.
- **Linux:** it is almost always already there; if not, install `python3` and
  `python3-pip` from your package manager.

Check it worked:

```bash
python3 --version
```

You should see `Python 3.something`. If Windows says `python3` is not found, try
`python --version` instead.

## 3. Install PlatformIO

PlatformIO builds and uploads the firmware. Install it with Python's package
tool:

```bash
pip3 install platformio
```

Check it worked:

```bash
pio --version
```

If the command is not found, close and reopen the terminal so it picks up the new
tool, then try again.

## 4. Install a USB-serial driver (only if needed)

The Nimbus board's **UART** port talks to your computer through a CP2102N chip.
macOS and modern Windows and Linux usually recognize it with no driver. Install
one only if the flasher never lists a serial port for a connected board:

- Download the **CP210x** driver from
  [Silicon Labs](https://www.silabs.com/developer-tools/usb-to-uart-bridge-vcp-drivers),
  install it, then unplug and replug the board.

The **all-in-one (Freenove CYD)** board rides the ESP32-S3's own USB and needs no
driver on any current operating system.

## 5. Get the firmware and flash

You are ready for the command-line path. Clone the firmware repository, then run
the installer:

```bash
git clone https://github.com/ristllin/Nimbus.git
cd Nimbus
python3 tools/setup_device.py
```

The installer finds your board, confirms before it writes, and never erases an
already-configured device. Full flashing steps, flags, and recovery:
**[Flash the firmware](flash.md)**.

---

*Next step: [Flash the firmware](flash.md)*

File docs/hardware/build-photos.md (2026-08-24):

# Build photos

A photo walk-through of an actual Nimbus build, in assembly order. These
complement the step-by-step wiring and assembly in the
[touch TFT](build-tft.md) guide.

## Printed parts and heat-set inserts

The 3D-printed enclosure parts laid out
Heat-set threaded inserts pressed into the top case
Heat-set threaded inserts pressed into the bottom case

## Board and custom PCB

The ESP32-S3-DevKitC-1 N16R8 dev board
Custom Nimbus carrier PCB, top side
Custom Nimbus carrier PCB, back side
PCB layout / silk reference
Female headers fitted to the carrier board
Modules seated on the assembled carrier board
Assembled carrier board, underside
Carrier board with the BMS charger and DC-DC converter
The peripheral modules before assembly

## LED ring and audio

WS2812B 45-pixel LED ring
LED ring with one power ribbon cut for the case pass-through
Full-range 4 ohm speaker
Speaker mounted in the case
Rocker switch pressed into place
Longer screws for the microSD holder

## Battery pack (2S)

Cells wrapped in fish-paper and Kapton tape
The 2S BMS seated between the 18650 cells
Spot-welding the cell tabs
Soldering the BMS pack lead
Battery pack lead terminal
Connecting the battery to the board
Calibrating the DC-DC converter to a clean 5 V

## Electronics assembled

All electronics assembled
All electronics assembled, other angle
The stack fitted into the bottom case

## Display - touch TFT build

2.8 inch ILI9341 touch TFT module
Assembled touch-TFT Nimbus

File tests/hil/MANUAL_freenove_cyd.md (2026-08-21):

# Manual bench validation - Freenove ESP32-S3 CYD (FNK0104B)

These are the hardware checks that firmware cannot self-verify. Run them on the
physical Freenove board. Each step says what to flash, what to do, and the pass
condition. Already validated during development: **display first light** (panel
lights, correct colors) and **capacitive touch reads** (via `tfttouch-cyd`).

## Console note (important)

The ESP32-S3 USB-Serial-JTAG on this board is finicky over macOS serial: opening
the port can bounce the chip into ROM download mode (firmware halts, panel freezes
on its last frame). Prefer the **on-screen / by-ear** bring-up sketches below,
which need no console. If you do need the console (`STATUS`, `SELFTEST`), flash
`test-cyd`, open the monitor once right after upload, and avoid re-opening.

MAC-verify the port before every flash: it is `28:84:85:42:18:fc`.

```bash
pio run -e <env> -t upload --upload-port /dev/cu.usbmodemXXXX
```

## 1. Display + touch (bring-up sketch, on-screen)

- Flash `tfttouch-cyd`.
- The screen flashes white then black on boot. Touch it: the screen fills a solid
  color by quadrant (top-left red, top-right green, bottom-left blue, bottom-right
  yellow with the shipped default), black when you lift off.
- **Pass:** touching changes the color, and the four corners map sensibly. If the
  mapping is rotated/mirrored, adjust the default in `src/main.cpp` (the capacitive
  touch `Calibration` - currently `swapXY=true, invertY=true`).

## 2. Audio - speaker + microphone (bring-up sketch, by ear)

- Flash `audio-cyd`. It loops: a 440 Hz beep, then a ~1.5 s record, then plays the
  recording back.
- **Pass (speaker):** you hear a clean beep each cycle. The external power amp is
  enabled in codecInit (GPIO1, active-low); if the beep is silent but the codec
  reports OK, probe GPIO1 (should read LOW while audio is up) and confirm the amp
  chip has power.
- **Pass (microphone):** speak during the "recording..." window; you hear yourself
  played back a moment later.
- If silent: the beep alone failing points at the codec DAC / I2S TX / amp; the
  beep working but no echo points at the codec ADC / mic / I2S RX. The ES8311
  register init or MCLK clocking is the usual cause - this path is new.
- Mic note: the ES8311 RX shares the speaker's stereo I2S slot config, so a mono
  mic arrives interleaved. The record path now collapses each frame to the louder
  slot (codecStereoToMono), so playback should be clean mono at normal pitch. If
  the echo is half-speed / low-pitched or every other sample is silent, the
  de-interleave is not taking effect - check that the codec (kCodec) build path is
  active for this board.

## 3. Touch inside the real UI (production firmware)

- Flash `test-cyd`. If this is the board's first Nimbus boot, set the panel over
  the console once: send `SCREEN tft` (persists and restarts). It then boots into
  the color UI.
- Complete Wi-Fi setup (see the setup wizard) so the device leaves the onboarding
  screen, OR open the settings menu.
- **Pass:** tapping menu rows / cards highlights and navigates at the spot you
  touch. If taps land offset, revisit the touch calibration default (step 1).

## 4. microSD (SDMMC)

- Insert a **FAT32** card (reformat cards over 32 GB - they ship exFAT).
- With `test-cyd` running, over the console run `STATUS` and read the `sd=` field,
  or run `SDCHECK`.
- **Pass:** `sd=present` and `SDCHECK` reports a size. This path is new (SDMMC, not
  SPI) and was not bench-validated during development.

## 5. Battery (only if a 1S Li-ion pack is fitted)

- Fit a single-cell Li-ion pack to the battery port. On `test-cyd`, `STATUS`
  reports the pack voltage.
- **Pass:** a plausible per-cell voltage (3.3-4.2 V). The boot log no longer prints
  "not configured as analog channel" (the sense pin is now GPIO 9). If the voltage
  reads wrong, set the divider in web Settings (this board is divide-by-2).

## 6. On-screen ring (Notifier mode, no physical ring)

- With `test-cyd` in Notifier mode, drive a session from a host broker (or inject a
  frame). The color panel draws a ring of dots on the right, cards on the left.
- **Pass:** each active session shows an arc of dots in its status color, and the
  focused session's cursor glow tracks - the same information the LED ring gives on
  the hand-built boards. The single on-board RGB LED (GPIO 42) is a status pixel,
  not the ring.
- **Not a bug:** the ring/panel shows literally whatever the connected broker sends.
  If your broker has stale sessions from earlier test runs, you may briefly see more
  "active" dots than you expect, mostly dim (Idle sessions render dim/white by
  design). This self-heals within `ambientHoldFor(posture)` of no further frames for
  a stale session (5s Dark / 30s Calm / 300s Full) - the device's own timeout, not a
  reconnect you need to trigger. If it never converges, the broker itself is the
  thing to check (it should prune dead sessions before it connects), not the device.

## 7. Wi-Fi, memory, a full turn

- These reuse the existing HIL layers (they are board-agnostic): `test_l4`
  (Wi-Fi), `test_l23` (stack health). Run the Freenove-specific layer:

```bash
python3 -m pytest tests/hil/test_l27_freenove.py -m "hil and not manual" --allow-hardware
```

- For Orchestrator mode: add a provider key, then over Telegram or by voice
  (hold-to-talk on the mic bar) run one turn and confirm a reply.
- **Pass:** the device completes one turn end to end.

## What was already proven vs. what needs you

| Subsystem | Status |
|---|---|
| Display (panel, colors, backlight) | Validated on hardware (dev) |
| Capacitive touch reads | Validated on hardware (dev) |
| Touch orientation in the UI | Needs step 3 |
| Speaker (ES8311 DAC + amp) | Power-amp enable (GPIO1, active-low) landed; confirm the beep in step 2 |
| Mic (ES8311 ADC) | Stereo-to-mono de-interleave landed; confirm clean echo in step 2 |
| microSD (SDMMC) | Needs step 4 - NOT yet bench-validated |
| Battery sense | Needs step 5 |
| On-screen ring | Needs step 6 |
| Wi-Fi / memory / a turn | Needs step 7 |

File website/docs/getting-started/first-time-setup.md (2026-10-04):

---
title: "First-time setup"
sidebar_label: "First-time setup"
description: "From a new board to a Nimbus you can talk to. A short, foolproof path: flash, power on, join the setup Wi-Fi, add one provider key. About ten minutes, no serial console."
---

# First-time setup

New board to a device you can talk to, in about ten minutes. No serial console.
After the one-time firmware install it asks for just two things: your Wi-Fi and
one AI provider key.

The whole path, detailed below:

1. **Flash the firmware** once. It seeds the display for you.
2. **Power on.** The device shows its setup Wi-Fi network and a sign-in QR.
3. **Join that Wi-Fi.** A setup page opens by itself, already signed in.
4. **Walk the wizard:** pick your Wi-Fi, add one provider key. Done.

:::danger Get your provider key before step 1
Setup puts your phone or laptop on the device's own Wi-Fi, which has **no
internet**, so you cannot fetch a key partway through. Create it first and keep it
pasteable on the same device you will set up from. Step-by-step for each provider:
[Get your provider key](../quick-start/provider-keys.md).
:::

:::tip The two things you cannot skip
Your **home Wi-Fi** and **one verified provider key**. Everything else (SD card,
Telegram, voice, device name) is optional and can wait. If you only want the
Notifier status light, you do not even need a provider key. See
[Notifier quick start](../quick-start/notifier-quick-start.md).
:::

---

## 1. Flash the firmware

If this is an already-configured Nimbus, skip to [step 2](#2-power-on).

Two ways to install. Both seed the display, so the board comes up on the right
panel with no display question:

- **From your browser** (easiest): open [Flash Nimbus](/flash) in Chrome or Edge,
  pick your board, and click Install. Nothing to download.
- **From the firmware repository:**

  ```bash
  python3 tools/setup_device.py
  ```

  The installer lists connected boards, detects the family, and asks only what it
  cannot know: the **operating mode**, and on a Freenove the **panel size**. It
  confirms before writing and never erases saved settings.

  | It asks | Options | What it sets |
  |---|---|---|
  | Operating mode | 1. Notifier · 2. Orchestrator | Notifier uses Bluetooth with Wi-Fi off; Orchestrator turns on Wi-Fi and the web UI |
  | Panel size *(Freenove only)* | 2.8 / 3.5 / 4.0 inch | Matches the firmware image to your glass |

:::caution Classic Nimbus board: use the port labeled UART
The hand-built Nimbus board (the DevKitC-1) has **two** USB-C ports. On a fresh
board, only the one silkscreened **UART** can flash it: a board that "won't flash"
is almost always on the wrong port, not broken. The Freenove has a single port, so
there is no wrong one to pick.
:::

<details>
<summary>I flashed <code>[env:provision]</code> or a bring-up sketch by mistake</summary>

Those are standalone diagnostics with no Nimbus UI, setup Wi-Fi, or web
settings. Run `python3 tools/setup_device.py` (or the browser flasher) to install
the real firmware. Saved settings are preserved.

</details>

---

## 2. Power on

Power the board over USB-C. What you see depends on the mode you flashed:

- **Orchestrator** shows its **setup Wi-Fi network name** and a **sign-in QR**.
  Continue below.
- **Notifier** shows Bluetooth pairing guidance instead, and keeps Wi-Fi off to
  leave room for Bluetooth. Follow the
  [Notifier quick start](../quick-start/notifier-quick-start.md) and you are done.

### The device names itself

A brand-new Orchestrator names itself: it looks for other Nimbus devices nearby,
then numbers itself.

| Device | Setup Wi-Fi network | Address on your network |
|---|---|---|
| the first one | `Nimbus-setup` | `nimbus.local` |
| a second nearby | `Nimbus-2-setup` | `nimbus-2.local` |
| a third | `Nimbus-3-setup` | `nimbus-3.local` |

It counts only the setup networks that are on when it first starts. A device that
has already joined your Wi-Fi turns its setup network off, so a device added later
can also call itself `Nimbus`, and one of the two then needs a new name.

Rename it later under **Settings > Mode & identity**. One name drives the setup
Wi-Fi, the network address, the Bluetooth name, and what the assistant calls
itself; a rename takes effect on the next restart.

---

## 3. Join the setup Wi-Fi

On your phone or laptop, join the network shown on the screen:

Two steps, in order - the same two the device screen shows:

1. **Join the setup network** shown on the panel:
   - **Network:** `Nimbus-setup` (or the name your screen shows)
   - **Password:** shown on the device screen, unique to your device. Or scan
     the on-screen QR to join automatically.
2. **Open the setup page.** It usually opens by itself, already signed in (the
   QR carried the code). If nothing opens, browse to `http://192.168.4.1`. Do
   not use `nimbus.local` for this first hop; it can point at a different Nimbus.

On that page, pick your home network, type its password, and click **Connect**.
The wizard records the device's exact LAN address, waits while your phone or
computer rejoins its normal Wi-Fi, then continues on its own at the provider
step (a manual continuation link stays visible).

:::note Wi-Fi requirements
- The radio is **2.4 GHz only** - a 5 GHz-only network won't appear in the scan.
- SSIDs are case-sensitive.
- "Home Wi-Fi connected" with "setup hotspot off" is the healthy state after
  handoff - the temporary `Nimbus-setup` network closes once the device joins
  your router, and returns if the LAN link is lost.
:::

---

## 4. Walk the wizard

The wizard asks for two required things and lets you skip the rest.

| Step | Required? | What to do |
|---|---|---|
| **Connect to Wi-Fi** | Yes | Tap **Scan**, pick your home network, type its password, **Connect**. |
| **Provider key** | Yes, one verified key | Paste an API key and click **Verify**. |
| Operating mode | Optional | Keep what you flashed, or change it (a change restarts the device). |
| Telegram | Optional | Add a bot token later. |
| Voice | Optional | Dictation and spoken replies default to Mistral. |
| Device name | Optional | Rename it now or later. |

**Which provider key?** Any one verified key runs the assistant. **Mistral is the
easiest start:** free tier, and the voice default. OpenAI and Anthropic work too.
Not sure how to create one? [Get your provider key](../quick-start/provider-keys.md)
walks each provider step by step. Keys are write-only: a saved key shows as "set"
and is never displayed again.

:::info On a touchscreen board, keep the wizard open
When the device joins your Wi-Fi, its setup network shuts down (to protect the
panel from its own radio) and the wizard **follows the device to its new address
automatically**. Seeing "home Wi-Fi connected, setup hotspot off" is the healthy
end state, not a failure.
:::

:::caution Using only a Mistral key? Set embeddings before your first turn
Long-term memory's embedding provider defaults to OpenAI, and it is a
**set-once** choice: changing it later erases the stored memory. If Mistral is
your only key, open **Memory & Files > Memory settings** and switch the embedding
provider to **Mistral before your first conversation**, while the memory is still
empty and there is nothing to lose.
:::

That is the whole setup. The wizard lands on the **dashboard** at the device's
address, and **you are ready to talk to it.** Jump to
[your first turn](#your-first-turn), or add the optional pieces below.

---

## Optional: add an SD card

The microSD card holds long-term memory, media, and logs. Without one everything
still works, just with lower limits.

1. **Format it as FAT32** ("MS-DOS (FAT)" in macOS Disk Utility). Cards over
   32 GB ship as exFAT and **will not mount** until reformatted.
2. **Insert it fully**, then **tap the SD card row** in the Settings menu. It
   re-checks the card in place, no restart needed. A mounted card shows its free
   space; an unseen one shows "none, click to retry".

## Optional: connect Telegram

To reach the assistant from Telegram:

1. Create a bot with [@BotFather](https://t.me/BotFather) and paste its **bot
   token** into **Assistant > Connectors > Telegram**.
2. **Message your bot once** from your own Telegram account.
3. Your message appears as a **pending approval card**. Click **Approve**. No
   chat-ID hunting.

Token and allowlist changes take effect after a restart.

:::caution Open access is off for a reason
The **Open access** checkbox lets anyone who finds your bot use it, and your API
credits. Leave it off unless you mean to run a public bot.
:::

## Optional: routing and a local model

One verified key is enough. If you want a specific provider to lead, set the
**Primary provider** and **Fallback order** under **Assistant > Models > Routing**.
The defaults are sensible.

<details>
<summary>Point the assistant at a local model (Ollama)</summary>

Under **Custom endpoint**:

- **Base URL:** `http://<your-computer-ip>:11434/v1` (plain `http://` uses LAN
  HTTP, no TLS)
- **Wire:** `openai`
- **Model:** e.g. `qwen2.5`
- **API key:** leave blank

Then set the **Primary provider** to **Custom** if you want it to lead.

</details>

:::note Verify keys from Orchestrator mode
Verifying a key needs a large block of memory for the secure handshake, which
Notifier mode (with Bluetooth up) does not have. The UI hints this if you try it
there.
:::

---

## Your first turn

- **Telegram:** send the bot a message. It runs a turn and replies, sometimes
  with voice if it chooses to speak.
- **On the device:** press and hold the **on-screen mic bar** to talk, then
  release to send. The ring shows your theme color while listening, then a
  spinner from the moment you let go until the reply lands.

That is it, the device is live. From here, the
[web UI reference](webui-reference.md) walks every settings tab, and
[Orchestrator World](../guides/orchestrator-world.md) explains memory, sessions,
and the tool loop.

---

## Signing in from another browser

First-time setup never makes you handle the access token; the wizard carried it
for you. For a **later** browser, or a device configured by older firmware:

1. **Scan the sign-in QR** on the device screen with your phone. It opens the
   settings page already signed in.
2. If you browse in without it, a **Sign in to Nimbus** page appears. Scan the QR
   (on the device: **Settings > Connectivity > Sign-in QR**). You identify once
   per browser; the device remembers it after that.

<details>
<summary>The screen is unavailable and I cannot scan or read the code</summary>

Connect the board's **UART** port and run:

```bash
python3 tools/setup_device.py --show-token
```

It identifies the board, prints only the existing sign-in token, and restores the
firmware afterward. It does not erase saved settings. Then open
`http://<device-address>/?t=<token>`.

</details>

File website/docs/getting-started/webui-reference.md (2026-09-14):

---
title: "Web UI reference"
sidebar_label: "Web UI reference"
description: "Every destination of the Nimbus web app: Home, Chat, Memory, Assistant, and Device, plus global search and sign-in."
---
<!-- audience: user -->

# Web UI Reference

The device serves its own web app at `http://nimbus.local` (or its LAN IP) from
any browser, nothing to install. Five destinations sit in a left sidebar on
desktop, collapse to icons in a narrow window, and dock as a bottom bar on a
phone. The content column centers up to 1,280 px.

| Destination | What it's for |
|---|---|
| [Home](#home) | Status tiles, quick actions, active sessions, alerts |
| [Chat](#chat) | Message the assistant, drop files into the conversation |
| [Memory](#memory) | Directive, long-term memory, scratchpad, and files |
| [Assistant](#assistant) | Models, connectors, tools, skills, routines, usage, safety (seven exclusive subtabs) |
| [Device](#device) | Display, sound, battery, network, updates, cloud, danger zone |

Controls that sit outside the destinations:

- **Search** - a command palette over everything (see [Global search](#global-search)).
- **Mode switch** - **Notifier** / **Orchestrator**, at the top of the sidebar.
  Switching modes restarts the device.
- **? buttons** - many fields carry a small **?** next to their label. Click it
  to expand a short explanation inline; click again to hide it.

Every action shows its progress: a pending state, then a result (success,
nothing found, or an error that names the next step). Nothing just disappears.

On a fresh or factory-reset device started in **Orchestrator**, a **First-time
setup** wizard opens over the setup network and walks through the display, Wi-Fi,
one provider key, and a few optional steps, then finishes into Home with a "what
next" card. Notifier intentionally keeps Wi-Fi and this web UI off. See
**[First-time setup](first-time-setup.md)**.

## Signing in

The page shows nothing until the browser is signed in. Normally you scan the
device's **Sign-in QR** (**Device > Connectivity** on the screen): it signs the
browser in with a one-time code, nothing to copy or type. Once per browser; the
credential is stored locally and sent as a request header, never in the URL.

If a QR cannot be scanned, the full-screen **Sign in to Nimbus** gate also
accepts the **Device sign-in code**, shown on the device screen. Generating a new
code (**Device > Connectivity > Generate New Code**) signs out every browser
except the one that requested it. The model behind all this is in
**[Security posture](../guides/security.md)**.

## Global search

Press **Ctrl/Cmd+K** or **/** (or click **Search** in the sidebar) to open one
search over everything: destinations and actions, files, long-term memory, active
sessions, and the device's embedded documentation. Results are grouped by source;
Up/Down move the selection, Enter opens it, Esc closes. The fastest way to a
setting, file, or memory without hunting through tabs.

---

## Home

Health, activity, and anything that needs your attention. The panel refreshes
every few seconds.

- **Tiles** - live figures with their scale and thresholds: free RAM, PSRAM,
  battery (corrected voltage and time-left estimate), die temperature, and the
  current mode with its active-session count.
- **Quick actions** - one-click jumps to the things people do most: open Chat,
  add a file, providers and models, check for updates, **Restart**, and
  **Power off**. Restart confirms first, then reconnects on its own in about a
  minute; Power off puts the device to sleep (the same flow as Settings > Power).
- **Active sessions** - the live table of what the assistant is running right
  now, each row named by its session with its provider, model, category, and
  state.
- **Health** - a component roster from `/api/health`, each row colored by state
  (**ok / degraded / absent / unknown**) with a one-line detail. Four probe
  buttons exercise hardware on demand: **Mic test**, **Speaker test**,
  **Loopback** (plays a tone and checks the mic hears it), and **Probe SD**
  (re-checks the card and upgrades the storage tier live).

Background sessions end to end: **[Sub-sessions](../guides/sub-sessions.md)**.

---

## Chat

Message the assistant from the browser and see its replies; replies also go to
your Telegram, if connected. History re-syncs from the device's canonical store
and reaches back months, so the assistant can recall something you told it long
ago.

**Attach files** by dropping them onto the conversation or with the **Attach**
button - images, text, Markdown, CSV, logs, JSON, and PDF. The upload shows a
progress bar and then lands as a message in the log, saved to Files under the
`chat` project, so the assistant can work with it.

---

## Memory

What the device knows and the files it has made - stored on its SD card, not in a
cloud. Three groups:

- **Memory** - the **Directive** (your standing instructions to the assistant,
  up to 600 characters; only you can change it) and **Assistant memory** (notes
  the assistant keeps for itself between conversations; viewable and clearable).
- **Long-term memory** - the associative store the assistant searches by meaning:
  **Recall** (search, **Deduplicate**, **Delete Temporary**), the **Scratchpad**
  (the assistant's working notes), **Recall tuning** (memories per turn, relevance
  threshold, storage limit - at the limit, the least valuable memory is dropped),
  and the **Embedding model**, which is verified with a real embedding call on
  save and locks once vectors are stored - changing it erases and re-embeds the
  store, and the UI warns first.
- **Files** - files persist across restarts and are never deleted automatically.
  The caption shows the real card size and free space plus the file quota. The
  assistant saves reports here with `artifact.save`; you can filter by project,
  view, download (the token rides a header, never a link), delete, or upload your
  own.

Internals: **[Orchestrator World](../guides/orchestrator-world.md)** and
**[Storage tiering](../guides/orchestrator-storage.md)**.

---

## Assistant

One page, seven exclusive subtabs - **Models**, **Connectors**, **Tools**,
**Skills**, **Routines**, **Usage**, and **Safety**. Everything the assistant can
reach and run, plus what it costs and how it is governed. Keys are set by you,
never by the model.

### Models

- **Providers & keys** - Cumulo Nimbus, Anthropic, OpenAI, Mistral, Z.ai. Keys
  are write-only (a saved key shows as "set" and is never displayed again); model
  choices unlock after the key verifies.
- **Custom endpoint** - point the assistant at any OpenAI-, Anthropic-, or
  Mistral-compatible server: base URL, wire convention, and model ID.
- **Routing** - the **Primary provider** (or Automatic), the **Fallback order**,
  and a separate **Session fallback order** for spawned sessions.
- **Voice** - the **Dictation** provider, the **Spoken replies** provider, and
  the voice itself.

### Connectors

External tools that run in your AI provider's cloud, on the assistant's own turns
and on the sessions it starts. Each connector is a card: create the credential
once, paste it in, enable it - secrets are write-only. An **Advanced** section
edits the raw JSON directly. A device-dialed **MCP** server that the assistant
adds arrives **pending your approval** and shows **Approve / Deny** on its card;
nothing is dialed until you approve it. Setup details per service:
**[Connectors](../guides/connectors.md)**.

The **Telegram** group also lives here: the bot token (from @BotFather), who can
message this device (new senders appear for one-tap approval; access is enforced
by chat ID), the **Open access** switch, and **Voice replies**.

### Tools

The live on-device tool surface - what the assistant can do right now, each tool
with a status badge. External MCP clients can call the same surface over
`POST /mcp`. A **Web search** section takes a Tavily API key so the assistant can
search the web live.

**Tool use** governs that tool surface: when enabled, the assistant uses its
tools mid-turn and iterates before answering. Caps: **Tool rounds** (1-32) and a
**Time limit** (30-3600 s), plus **Switch providers mid-turn**, **Concurrent
connections**, **Validate provider TLS certificates**, and **Capability
validation**. See the **[Turn contract](../reference/turn-contract.md)**.

### Skills

Saved instruction sets the assistant applies when it starts a matching session,
on the SD card at `/mem/skills/<id>/SKILL.md`. You create, edit, and delete them
here; a skill the assistant drafts arrives **pending your approval** and does
nothing until you approve it (here, or `/skill approve <id>` in Telegram).

### Routines

- **Routines** - tasks that run on a schedule (a morning digest, a reminder,
  nightly upkeep). Create one with a name, a prompt, and a schedule (**On an
  interval**, **Daily**, or **Weekly**). Routines the assistant creates for
  itself wait for your approval, and spending limits pause anything that
  misbehaves. Until the device clock syncs, wall-clock routines wait and the card
  offers **Sync now**.
- **Wake-ups** - a wake-up is a turn the assistant schedules for itself to follow
  up later. The policy is **Allow silently** by default; **Ask me first** holds
  each new wake-up for a single yes/no approval card - never a repeating prompt.

### Usage

Token usage reported by your providers, tracked since the device last restarted.
Token counts are actual billed usage; dollar figures are estimates. A
7/30/60-day **Spend over time** chart, per-provider **Rates**, and a monthly
**Budget** per provider (0 = unlimited; at the cap that provider is refused until
the reset day and the assistant fails over when it can).

### Safety

Download trust and guest screening. Your own messages, the web page, and voice
are always exempt.

- **Downloads** - how much trust the assistant gets to download a file from the
  web: **Off**, **Ask me per link**, **Scan, then keep**, or **Full trust**.
- **Guest moderation** - screens people other than you who reach the bot.
  **Check guest messages before answering** (a flagged or uncheckable message is
  not answered), **Check replies sent to guests** (a flagged reply is held; if the
  check cannot run the reply still goes out), and **Flag suspicious fetched
  content** (marks web content that looks like a hidden instruction as data - it
  marks, never blocks, and runs on the device at no extra cost). The message and
  reply checks each cost one moderation call per screened item.

---

## Device

Display, sound, power, network, updates, and cloud - all in one place, as
collapsible groups:

- **Mode & identity** - the operating mode (**Notifier** or **Orchestrator**;
  switching restarts the device), the **Device name**, the **Timezone**, the
  **Device clock** (set automatically from the internet; a badge shows **synced**
  or **waiting**, with **Sync now**), and the **Device sign-in code** (only needed
  when a QR cannot be scanned; tap to copy).
- **Display** - a 180-degree **Display flip** for upside-down mounts, and **Touch
  calibration** for the touch screen (or the self-calibrating panel's swap/flip
  orientation toggles). Takes effect right away.
- **Battery mode** - **Dark / Balanced / Full**, which sets the light. The
  **Theme** picks the color family, and **Preview** shows any status pattern in
  the ring simulator; **Demo on Device** plays it on the physical ring. Full
  color and motion language: **[LED experience](../guides/led-ux.md)**.
- **Customize battery mode** - every parameter starts at the selected battery
  mode's default; set a value to override it, or **Revert to Defaults**.
- **Sound** - audio checks (**Mic Meter**, **Speaker Tone**, **Loopback Test**)
  and the **Sound effects** engine (**[SFX map](../guides/sfx-map.md)**): a
  per-mode level, a sound theme, a **Volume** slider, and **Play**.
- **Battery** - appears once battery telemetry is present: voltage, estimated
  time left, discharge rate, health, and power source, plus **Calibrate Full
  Charge** (anchors 100% to a fully charged pack, with a visible result).
- **Software update** - installed and latest versions, **Check for Updates**
  (which reports whether an update was found, you are up to date, or the check
  failed), **Install Update**, **Automatic updates**, and **Confirm USB updates**
  (requires an on-device tap before a firmware update over the USB cable). When an
  update needs more charge than the pack has, a battery-gate message names the
  threshold and Install stays disabled. Updates are cryptographically signed and the device
  reverts on its own if a new version fails to start.
- **Connectivity** - the home-network address; the temporary setup hotspot and
  password; the **Device sign-in code** and **Generate New Code**; **Bluetooth**
  status and **Forget Paired Devices**; and **Wi-Fi** (scan, pick a network,
  **Join** - 2.4 GHz only; the one action allowed before signing in).
- **Cloud access** - reach the device from anywhere through CumuloNimbus. Pairing
  shows a dedicated card with the **Cloud link code** large and high-contrast
  beside a QR: sign in at app.cumulo-nimbus.ai, then scan the QR or enter the
  code. **Copy code** copies it. Available in Orchestrator mode.
- **Power** - **Restart…** restarts the device and brings it back on its own in
  about a minute (nothing is erased); use it to apply a setting that says it takes
  effect after a restart. **Power Off…** saves everything and puts the device to
  sleep. Both confirm first.
- **Danger zone** - **Erase Storage…** wipes the SD card (typed confirmation) and
  **Factory Reset…** erases everything (Wi-Fi, API keys, the Telegram list,
  Bluetooth pairings, themes, sound settings, memory, and the device sign-in
  code) and restarts into first-time setup. Both need the exact phrase typed.

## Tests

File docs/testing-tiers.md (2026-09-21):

# Testing tiers

One taxonomy for the whole product (this repo, the cloud repo, notify, solide-drivers).
Every new test states its tier; every tier has one runner.

| Tier | What | This repo | Runs |
|---|---|---|---|
| T0 | Static gates | pre-commit hooks, param-consumer + status-doc + webui-concat gates | every commit |
| T1 | Unit (host, fast) | `pio test -e native` suites without goldens | every commit |
| T2 | Integration (fakes, seams) | native suites exercising module seams (`test_harness_*`, wire codecs) | every commit |
| T3 | Golden / snapshot | `test/golden*`, webui snapshot, QR/nsn vectors | every commit |
| T4 | End-to-end on simulators | host rigs (`tools/harness-lab`) only (no emulated-device leg: see below) | every push |
| T5 | Hardware-in-the-loop | `python3 -m pytest tests/hil -m "hil and not manual" --allow-hardware` (device lock protocol applies) | bench |
| T6 | Live paid (real providers) | evals + HIL "net" layers; each SKIPS cleanly unless its key env var is set (keys via repo-root `.env`) | milestones + gate, budget-capped |

Rules: never mock the thing under test to make a tier pass; hardware claims need hardware
(T5) or an explicit handed-off manual step; T6 results persist to `~/nimbus-evals/`
(JSONL per run with model, scores, token and dollar cost) - never into the repo.

Destructive legs (fresh-device / factory-reset): a few T5 legs FACTORY-RESET the board
(they erase keys, the token, pairing and every owner setting to reach the genuine
out-of-box state). They carry the `destructive` marker, not `hil`, so the standard
`pytest tests/hil -m "hil and not manual" --allow-hardware` run and the release gate
DESELECT them. Run them deliberately and alone with `pytest tests/hil -m destructive
--allow-hardware`; the fixture re-provisions Wi-Fi and clears the adversarial cal/flip on
teardown, but the board is left factory-fresh, so re-onboard it afterward.

## T4 emulated-device tier: evaluated, not adopted

T4 runs end-to-end against host rigs (`tools/harness-lab`) only. We evaluated adding
an emulated-device leg on top of the two options that can run ESP32-S3 firmware
without a board, and rejected both.

A full-system CPU emulator (Espressif's QEMU fork) does not model the peripherals
that define this device: no Wi-Fi, no Bluetooth, no I2S audio, no SPI display, and no
addressable-LED output, and the 8 MB octal PSRAM the board boots with is the one
memory setting a tracked bug reports it failing to recognize. What it can run is the
portable, radio-free logic already covered at T1 through T3.

A cloud parts-simulator (Wokwi) does better on the screen and Wi-Fi path: it can drive
the ILI9341 display, the WS2812 ring, an SD card, and internet access, and it models
8 MB octal PSRAM. But it cannot simulate Bluetooth or I2S, so Notifier pairing and all
microphone and speaker behavior stay dark, touch has no interactive panel model, and
headless use in CI needs a paid per-seat token plus metered minutes.

In both cases the coverage gained overlaps the golden and snapshot tiers, while the
failure classes that actually shipped in the 2026-08-24 incident (pairing, audio,
touch placement, real timing) can only be proven on hardware at T5. Emulation is
therefore not adopted. If a hardware-free display and UI regression lane is wanted
later, the cloud parts-simulator is the candidate to reassess, not the CPU emulator.
Full spike evidence and costs are recorded on the CUM-80 issue.

## Fresh-device (default / absent-NVS) leg

The touch-mirror / touch-180 / uncalibrated-out-of-box family kept re-presenting because every
other automated leg runs on a PROVISIONED unit (calibration solved, NVS good), while the owner
hits the FIRST boot after a new version. The fresh device is therefore a first-class test STATE:

- Host (T1): `test/test_fresh_device` and `test/test_touch_cal` pin the class rules a fresh boot
  resolves (per-TouchKind default flags, the first-run cal gate policy over every kind, the
  flip-compose rule that a stored cal stays valid across a display flip, the no-dead-end
  first-run screen selection). A new board or touch class without a measured default fails at
  compile time (a `static_assert` on `TouchKind::Count`).
- Bench (T5): `tests/hil/test_l33_fresh_device.py` drives the board to the out-of-box state
  through the product factory-reset path plus the test-only `CALGATE clear` (a factory reset
  keeps the touch cal as hardware identity), then on a fresh resistive panel asserts the guided cal
  gate owns the panel (no self-navigation for 30 s), injected taps do not navigate while gated,
  the deliberate long-hold skip hands off to first-run setup, and render reaches the frame
  (`TFTFILL?` GRAM readback). An NVS-adversarial variant persists a hostile `tchCal`/`tftFlip`
  (frozen keys that survive a reflash), reboots, and asserts the device boots healthy, applies
  the stored values, and does not re-arm the gate. The gate is invisible to `RENDER?` by design
  (it paints outside the `g_lastScreen` path), so the `CALGATE` console seam is the oracle for
  gate state; the four-corner SOLVE itself, and whether a tap lands where you touch under a flip,
  stay finger-on-glass steps the runbook hands to the bench.

## Sleep/wake and button-feedback legs

Two owner-facing behaviors that a green build cannot prove: that the device wakes
cleanly cycle after cycle from a software power-off, and that every actionable menu
control gives a sound and ring cue. Both split the same way: assert everything a seam
can reach, hand the finger/ears part to a human.

- Sleep/wake soak (T5): `tests/hil/test_l34_sleep_wake.py` runs N cycles (default 20,
  `NIMBUS_SOAK_N`) of the real product power-off path. Each cycle reads the wake-arming
  plan (`SLEEP?`: whether a tap can wake this board and on which touch controller and
  GPIO, the ext0 level, and the timer), asserts it is present and coherent (a torn or
  incoherent arm report is itself the "won't wake" failure), enters deep sleep with a
  test-only timer wake (`POWEROFF <secs>`, so the leg wakes with no finger), proves a
  fresh boot from the boot stream plus `WAKE?` (reset reason deep-sleep, cause timer),
  checks persisted state is intact (mode, screen model, board, web token, touch-cal
  gate), and records wake latency. The soak runs on the flashable bench board; the
  Freenove FT6336U-INT variant is a loud skip when no Freenove is attached. The real
  finger tap that pulses the touch INT is an owner manual leg (no finger or INT jig on
  the bench).
- Button feedback (T5): `tests/hil/test_l35_button_feedback.py` fires the real
  outcome-to-cue seam over serial (`ACTFB <action> <outcome>`) for a success row
  (Reset) and a failure row (Rescan SD with no card), then reads back the cue that
  fired (`FEEDBACK?`: tone id, ring swell, and screen line) and polls `RENDER?` to
  prove the ring swell ends (no lit arc outlives its window, the CUM-134/CUM-11 rule).
  Whether the tone is audible and the ring is the right color to the eye is an owner
  manual leg.
- Host (T1): the pure parsers and the wake-arming coherence rule are covered with no
  board in `tests/hil/test_l34_sleep_wake_host.py` and
  `tests/hil/test_l35_button_feedback_host.py` (the outcome-to-cue mapping itself is
  host-tested in `test/` under `pio test -e native`).

## The release gate

A cross-cutting battery that must be green before any firmware tag or client flash.
It exists because the 2026-08-24 incident shipped a white screen, a universal tunnel
502, a rotated touch surface, and reconnect flapping in one release. Each of those
classes now has a test that fails on the pre-fix build and passes on the fix.

- Host checks (T0-adjacent, run in CI): `python3 tools/release_gate/run_gate.py --host-only`.
  The driver-pin check refuses a build on a known white-screen driver; the ELF check
  keeps the e-paper footprint out of the TFT image; the OTA-NVS check proves the update
  flow writes only its own bookkeeping keys, never an owner's settings (CUM-237).
  `python3 -m pytest tools/release_gate` tests the gate logic.
- One host verdict across every failure class: `python3 tests/release_gate/run_host_legs.py`
  runs each host leg (the white-screen, touch, boot-loop, and settings-across-OTA unit and
  source-guard legs) and prints a single PASS/FAIL. `tests/release_gate/MANIFEST.md` maps
  every lose-every-customer class to its leg, says whether it runs on the host or the bench,
  and gives the exact board, steps, and pass criteria for each bench leg.
- On-hardware legs (T5): `tests/hil/test_l29_release_gate.py` - loopback serves the local
  page (not a 502), render reaches the glass (with a recorded human glance), touch lands
  where tapped, a wedged loop is caught by the watchdog, a bad OTA image rolls back.
- Cloud legs (in the cloud repo, run by `pnpm e2e`): the connected-device 5xx interstitial,
  the reconnect storm, and the read-only live smoke.

`tools/release_gate/run_gate.py` prints the full battery with exact commands and the block
condition. See `tools/release_gate/README.md` for what each leg catches.

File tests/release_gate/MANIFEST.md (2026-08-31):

# Release-gate MANIFEST - every lose-every-customer failure has a gate

The bar (CUM-174, owner mandate 2026-08-24): every failure class from the field
incident - white screen, universal tunnel 502, touch breakage, crash/boot loop,
reconnect flapping, settings lost across an update - has a test that FAILS on the
pre-fix code and PASSES on the fix, and no firmware tag or client flash ships
until the gate is green.

This file maps each class to its leg(s), says whether the leg runs on the HOST
(always-on, in CI) or the BENCH (needs a real board), and for every bench leg
gives the exact board, steps, and pass criteria. The host legs are aggregated by
`tests/release_gate/run_host_legs.py` (one verdict); the full battery, including
the hardware and cloud checklists, is printed by
`tools/release_gate/run_gate.py`. Cloud legs live in the cumulo repo and are not
duplicated here.

Run the host gate:

```
python3 tests/release_gate/run_host_legs.py     # every host leg, one PASS/FAIL
python3 tools/release_gate/run_gate.py          # + the hw/cloud checklist
```

---

## 1. White screen - pixels never reach the glass (CUM-167, CUM-231)

The 2026-08-24 white screen shipped two ways: a driver pinned to a broken display
init (CUM-167), and a panel-heal watchdog that stopped re-arming a silently-slept
panel (CUM-231). Both are gated.

| Leg | Where | What it pins |
|---|---|---|
| `test/test_panel_health` | HOST | The flip-aware `healthy()` MADCTL compare. Catches the partial MY/MX loss (`got=0xE8`) the v0.7.1 mask waved through, and does not thrash at flip=1 (the v0.7.0 full-byte bug). Regression witnesses for both prior versions are asserted in-file. |
| `test/test_panel_heal` | HOST | The rearm guard (`nimbus::panel::unchangedFrameAction` / `tickHealthAction`, wired into `src/hw/tft_out.cpp`). Past the trust window the panel is re-armed UNCONDITIONALLY; `healthy()` only decides whether to ALSO repaint. This is the exact policy that regressed: an early return when `healthy()` read true left a beacon-slept panel white. |
| `tools/release_gate/check_driver_pin.py` | HOST | Refuses a build pinned to a denylisted white-screen driver version (CUM-167 shipped on v0.6.0; fixed at v0.6.1). |
| `tools/release_gate/check_elf_symbols.py` | HOST (needs `pio run -e esp32s3` first) | Keeps the e-paper driver out of the TFT image and proves the display plumbing linked. |
| `test_l29_release_gate.py::TestRenderToGlass` | **BENCH** | Pixels actually reach the glass. See the bench procedure below. |

### BENCH leg - render reaches the glass (retroactive proof of CUM-167)

- **Board:** solide_s3 (a TFT + ring Nimbus) AND freenove_s3 (a Freenove CYD),
  per family. The RDDPM (0x0A) power-register readback legs are solide-only - the
  Freenove panel has no register readback (MISO), so gate those by board family
  or run them on the TFT board (see the 2026-08-25 note on CUM-174).
- **Steps:**
  1. Flash the release candidate: `pio run -e esp32s3 -t upload` (solide) /
     `pio run -e esp32s3-cyd -t upload` (freenove).
  2. `pytest tests/hil/test_l29_release_gate.py -m hil --allow-hardware` - drives
     `TFTFILL?`/`TFTPWR?`/`TFTBREAK` and asserts the panel reports display-on and
     recovers from a silent reset (RDDPM non-zero on the TFT).
  3. **Mandatory human glance** (`-m manual`): an operator looks at the screen and
     confirms the UI is drawn, not white. Record it in the release checklist.
- **Pass:** RDDPM reads non-zero after a forced `TFTBREAK` reset (panel re-armed,
  solide board); the operator confirms real pixels. On the pre-fix build (driver
  v0.6.0) the glance FAILS (white) - the retroactive proof.
- **NVS-adversarial pass (CUM-228 routing note):** run the render legs twice -
  once with default/no NVS, once with adversarial persisted `tchCal`/`tftFlip`/
  `scrModel` - so a fielded device's state is covered, not just a clean flash.

---

## 2. Touch breakage - taps land in the wrong place (CUM-203, CUM-189)

A stale or wrong-default calibration rotated the touch surface. The per-board
default and the 180 reconciliation are the host-provable core.

| Leg | Where | What it pins |
|---|---|---|
| `test/test_touch_cal::test_board_default_per_kind_orientation` | HOST | `boardDefaultCal(TouchKind)` differs per kind: resistive Solide (XPT2046) is swap-ONLY (the CUM-203 fix, so it stops mirroring one axis out of the box); capacitive Freenove (FT6336U) is swap + invertY (CUM-189, bench-verified). A `(void)kind` shared default can never come back. |
| `test/test_touch_cal` (parse / solve / wizard / `orientTouch`) | HOST | Calibration parse rejects malformed input without mutating; the corner solver derives the axis map; `orientTouch` is the single-source 180 (involutive, applied on top of the cal, never folded in). |

### BENCH leg - a physical tap lands where injected (CUM-203 class)

- **Board:** both families. Run once with default NVS and once with an adversarial
  `tchCal`/`tftFlip` (the stale-calibration interplay).
- **Steps:** `pytest tests/hil/test_l29_release_gate.py -m hil --allow-hardware`
  (`TestTouchCorrectness` - injected tap opens/closes the menu), then the
  `-m manual` physical-tap checklist: tap the four corners, confirm the hit lands
  under the finger. NVS is restored after.
- **Pass:** the injected tap maps to the expected control in both NVS states; the
  operator's physical taps land correctly. The touch-180 only reproduces with a
  real finger under an adversarial flip - hence the bench step.

---

## 3. Crash / boot loop - the device wedges or never boots clean (CUM-174 #4)

| Leg | Where | What it pins |
|---|---|---|
| `test/test_ota_logic::test_rollback_policy` | HOST | `shouldRollback(pending, bootCount)` = the app-level rollback guard: a pending fresh image that fails to go healthy for `kOtaMaxBootAttempts` (3) boots rolls back on the 4th. |
| `test/test_ota_logic::test_boot_healthy` | HOST | `bootHealthy(uptime, wifiEverUp)` - when a fresh image may mark itself valid (120 s crash-free with Wi-Fi up; 600 s on a Wi-Fi-dead site) so a fine image never false-rollbacks. |
| `test/test_fault` | HOST | The capability-fault registry the resilience paths are driven through. |

### BENCH legs - watchdog + boot-loop (device-only; honestly not host-provable)

The watchdog timer, the actual boot-count increment in NVS, and a real reboot
sequence are device behavior. They cannot be proven on the host - only the
*decision* (`shouldRollback`) is pure. These are bench legs:

- **Watchdog starvation:** `pytest tests/hil/test_l29_release_gate.py -m hil
  --allow-hardware` (`TestCrashLoopResilience::test_watchdog_reboots_a_wedged_loop`).
  Drive `HANG` on the serial console; the task watchdog must reboot the device.
  **Pass:** the device resets within the watchdog window and comes back up.
- **Boot-loop detection across N reboots:** `test_boots_without_a_crash_loop` -
  reset the board N times; it must reach a settled screen each time, never a
  reset storm. **Pass:** clean boot every cycle, no reboot loop.
- **OTA bad-image rollback:** `TestOtaRollback::test_bad_image_rolls_back_after_
  failed_boots` - stage a deliberately-bad image (`OTASIM`), let it fail to go
  healthy; the app-level guard flips back to the previous slot. **Pass:** device
  returns on the old slot with `otaLast="rollback vX"`. This is the on-device
  proof of the host `shouldRollback` decision.
- **Relay reconnect storm:** cloud-side; covered in the cumulo e2e
  (`release-gate-reconnect-storm`), NOT duplicated here.

---

## 4. Settings lost across an update (CUM-237)

An owner's provisioned state - Wi-Fi credentials, provider API key, measured touch
calibration, screen model, LED theme, battery config - lives in NVS and MUST
survive a firmware update. The OTA flow may write only its own bookkeeping.

| Leg | Where | What it pins |
|---|---|---|
| `tools/release_gate/check_ota_preserves_nvs.py` | HOST | Source guard over `src/sys/ota_update.cpp`: every `nvs_set_*` / `nvs_erase_key` in the OTA flow targets an `AKEY_OTA_*` bookkeeping key or the `otaSimCrash` drill flag - never a user key. FAILS the build if an update path writes Wi-Fi, a provider key, `tchCal`, `scrModel`, `theme`, etc. Retroactively proven RED by the injected-user-key cases in `tools/release_gate/test_release_gate.py`. |

### BENCH leg - the full survive-an-OTA proof (device-only)

The source guard proves no *code path* writes a user key; the end-to-end proof
that a real update preserves the flash needs a board:

- **Board:** either family, provisioned (Wi-Fi + provider key + a MEASURED touch
  cal + a non-default theme, so there is real user state to lose).
- **Steps:**
  1. Provision the device and record every user NVS key
     (`otaType`-excluded): Wi-Fi, provider key (masked), `tchCal`, `scrModel`,
     `theme`, `sfx*`, battery keys, `devName`.
  2. Run an OTA span end to end (check -> download -> verify -> reboot to the new
     image, `pytest tests/hil/test_ota.py --allow-hardware` or a real `/update`).
  3. Power-cycle the device (pull power, not just a soft restart).
  4. Read NVS back and diff against step 1.
- **Pass:** every user key is byte-identical after the update + power-cycle; only
  the OTA bookkeeping keys (`otaPend`/`otaBoots`/`otaLast`/...) changed. Wi-Fi
  rejoins and the provider still answers without re-entry. On a build that wrote a
  user key during OTA this diff is non-empty - the retroactive failure.

---

## 5. Fresh device - the first boot after a flash (CUM-245, CUM-203, CUM-189, CUM-230, CUM-211)

Every other leg runs on a PROVISIONED unit (cal solved, NVS good, a provider
keyed). The owner hits the FIRST boot after a new version - the exact state that
shipped touch mirrored (CUM-203) and uncalibrated (CUM-189) out of the box. AGENTS.md
section 3 makes that STATE a first-class test target; this class pins it.

| Leg | Where | What it pins |
|---|---|---|
| `test/test_fresh_device::test_every_touchkind_has_a_measured_default` | HOST | The per-kind default-cal table as a CLASS: EVERY `TouchKind` has a measured, valid, non-mirrored default, and no two kinds share one. A new controller class without a default fails - at runtime (`expectedFlagsFor`) and at COMPILE time (a `static_assert` on the `TouchKind::Count` sentinel). Verified RED against the `(void)kind` leak and against a new kind added with no default. |
| `test/test_fresh_device::test_all_board_models_resolve_a_correct_default` | HOST | Reads the driver's own board constants (`kBoardSolideS3`, `kBoardFreenoveS3`), maps each board's `touchKind` to the portable mirror (the same collapse `src/main.cpp` / `src/net/webui.cpp` make), and asserts each ships a correct default - so a mis-declared board `touchKind`, or a new `board_*.h`, is caught here. |
| `test/test_fresh_device::test_default_cal_flags_are_flip_independent` + `..._flip_compose_is_a_bijection_over_the_panel` | HOST | A stored cal stays valid across a display flip: the 180 is `orientTouch`'s job, composed on top, never folded into the cal (CUM-160). Every kind's default flags are flip-independent (never `invertX`), and the flip point-reflects the whole panel with no dead zone. |
| `test/test_fresh_device::test_fresh_config_is_all_presets_no_overrides` + `..._absent_blob_leaves_defaults_untouched` | HOST | First-boot config resolution: a fresh `Config` is EXACTLY the Balanced presets over every param, no override leaking from uninitialized storage; an absent blob leaves defaults untouched (all-or-nothing). |
| `test/test_fresh_device::test_fresh_boot_posture_is_profile_seeded` | HOST | Onboarding posture (CUM-230): the fresh-boot ring level is the one the profile seeds (Balanced -> Calm), never an uninitialized Dark (invisible) or Full (drain). |
| `test/test_fresh_device::test_zero_keys_reads_as_no_provider` | HOST | Provider gate on zero keys (CUM-211): a fresh device with no key on any slot reads as no-provider - the input the engine's honest "set up a provider" reply is built on. The engine-level reply itself is `test/test_harness_turn` (not duplicated). |

### BENCH leg - first boot on real glass (CUM-245 leg 3; owed to the bench)

The host legs prove the fresh-boot DECISIONS are pure and correct. The out-of-box
experience on glass needs a board and is NOT host-provable - it is the bench half,
coordinated with the CUM-174 render/touch legs above (run their default-NVS pass):

- **Board:** both families, flashed CLEAN (erase flash, no NVS) so cal is absent.
- **Steps:**
  1. `pio run -e esp32s3 -t erase` then upload the candidate (freenove: `esp32s3-cyd`).
  2. Boot to first-run; BEFORE any calibration, inject the standard corner taps
     (`test_l29_release_gate.py::TestTouchCorrectness`) and assert they map within
     tolerance on the fresh default cal.
  3. Confirm render reaches the glass (section 1 bench leg) and the onboarding
     wizard can be completed - `store::onboarded()` is false out of the box.
- **NVS-adversarial variant:** boot once with an adversarial persisted `tchCal` /
  `tftFlip` (frozen keys survive a reflash) - the nimbus-4 touch-180-across-firmware
  case. Restore NVS after.
- **Pass:** on the fresh default the injected taps land correct on BOTH families and
  the UI is drawn (not white, not mirrored); the pre-CUM-203 build FAILS the resistive
  tap. Shares the render/tap bench harness with sections 1-2 (default-NVS pass).

---

## 6. Tunnel 502 - device serves 502 for every request (CUM-173) - NOT here

Covered by the cloud repo's lifecycle e2e (the connected-device 5xx interstitial)
and the device-side CloudLoop HIL leg
(`test_l29_release_gate.py::TestTunnelLoopback`). Do NOT add a duplicate host leg
in this suite. The large-page (>256 KB) tunnel leg and the reconnect storm are the
cumulo e2e's (CUM-228 routing note); the CloudLoop bench leg is the device half.

---

## Host vs bench at a glance

| Class | Host leg (always-on) | Bench leg (needs a board) |
|---|---|---|
| White screen | panel_health, panel_heal, driver-pin, elf-symbols | render-to-glass + human glance (RenderToGlass) |
| Touch | touch_cal (per-kind default, solve, orientTouch) | injected + physical tap (TouchCorrectness) |
| Crash/boot loop | ota_logic (shouldRollback, bootHealthy), fault | watchdog reboot, N-reboot, OTA rollback (CrashLoop/OtaRollback) |
| Settings-across-OTA | check_ota_preserves_nvs | provision -> OTA -> power-cycle -> read-NVS diff |
| Fresh device / default-NVS | fresh_device (touch class, flip compose, fresh config/posture, zero-key gate) | clean-flash first-boot tap + render + onboarding, NVS-adversarial |
| Tunnel 502 | (cloud repo) | CloudLoop (TunnelLoopback) |

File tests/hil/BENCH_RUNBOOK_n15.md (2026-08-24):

# N15 bench runbook - CUM-160 triage: tunnel gateway-timeout reset + 180 touch

Triage of two field symptoms, done host-side on current `main` (base `3e8db03`), with
the exact code sites and a bench procedure to confirm each on hardware. Whoever runs
this holds the device lock per the fleet-lane protocol (create
`/tmp/nimbus-devices/<port>.lock`, 45 min max, release after). Nimbus-4
(`usbmodem2101`) is the personal board - restore its NVS from
`~/nimbus-bench/nimbus4-backup/` when done. Freenove (`usbmodem101`) is the scratch board.

The touch injection console path (`NIMBUS_TEST` `injectTap`) deliberately bypasses the
real read + flip mirror, so the 180 symptom cannot be reproduced through the HIL console -
it needs a physical tap. Both checks below are therefore manual.

---

## Symptom A - tunnel gateway-timeout then device RESET then lag

### Architecture
The "tunnel" is the cumulo-nimbus cloud relay (`src/net/relay_client.cpp`): one resident
outbound WSS the device dials, answering browser requests by replaying them into its own
local `AsyncWebServer` over loopback. The relay runs on its own FreeRTOS task pinned to
core 0 (`relay_client.cpp` `begin()` -> `xTaskCreatePinnedToCore(relayTask, ..., 0)`), and
that task is NOT subscribed to the task watchdog. The only watchdog-subscribed task is the
main Arduino loop on core 1 (`src/main.cpp`: TWDT 8000 ms, `trigger_panic=true`;
`esp_task_wdt_add(nullptr)` at end of setup; fed once per `loop()`).

### The REAL 502 root cause (CUM-173, third handback - instrument-proven)
The tunnel path is `handleReq` -> `replayReq` -> `doLoopback`. Two field theories were
DISPROVEN on the bench and replaced by the real mechanism:

1. **"127.0.0.1 loopback is refused"** - FALSE on current main. Instrumented CLOUDLOOP on
   the Freenove: `relay: loopback via=127.0.0.1 conn=2ms status=200` for `/`, `/api/state`,
   `/logo.svg`, `/api/signin/code`. `CONFIG_LWIP_NETIF_LOOPBACK=y` is set for esp32s3, so
   127.0.0.1 connects in ~2 ms and serves every route. The latent bug there was the
   FALLBACK: `WiFi.localIP()` can be `0.0.0.0` just after a (re)join, and the old code dialed
   it -> guaranteed 502. Hardened: 127.0.0.1 primary, STA fallback only when usable
   (`nimbus::cloud::loopbackFallbackUsable`, host-tested), short connect timeout (no 4 s stall).
2. **THE actual 502: response OVERFLOW.** The config page (`GET /`) is ~278 KB but the old
   loopback body cap `kMaxRespBody` was 256 KB (`262144`). The parser flagged `overflow()`
   and `handleReq` turned every tunneled `GET /` into a 5xx - the field white-screen + bad
   gateway. It serves fine to LAN clients (no cap). CLOUDLOOP hid this because
   `loopbackSelfTest` returns `rp.status()` and ignores overflow; `handleReq` does not.
   The exact evidence: `CLOUDLOOP / -> bytes=262144` (the body truncated at the cap).
   FIX: `kMaxRespBody` raised to `nimbus::cloud::kLoopbackMaxRespBody` = 320 KB (PSRAM-backed;
   base64(320 KB) = ~437 KB, under the 512 KB res-frame max). A host regression guard
   (`test/test_loopback_capacity`) asserts the assembled page (webui snapshot) + 16 KB
   headroom fits the cap, so the NEXT page growth fails the battery, not the field. The
   overflow backstop now returns an EXPLICIT 500-with-reason (distinct log tag) instead of a
   bare 502, so the cloud maps it to the "Reaching your Nimbus" interstitial.

### CUM-160 slot-hold: corrected in this handback
The earlier CUM-160 fix bounded `httpsPostJson`'s whole slot-hold to 5500 ms and ABORTED
past it. That was a regression: a real relay/Cloudflare TLS connect legitimately takes
many seconds (12 s+ is latency, not a hang), and the abort stopped the device reconnecting.
Corrected: NO connect-abort (the relay task is not watchdog-subscribed, so its blocking
connect cannot trip the 8 s WDT - proven by the old unbounded build reconnecting fine); the
READ runs as watchdog-fed, bounded steps via `nimbus::cloud::driveStagedWait` (no single
step over `relayStepMs` = 2 s, feeds between steps), host-tested with a synthetic 10 s op
(`test/test_relay_timing`: completes, never aborts, feeds occur). Hold-instrumentation kept:
```
relay: httpsPost held=<ms> connect=<ms> status=<n>
```

The old OOM levers stay mitigated (`kMaxInboundFrame = 16*1024`, heap loopback read buffer,
PSRAM res body with a graceful "res drop (no mem)" fallback).

**Loopback instrumentation (device evidence, CUM-174 gate asserts on it):** every
`doLoopback` logs `relay: loopback via=<target> conn=<ms> status=<n> bytes=<n>`, or
`relay: loopback REFUSED via=<target> conn=<ms> (tunnel 502)` on a hard refusal.

### Bench procedure (manual)
1. Lock the port; USB-reset-clear if the console is wedged (CUM-141 pyusb recipe in
   `/tmp/nimbus-devices/MAP.md`).
2. Flash the `test` (or `test-cyd`) firmware; provision Wi-Fi (no cloud pairing needed).
3. **CLOUDLOOP self-test (no cloud dependency, drives the exact tunnel path):**
   - `CLOUDLOOP /api/state` -> expect `-> 200` and a log line
     `relay: loopback via=127.0.0.1 conn=~2ms status=200 bytes=<n>`.
   - `CLOUDLOOP /` -> expect `-> 200` and `bytes=<full page size ~278KB>`, NOT `bytes=327680`
     (the cap). Before the cap fix this showed `bytes=262144` (truncated/overflow).
   Verified on the Freenove 2026-08-24: all four routes 200, `via=127.0.0.1 conn=2ms`,
   `CLOUDLOOP / bytes=277882` after the cap fix.
4. Field confirm (owner, Nimbus-4 on merged main + v0.6.1): open `d.cumulo-nimbus.ai`, sign
   in, navigate. Expect the full page (no white screen / bad gateway) and, over a
   pair/re-mint, `relay: httpsPost held=<ms> connect=<ms> status=200` with the relay coming
   ONLINE and staying online across reboots (the CUM-160 reconnect regression is gone).
5. Release the lock.
Pass = CLOUDLOOP `/` returns 200 with the full page bytes (no overflow), and the owner's
tunnel login loads and the relay reconnects.

---

## Symptom B - touch input reversed 180 degrees

### Where the flip lives
Two transforms. The driver calibration produces landscape pixels
(`solide/touch.h` `Calibration`: `swapXY=true, invertY=true` for the mounted panel). The
180 mirror is in `src/hw/touch_input.cpp:84-87`:

```cpp
if (down && solide::display_tft::flipped()) {
  x = solide::display_tft::kW - 1 - x;   // 319 - x
  y = solide::display_tft::kH - 1 - y;   // 239 - y
}
```

The mirror runs only when `display_tft::flipped()` is true, and must track the MADCTL
display flip set from `agent::store::tftFlip()` (boot: `main.cpp`; live: the settings menu,
the web toggle, and the `TFTFLIP` console command). A 180 reversal means the touch mirror
and the display flip DISAGREE: taps land at the diagonally opposite point.

### Fix (IMPLEMENTED - lane N15, second handback)
Root cause is TWO sources of truth for the 180: the touch calibration's invert flags AND
the runtime flip mirror could each try to handle it, so they could double-apply (taps 180
out) or disagree. The fix makes the DISPLAY FLIP the single source of truth: the 180 is now
applied by one pure, host-tested function `nimbus::touch::orientTouch(point, displayFlipped,
w, h)` (`lib/core/.../touch_cal.cpp`, tests in `test/test_touch_cal`), which `touch_input.cpp`
calls instead of the inline mirror. The calibration maps ONLY the mount (canonical,
un-flipped landscape); the flip is applied there exactly once, so it can never double-apply.

**Reachable calibration path (already user-facing, confirmed):** the web Device tab exposes
a **Display flip** toggle (flips display + touch together now, applies immediately), a
**Touch calibration** field (minX,maxX,minY,maxY,flags), and a **Touch orientation** control
for the capacitive panel ("toggle these until a tap lands where you touch"); the console has
`TFTFLIP` and `TOUCHCAL`. So a 180 is correctable on-device with no reflash.

### Bench check (physical taps, confirms the field report is closed)
The polarity of a given mount is still a physical fact; the console inject path bypasses the
orient branch, so verify with real taps:

### Bench procedure (manual, physical taps)
1. Lock the port; flash `test` firmware.
2. Read state: `STATUS` (note the display flip / `tftFlip`), and confirm `scr=tft`.
3. Render a screen with a known-position target (e.g. a corner button). Physically tap it.
   Confirm the tap registers on the target, not the diagonally opposite corner.
4. Toggle the flip (`TFTFLIP` console command or the web toggle) and repeat the tap test in
   both states. The correct configuration is the one where the tapped target responds in
   the orientation the display is actually mounted.
5. If reversed, apply the matching fix above, reflash, and re-verify all four corners.
6. Restore Nimbus-4's original `tftFlip` / NVS when done (personal board).
Pass = taps land on the on-screen target in the mounted orientation, all four corners.

---

## Symptom C - relay refuses to dial: "Not enough memory right now" (CUM-167)

### Root cause (instrument-proven, NOT a lane-N15 code regression)
On final main Nimbus-4's /api/state reports cloud state=disabled, err="Not enough memory
right now": the relay heap-floor guard (heapFloorOk) refused to dial. Measured: internal
free ~26 KB but the largest free internal block dipped below the old 8000 floor.

The cause is solide-drivers **v0.6.1** (CUM-167 white-screen fix): full frames from PSRAM
are staged through a persistent **internal DMA bounce buffer**
(`display_tft.cpp` `kBlitBandRows=8` -> `8*320*2 = 5120 B`, `MALLOC_CAP_INTERNAL|MALLOC_CAP_DMA`).
That 5 KB block, allocated at display init, sits mid-heap and SPLITS the largest free
internal block below 8000 - so the relay's contiguous-block floor failed even with ample
total free. It is NOT the N15 third-handback code: static RAM is byte-identical (83068)
across b69b2bb, my HEAD, and 32703ed, and the relay's big buffers (TLS/body/frame) are
PSRAM-backed. The buffer is essential (a PSRAM DMA burst resets the panel) and cannot move
to PSRAM; it can only be shrunk in the driver (owner: CUM-167).

### Fix (lane N15 scope)
The relay's real internal-contiguous demand is only the 4 KB WS handshake head - the floor's
8000 was headroom assuming "largest ~13 KB is normal", which the bounce buffer broke. Lowered
`kRelayHeapFloorLargest` 8000 -> 5000 (host-tested in `test/test_relay_heap`; still clears the
4 KB handshake need with margin, free floor unchanged so genuine starvation still refuses).
The guard now RE-CHECKS every 10 s (was 60 s) and logs the live numbers
`relay: heap floor - free=<n> largest=<n> ...` so it comes online promptly on recovery. The
relay's own transient loopback buffer moved to prefer PSRAM.

### Bench numbers (before/after intLargest)
- BEFORE (floor 8000): /api/state cloud.state=disabled, err="Not enough memory right now".
- AFTER (floor 5000): with the same intFree/intLargest, relayCanDial returns true; /api/state
  cloud dials (Idle/Connecting/Online). Read `mem.intFree` / `mem.intLargest` from /api/state
  before and after. Field-verify on Nimbus-4 (owner) that the cloud link comes up.

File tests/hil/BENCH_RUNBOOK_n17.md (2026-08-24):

# N17 bench runbook - CUM-167: solide_s3 white screen (PSRAM full-frame blit)

Root-cause and bench confirmation for the Nimbus-4 (`solide_s3`) white screen on
merged `main` (`3e8db03`): the firmware logs `[tft] colour touch panel up` while
the glass stays white. Whoever runs this holds the device lock per the bench
lock protocol (create `/tmp/nimbus-devices/usbmodem2101.lock`, 45 min max,
release after). Nimbus-4 (`usbmodem2101`) is the personal board - its NVS backup lives in
`~/nimbus-bench/nimbus4-backup/`. All steps below are app-partition uploads (no
flash erase), so `scrModel=tft` and the touch calibration survive.

---

## Root cause (host-side)

The panel comes up, the render task is alive, and the framebuffer holds correct
pixels - but the full-frame blit resets the panel. `display_tft::blit()` (the
async path behind `pushFrame`, `src/hw/tft_out.cpp:152`) DMAed the whole ~150 KB
RGB565 framebuffer straight from PSRAM. On the ESP32-S3 a burst that long out of
PSRAM shares the external-memory bus and was measured to reset the ILI9341
(MADCTL 0x28 -> 0x00): the panel reverts to its power-on default and shows white,
while every register readback and the render task still look healthy. This is the
exact fault the repo's own bring-up sketch documents (`src/bringup/tftmin.cpp`:
"pushFrame() straight from PSRAM ... breaks the panel"; the internal-bounce path
is safe).

Why it surfaced in the N6/N7/N14 window and not before: the fault is latent and
layout-sensitive. Driver `v0.6.0` (N14) compile-gated the e-paper stack, freeing
~14.5 KB of internal SRAM (measured: esp32s3 internal RAM 83,068 B gate-off vs
97,596 B with `-DSOLIDE_HAS_EPAPER=1`); N7 moved TLS staging buffers into PSRAM.
Either shifts the boot allocation / PSRAM-bus profile enough to tip the latent
PSRAM-DMA reset into a deterministic white screen.

The incident's prime suspect (the e-paper compile-gate stubbing shared panel
plumbing the TFT calls) is NOT the cause: `src/device/display.cpp` is 100 %
e-paper (GxEPD2), the colour TFT driver `display_tft.cpp` is separate and
ungated, and the firmware TFT path never calls the gated `solide::display`
namespace. ELF nm on the TFT build carries 0 GxEPD2 symbols and 16
`solide::display_tft` symbols - the gate works as designed. The other documented
suspect (register-probing racing the blit) is already off by default on `main`
(`tft_out.cpp` `g_probeEnabled=false`), so it is excluded.

## Fix (driver v0.6.1)

`display_tft::blit()` now detects a PSRAM source (`esp_ptr_external_ram`) and
stages it band-by-band through a small internal DMA-capable bounce (8 rows,
5,120 B, allocated once in `begin()`), so the DMA always sources internal SRAM;
an internal-memory frame still writes directly. This is the technique
`pushFrameChunked` already used, applied to the default `pushFrame` path so every
consumer is safe with no firmware code change - the firmware only re-pins the
driver to `v0.6.1`. The e-paper gate is untouched (still 0 GxEPD2 on a TFT
build), so the 14.5 KB win is preserved; the 5 KB bounce is runtime PSRAM-neutral
internal heap.

Regression guard: `tools/check_tft_elf_no_eink.py <elf>` fails if a colour-TFT
ELF links any GxEPD2 symbol (the e-ink stack crept back / the SRAM win regressed)
or is missing the `solide::display_tft` path. Run it after `pio run -e esp32s3`.

## Bench procedure (owner glance is the oracle)

The register readback stayed correct through every blank screen in the original
investigation, so the eye - not `STATUS` - is the oracle for "is it drawing".

1. Lock the port; USB-reset-clear if the console is wedged (CUM-141 pyusb recipe
   in `/tmp/nimbus-devices/MAP.md`).
2. REPRODUCE: flash the `test` firmware built against driver `v0.6.0`. Expect
   `[tft] colour touch panel up` on serial and a WHITE glass (owner glance).
3. FIX: flash the `test` firmware built against driver `v0.6.1`. Expect the boot
   UI to DRAW and stay drawn (owner glance), serial `RENDER?` echoing the screen.
4. CONTROL (the incident's own test): flash `main` built with
   `-DSOLIDE_HAS_EPAPER=1` (driver `v0.6.0`). Expect it to DRAW - confirming the
   14.5 KB layout lever rather than any shared-plumbing dependency.
5. FINAL: flash the production `esp32s3` `main` at the `v0.6.1` pin. Owner
   confirms draw AND touch (this build also carries N15's `orientTouch` fix, so
   the display flip is authoritative for touch).
6. Do NOT restore the rescue build once `v0.6.1` confirms - the final state is
   `main` + `v0.6.1`. Release the lock.

Pass = the panel draws and stays drawn on the `v0.6.1` build (owner glance), the
`v0.6.0` build reproduces white, and the ELF guard is green.
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

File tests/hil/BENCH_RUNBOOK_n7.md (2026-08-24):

# N7 bench runbook - live before/after intLargest/heapMin + 24 h soak

Turnkey steps for the CUM-24 before/after and the CUM-36 soak. Read-only measurement
uses `tests/hil/sram_sampler.py`. Whoever runs this holds the device lock per the
fleet-lane protocol (create `/tmp/nimbus-devices/<port>.lock`, 45 min max per hold,
release after). Nimbus-4 (`usbmodem2101`) is the personal board - restore its NVS from
`~/nimbus-bench/nimbus4-backup/` when done. Freenove (`usbmodem101`) is the scratch board.
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

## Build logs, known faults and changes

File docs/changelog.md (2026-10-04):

# Changelog

Release notes for recent Nimbus firmware releases, newest first. Every release
ships as a signed image on the public
[nimbus-fw-releases](https://github.com/ristllin/nimbus-fw-releases)
repository; a device on Orchestrator mode sees it on its daily check and
installs on your say-so ([how updates work](ota.md)).

## v4.5.8 - A factory reset you can trust, voice that starts now, memory on Mistral

- **Factory reset now erases everything, and says so first.** Settings > Reset opens a
  choice: "Reset settings" returns every setting to its default and keeps your Wi-Fi,
  keys, and memories; "Factory reset" erases all of it - Wi-Fi and passwords, provider
  keys, paired computers, settings, memories, routines, and logs, including the SD
  card - with the full list on screen before you confirm. The erase refuses honestly
  if the card holding your memories is not readable ("Reseat the SD card and try
  again"), and the confirm button needs a second deliberate tap, so a bounced touch
  can never wipe the device.
- **Voice and web messages start right away.** A hold-to-talk or web message used to
  wait for the next Telegram check, up to half a minute. It now starts at once, and
  Telegram messages still arrive as before.
- **Two devices no longer end up with the same name.** A second Nimbus set up next to
  a running one now calls itself Nimbus-2 - its setup network and web address stay
  distinct.
- **Mistral works for memory.** Choosing Mistral as the memory (embeddings) provider
  now works; before, every save failed. If the memory store and the model disagree on
  size, the device says exactly that instead of pretending nothing matched.
- **Rate limits name their window everywhere.** A Virtual Nimbus and background
  helpers now say which limit was hit and when it resets, the same way the device
  already did.
- **Behind the scenes:** the release pipeline's remaining actions are pinned, and a
  weekly full build of every firmware variant guards against silent rot.

## v4.5.7 - Voice that responds instantly, setup that signs you in, connectors that really work

- **Letting go of the mic responds instantly.** Releasing the hold-to-talk button now
  changes the screen and ring at once, shows a thinking state while your request is
  processed, and ends with the reply. Off Wi-Fi, the answer comes back in about two
  seconds and says the real reason: "No network. Check Wi-Fi and try again." Every
  failure now names itself (provider error, nothing heard, busy) instead of a
  catch-all "didn't catch that".
- **Publish Setup Network now walks you through it.** The button confirms what happens
  next, and the device screen switches to the setup network: the network name and
  password, a join QR, numbered steps, and a sign-in code that the sign-in page
  actually accepts. Tap the code to enlarge it. The code field on the phone no longer
  capitalizes what you type, and every card fits the screen.
- **Wi-Fi status is back on the screen.** The header shows connected, searching, or
  not set up, plus an amber AP marker while the setup network is up.
- **Mistral connectors work, verified against your Mistral account.** The device now
  asks Mistral which connectors your account really offers and uses exactly those;
  Google Calendar, Notion, and Slack pulls were proven end to end. Connector turns no
  longer stall for a minute, and a rate-limit reply tells you the actual limit you
  hit and when it resets.
- **A Virtual Nimbus now matches the device.** It runs sub-agents, uses the same
  connectors, and handles Telegram the device way: nobody is trusted by default, and
  you approve each chat from its own web page with the roles you already know.
- **The sign-in page keeps everything behind it hidden** on the phone until you sign
  in, and the chat no longer piles up old tool-call disclosures without their
  conversation.

## v4.5.6 - Stuck key checks clear themselves, clearer Mistral connector setup

- **A key check stuck on "Verification deferred" now recovers, and Verify works for
  every provider.** The Cumulo Nimbus and Z.ai keys were missing from the manual
  re-check, so their Verify button did nothing, and a check deferred during a
  low-memory moment could be abandoned and never retried, leaving the key stuck
  "deferred" for good. The check now retries itself once memory frees, and Verify
  re-runs it on demand for every provider.
- **Mistral connectors tell you where to finish setup.** Turning on a Mistral
  connector (Google Calendar, Notion, Slack, or a hosted tool) now says plainly that
  it is authorized in your Mistral account (La Plateforme > Connectors), not on the
  device: add your Mistral key here, then turn the connector on in Mistral. Before,
  an enabled-but-unauthorized connector looked on but did nothing, and the hint
  pointed at the wrong place.

## v4.5.5 - More free memory on the Freenove, clearer key and memory checks, a Safety activity view

- **More free working memory on the Freenove board.** The audio parts now release
  their buffers when sound is idle instead of holding them for the whole session, so
  the board keeps far more of its scarce internal memory free at rest, well above the
  low-memory floor. Sound still plays and records the same; the parts come back the
  moment they are needed.
- **A deferred key check now explains itself and retries on its own.** When you
  paste a provider key and the device is low on working memory, it saves the key and
  shows "Verification deferred" instead of a failed check. The badge and a line under
  the key field now say what happened and what happens next: the key is saved, and it
  is checked again automatically when memory frees up, or you can tap Verify to retry.
  Hovering the badge shows the measured numbers (the largest free block and the amount
  the check needs). The device re-runs the check by itself on a short, backing-off
  schedule while memory is tight, and the Memory health row notes when a check has
  been waiting a while.
- **A Virtual Nimbus now accepts your own provider keys from its web app.** Setting
  an OpenAI, Anthropic, Mistral, or Z.ai key on the Providers & keys page of a hosted
  instance now takes effect on that instance, the same as on a device: the key shows
  "Key set", the model picker unlocks, turns run on that provider, and the key
  survives a restart. Before, only the Cumulo Nimbus key took; the other providers
  looked saved but nothing applied. Z.ai is now offered as a direct provider on a
  hosted instance too. An unrecognized key field is refused with a clear error rather
  than being quietly accepted.
- **A Virtual Nimbus reports its real version, like a device.** A hosted instance now
  shows the same engine version a physical device shows (for example v4.5.x) instead
  of a container tag, and each release builds and publishes the hosted image so an
  instance is never left several versions behind.
- **Checking for updates over a remote connection no longer shows a gateway
  error when the check actually worked.** The device accepts an update check right
  away and runs the download-and-verify work in the background, so a check started
  through the remote link returns promptly instead of the connection timing out at
  the edge while the device quietly finished. The result still appears on the
  Software update panel once it settles: up to date, a new version, or an honest
  failure with the reason.
- **Cumulo Nimbus is now a selectable voice provider.** The web Voice settings and
  the device Sound menu both offer Cumulo Nimbus for dictation and spoken replies,
  alongside Mistral and OpenAI. Choosing it routes voice through the metered router,
  so a one-key device can speak without a separate OpenAI or Mistral key. An explicit
  choice of Cumulo Nimbus is honored even when another provider key is present, and
  the voice picker shows an honest hint when no Cumulo key is set.
- **Memory tools say why when embeddings are unavailable, and search still
  answers.** When the assistant cannot turn text into a vector, it now names the
  real cause (no embeddings key, a rejected key, a busy connection, an
  unreachable provider, a timeout, an HTTP error, or a provider that is out of
  credit or rate limited) instead of one fixed "provider offline?" message, and
  never shows a key. Memory search and archive search keep working through the
  outage by falling back to a labeled keyword match over your stored memories, so
  recall no longer reads as empty. Saving a memory during an outage is refused
  with the real reason rather than stored without a vector.
- **A new Safety activity surface shows what the scanner blocked or flagged.** Under
  Assistant, Safety, Activity you see a list of the most recent blocked or suspected
  items, newest first. From it you can approve an item to allow that sender, that exact
  content, or that pattern from then on, dismiss it, or report it to Cumulo if you
  subscribe. Approving is always scoped and bound to the gate it came from, never a
  blanket off switch, and the Allowed items list below lets you revoke any approval.
- **The LAN MCP endpoint no longer buffers a request before checking the device
  token.** An unauthenticated `POST /mcp` is refused with nothing kept in memory, and
  an authenticated request larger than 64 KB is refused rather than silently cut
  short. Normal MCP clients see no change.
- **Power off and wake, and button feedback, are now checked repeatedly on real
  hardware.** A bench soak drives many power-off then wake cycles and confirms the
  device comes back each time with its settings intact, and a bench check confirms
  every actionable menu control gives its sound and ring cue and then the ring goes
  dark. No change to how the device behaves; these close gaps in what was proven.

## v4.5.4 - Touch works again on classic boards, honest display check, cloud-sync headroom

- **Touch responds again on the classic (TFT + ring) board.** v4.5.0 introduced a
  background display-health poll that shares the panel bus with the resistive
  touch controller on the classic board and could pin touch. That poll is now
  off on those boards; the display and touch reads the board shipped with in
  v4.4.6 are back as they were.
- **The display check tells the truth on the classic board.** Because that
  board cannot read its display controller without disturbing touch, the
  installer, the boot log, the health panel and the device status now say the
  display "cannot self-check on this board, look at the screen" instead of
  reporting it healthy. A display that fails to start is still reported as
  such. The Freenove board keeps its full self-check.
- **Cloud sync no longer runs out of memory.** The relay staging buffers behind
  "Not enough memory right now" live in the large PSRAM, and the memory floor
  the cloud dial checks is sized for that; a serve of the full device page now
  leaves the scarce internal memory almost untouched. A release check keeps
  those buffers from creeping back.
- **An unseeded Freenove is offered no update rather than the wrong size.** The
  three Freenove panel sizes cannot be told apart by the hardware, so a board
  with no seeded type no longer guesses 2.8" and is skipped by typed updates
  until it is set up with the installer.
- Installer and bench tooling: `tools/board_info.py` reads a board over USB
  without resetting it; the installer picks the provisioning image by board and
  cable; the on-device test suite measures the classic board honestly instead
  of skipping.

## v4.4.9 to v4.5.3 - stability under low memory, honest routines and storage

Cut without notes; the user-visible changes across those four releases:

- Turns wait honestly under low memory instead of failing over to a different
  provider, and routines that could not run say why.
- A message the device already handled is never replayed after a restart, and
  rapid messages are batched into one turn.
- A durable error log on the card or flash, readable from the device page.
- A loud "SD not detected, memories are on the card" banner when the card
  drops, instead of an empty Memory panel.
- A first-class memory restore over HTTP from a device backup.
- The Cloud access card can mint a Cumulo key for the device.

## v4.4.8 - GPT-6 Astra, current model lineups, router-driven Cumulo catalog

- **The Cumulo Nimbus model list now comes from the router itself.** The device
  reads the router's routable catalog (models with a confirmed price, across
  every upstream), so the Cumulo dropdown offers exactly what your Cumulo key
  can route, newest flagships first, including Anthropic and Mistral models
  through the one key. Size classes ride along from the router.
- **Current models across every provider.** The built-in model lists now lead
  with each provider's September 2026 lineup: OpenAI `gpt-6-astra` plus the
  `gpt-5.6` Sol / Terra / Luna tiers, Anthropic `claude-opus-5` /
  `claude-sonnet-5` / `claude-haiku-4-5`, Z.ai `glm-5.3` / `glm-5.2` /
  `glm-5.3-flash`. Defaults move up with them (OpenAI `gpt-5.6`, Anthropic
  `claude-sonnet-5`, Z.ai `glm-5.3`, Cumulo Nimbus `gpt-5.6`), and the 5.6
  tier names now carry their size, so fallback rules by size match them. The
  Cumulo Nimbus model list also lists newest models first instead of oldest.
- **GPT-6 Astra can be selected.** OpenAI's `gpt-6-astra` (released 2026-09-03) is
  offered as the Orchestrator model and as the sub-session model under Assistant >
  Models, with its full context window and reasoning support. The OpenAI model list
  now keeps the newest GPT generation first instead of only the GPT-5 family, so
  the next generation shows up on its own. Cumulo Nimbus prices it from day one.
- **Cumulo Nimbus provider slot in the device Models UI.** Assistant > Models >
  Providers & keys now lists **Cumulo Nimbus** first, the recommended one-key path:
  paste your device key, and Verify checks it against the router (not a third-party
  API) with the base wiring already set, so there is no URL to type. **Z.ai** is
  listed too. Pasting a Cumulo key into a direct provider now says to use the Cumulo
  Nimbus slot instead of a bare "key rejected."
- Removed the deprecated e-ink display and rotary-knob code paths. Both shipping
  configurations are color touch panels (the Solide S3 with its LED ring, and the
  Freenove CYD all-in-one). E-ink devices stay on their final firmware (typed OTA
  delivers them no further updates).
- **Multi-resolution touch UI.** The color renderer is now parameterized by panel
  resolution, so one code path draws every supported size. The 2.8" panel is
  unchanged (its goldens are byte-identical). Two larger Freenove sizes are added
  as their own firmware images and typed updates: **3.5" (480×320, `freenove-35`)**
  and **4.0" (480×480, `freenove-40`)**. Both are **host-verified only** - proven
  by per-size golden framebuffers and a linking firmware image, not yet run on a
  physical panel (the panel driver gains the larger geometry when hardware is in
  hand). See [Supported panels](hardware/all-in-one-cyd.md#supported-panels).

## v4.1.0 - Orchestrator self-knowledge, honest capacity, real file delivery

Everything the assistant tells you about itself is now generated from live,
validated device state - never hardcoded prose - and it can finally produce and
deliver real files. Origin: the owner's two-sub-agent task ("collect AI news →
PDF → Telegram; find financial news → email draft") failed end-to-end on
v4.0.0; every feature below traces to a root cause of that failure or to the
owner's follow-up review of the composed prompt.

### 1. Dynamic, validated self-knowledge (the composed prompt)
- The provider/connector catalog is **generated from the live device state**:
  each provider is marked *available, VERIFIED* / *key present, not yet
  verified* / *REJECTED* from the real verify cache - never a checkbox printed
  as fact. Custom MCP servers get an honest "capabilities not catalogued" line.
- A new **[SUB-AGENT CAPABILITIES]** block states, per keyed provider, what a
  spawned agent actually gets - and the universal rule the failed task broke:
  **sub-agents gather (and may run their provider's connectors server-side);
  the head does every owner-delivery step.** It also answers "can a sub-agent
  code?" (anthropic sandbox: writes AND runs code; openai/mistral: Python via
  code_interpreter; nothing pushes to a repository).
- **Every prompt surface reads live state**: the role line carries the device's
  own name (a renamed device no longer introduces itself twice under two
  names); the identity block names *who this turn's message is from* and their
  role (multi-tenant honesty - not everyone is "your owner"); the hardware
  manifest reflects the fitted display, the live SD tier, the real battery
  hardware, and the actual LED count.
- **Per-connector credential state**: the catalog marks a failed OAuth sign-in
  ("sign-in FAILED - tell the owner") and a missing credential ("NO credential
  - not usable"), fed from the one credential choke point. Enabled is a
  checkbox; these markers are evidence.
- **Capability validation is a user setting** (Assistant → Models → Tool
  use): off / passive (default) / active. Passive marks a provider verified
  when a real turn succeeds; active adds a periodic free re-verify
  (`GET /v1/models`, ~$0) so a revoked key is caught.

### 2. On-board documentation (`docs.list` / `docs.search` / `docs.read`)
The device carries a generated pack of its own documentation (14 curated docs,
169 sections, ~195 KB of flash rodata) and the prompt tells the model to check
it before claiming what it can or cannot do. The pack is regenerated from
`docs/` at build time and ships inside `firmware.bin` - **OTA updates the
device's self-knowledge automatically and it can never version-skew.**

### 3. Complete live self-state (`device.status`)
One tool call now answers every "what is your current state" question: firmware
+ update engine + slot + auto-update, time + timezone + clock sync, heap/PSRAM,
SD (including live *lost* state) + internal flash, battery, ring posture +
battery mode (user and effective), memory counts **vs live caps** (vectors,
episodic, scratchpad), file-store usage + free, **sub-agent capacity**
(running/queued vs limits), real billed token usage, and every settable knob's
current value. `tenant.list` shows usage beside quota; `files.list` leads with
totals; the scratchpad view shows fill vs caps.

### 4. Scratchpad as a first-class response field
The model's persistent working memory (`active` / `short` / `mid` / `long`) is
now a top-level `orch_turn` response field - a free write with no tool round -
that survives across turns and restarts. The prompt renders it every turn with
the write instruction beside the data. It was an admin-only tool nobody
triggered; now multi-step plans persist. (Admin-gated: the global scratchpad
renders into every prompt, so non-admin writes are refused.)

### 5. Honest throughput - `[SPAWN CAPACITY]` (no concurrency, by design)
"6 spawn slots free" implied a hard ceiling; the model under-spawned deep runs.
The prompt now states the true model: N startable this turn, running
**sequentially** (single task, one TLS connection at a time), draining over
successive waves - *not a hard total limit*. A deeper pending queue (12,
decoupled from the concurrency window) accepts a full wave up front. A >60 s
Mistral sub now reports an honest timeout instead of the false "couldn't
start". ⛔ Sub-agent concurrency was investigated and permanently rejected -
hardware-proven unstable (see the development guide).

### 6. Provider file delivery - the PDF path
A sub-agent that generates a file in its provider sandbox now has that file
**captured to the SD artifact store and delivered over Telegram**:
- **OpenAI** code_interpreter (container files) - **including PDF** (verified
  live end-to-end at the API level).
- **Mistral** code_interpreter (files API) - images/text (their sandbox
  currently errors on PDF/CSV output; the capture is type-agnostic and needs
  no change when they fix it).
Downloads stream to SD under the TLS arbiter (the OTA pattern), are
Content-Length-verified (a truncated download is refused, never registered as
saved), and respect the file store's ownership boundary.

### 7. Ring: the orchestrator arc persists while children run
The head's blue arc used to collapse the instant a fan-out turn returned. A
host-tested reconciler on the always-alive main loop keeps it lit while
sub-agents run, bridges the synchronous-dispatch window, clears exactly once
when the last child finishes, and latches off if the system wedges (a dead
task can't pulse "working" forever).

### 8. Clock & timezone, dream honesty, memory dashboard (merged sibling work)
Owner-set timezone with device clock + sync badge on the web UI; routines adopt
a timezone edit budget-neutrally; the nightly dream skips its paid reflection
turn on quiet nights and respects an honest fact quota; the memory dashboard
gained lifecycle columns (created / expires-in / last-used), browse pagination,
Delete All (typed confirm), file content search, SD-wipe danger controls, and
photo-aware `files.send`.

### Main architectural decisions

1. **⛔ No on-device sub-agent concurrency - permanent.** Investigated at the
   owner's prompt; hardware evidence (the tlsSlots=2 A/B failure, recurring
   poll-task stack overflows, a watchdog reset from contending work, ~22.5 KB
   largest contiguous internal SRAM) closed it. Serial single-task/single-TLS
   is the design, not a limitation to fix. Throughput improves only via honest
   wording, queue depth, and remote-side parallelism (openai/anthropic).
2. **Self-knowledge is generated, never asserted.** Anything the prompt claims
   must come from a live seam (verify cache, HAL health, storage tier, tenant
   table, driver constants) - the same "advertised == callable" principle
   extended to "described == measured". Golden tests pin every prompt surface.
3. **Docs ride the firmware image.** Embedded generated pack (rodata) over
   LittleFS images or SD sync: zero RAM cost, works with no card, and OTA can
   never ship firmware whose self-description lags its behavior.
4. **Delivery is the head's job; provider sandboxes are hands.** Sub-agents
   return text plus captured file references; only the head touches the owner
   (Telegram/files/memory). This is the decomposition contract the prompt now
   teaches, and the file-capture path enforces it mechanically.
5. **Honesty gates at the data path.** Truncated downloads refuse to register;
   cross-tenant overwrites refuse at begin AND at the destructive rename; a
   transient verify failure cannot demote a proven credential; every "not
   captured / not usable / sign-in failed" state is surfaced instead of
   silently dropped.

### Verification
Host: 1164 native test cases green (grew from 1117 at v4.0.0). Device:
`esp32s3` + `test` builds green (~60% app slot after the docs pack). The full
diff was reviewed for regressions before tagging. Website docs regenerated and
building clean.

## v4.0.0 - Skills authoring · Deep research · Canonical wire · Deep history

### New
- **Skills authoring**: the assistant can draft its own reusable skills
  (`skill.save`/`skill.delete`). Every assistant-written skill arrives pending
  your approval (web Assistant → Skills, or `/skill approve <id>` in
  Telegram) and does nothing until approved. Built-in skills can't be
  overwritten; you can delete any skill, the assistant only its own.
- **Deep research** (built-in skill): multi-wave sub-agent fan-out into a
  per-run project on the SD card - each sub-agent's findings auto-save as a
  document, a final large-model writer gets the strongest docs attached, and
  the report is delivered to your Telegram.
- **Sub-agent attachments & projects**: a spawned sub-agent can carry up to 4
  on-device documents (spliced in by the firmware) and a project tag that
  auto-saves its full result - multi-stage runs plan from what actually landed.
- **Deep history**: conversation search now reaches months back - past what is
  loaded at startup - with honest paging ("searched back to a date; older
  history exists"). "I don't remember" now means it actually isn't there.
- **Mid-turn provider failover**: a turn that loses its provider partway
  through continues on the next verified provider, carrying its work
  (Settings toggle "Switch providers mid-turn", default on).

### Changed
- All three providers' tool loops now replay a single device-owned transcript
  (stateless wire) - eliminates the OpenAI chain-poisoning failure class.
- Prompt honesty: delivery claims ("sent", "spoken") require a tool result;
  memory saves are phrased as intent until confirmed; the spawn-slot budget is
  visible to the model so it says when it can't start everything.
- `/api/chat` `pending` now means a turn is actually running.

### Fixed
- Episodic search silently returned nothing from any day-file over 128 KB
  (tail-read offsets were indexed wrong) - a busy month of history was
  invisible while the RAM cache quietly served recent rows.
- Cold-history paging: byte cursors no longer re-emit recent rows or strand
  deep history on the shipped configuration.
- Attach reads now enforce the same per-person file boundary as `files.read`.
- Skill approval holds its lock across the read-modify-write, so a concurrent
  assistant save can't slip an unreviewed body into an approved skill.

## Older releases

Release history before v4.0.0 lives on the
[releases page](https://github.com/ristllin/nimbus-fw-releases/releases).

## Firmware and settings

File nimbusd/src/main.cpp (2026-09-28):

// nimbusd - the hosted Nimbus daemon (Virtual Nimbus, Phase 0).
//
// Composes the real Nimbus orchestrator (the same TurnEngine + memory + tools +
// provider adapters the desk device runs) as a long-lived Linux process:
//   * durable POSIX stores under a data dir  -> memory survives restart
//   * an engine thread + request mailbox     -> single-context invariant held
//   * a Telegram channel                     -> the persona, same as the device
//   * a 127.0.0.1 control surface            -> the seam the relay sidecar forwards to
//
// Secrets arrive from the environment (a mounted Secret in the container) and an
// optional non-secret config file; nothing secret is ever logged (masked to 4
// chars). BYOK is the Phase 0 key mode: the operator supplies the provider keys.
//
// Usage:
//   nimbusd                 run the daemon (Telegram + control surface)
//   nimbusd --getme         validate TELEGRAM_BOT_TOKEN via getMe and exit
//   nimbusd --once "text"   run ONE turn against the composed engine, print the
//                           reply, and exit (a keyed smoke check)
//   nimbusd --help
//
// Env / config keys: NIMBUSD_DATA_DIR (/data), NIMBUSD_CONFIG (<data>/config.env),
//   NIMBUSD_CONTROL_ADDR (127.0.0.1), NIMBUSD_CONTROL_PORT (8787),
//   NIMBUSD_WEB_TOKEN, NIMBUSD_DEVICE_NAME, NIMBUSD_PRIORITY,
//   NIMBUSD_SUB_PRIORITY, NIMBUSD_ORCH_HOST, NIMBUSD_TOOL_LOOP (1),
//   TELEGRAM_BOT_TOKEN, OPENAI_API_KEY / ANTHROPIC_API_KEY / MISTRAL_API_KEY,
//   TAVILY_API_KEY, TZ. NIMBUSD_TG_CHAT_ID is LEGACY: an optional one-time seed of
//   the Telegram allowlist, which the owner manages in the web app (CUM-459).
#include <atomic>
#include <csignal>
#include <cstdio>
#include <cstring>
#include <ctime>
#include <string>
#include <thread>

#include "daemon_config.h"
#include "daemon_http.h"
#include "engine_thread.h"
#include "http_control.h"
#include "reply_buffer.h"
#include "rig.h"
#include "telegram.h"
#include "tg_inbound.h"

namespace {

std::atomic<bool> g_stop{false};
void onSignal(int) { g_stop.store(true); }

void logLine(const std::string& s) { std::fprintf(stderr, "[nimbusd] %s\n", s.c_str()); }

nimbusd::NimbusdRig::Options buildOptions(const nimbusd::Config& cfg) {
  nimbusd::NimbusdRig::Options opt;
  opt.dataDir = cfg.get("NIMBUSD_DATA_DIR", "/data");
  opt.devName = cfg.get("NIMBUSD_DEVICE_NAME", "Nimbus");
  opt.priority = cfg.get("NIMBUSD_PRIORITY", "mistral,openai,anthropic");
  // Device parity: the sub-agent ladder ("" -> same as NIMBUSD_PRIORITY) and an
  // explicit head pin ("" -> the first keyed provider in NIMBUSD_PRIORITY).
  opt.subPriority = cfg.get("NIMBUSD_SUB_PRIORITY");
  opt.orchHost = cfg.get("NIMBUSD_ORCH_HOST");
  // Device parity (store::orchToolLoop, default on): 0 runs single-shot head turns,
  // which is also the only head path a Mistral key without chat-completions access
  // can use (the tool loop runs on /v1/chat/completions, single-shot on
  // /v1/conversations, where Studio connectors attach to the head turn itself).
  opt.toolLoop = cfg.getInt("NIMBUSD_TOOL_LOOP", 1) != 0;
  opt.role = "admin";  // a hosted instance is single-owner by construction
  // Embeddings default to Mistral (cheapest); disabled if no key is present so
  // the daemon still runs (recall simply returns nothing).
  opt.embedHost = cfg.get("NIMBUSD_EMBED_HOST", "mistral");
  opt.embeddings = !cfg.providerKey(opt.embedHost).empty();
  opt.embedModel = cfg.get("NIMBUSD_EMBED_MODEL", "mistral-embed");
  opt.embedDims = cfg.getInt("NIMBUSD_EMBED_DIMS", 1024);
  opt.maxVectors = cfg.getInt("NIMBUSD_MAX_VECTORS", 5000);
  return opt;
}

// Validate TELEGRAM_BOT_TOKEN via getMe. Returns 0 on success.
int cmdGetMe(nimbusd::Config& cfg) {
  const std::string token = cfg.get("TELEGRAM_BOT_TOKEN");
  if (token.empty()) { logLine("no TELEGRAM_BOT_TOKEN set"); return 2; }
  nimbusd::DaemonHttpTransport http;
  nimbusd::TelegramChannel ch(token, &http, "/tmp/nimbusd-getme-offset");
  std::string user, err;
  if (!ch.getMe(user, err)) {
    logLine("getMe FAILED for token " + nimbusd::Config::mask(token) + ": " + err);
    return 1;
  }
  logLine("getMe OK: bot @" + user + " (token " + nimbusd::Config::mask(token) + ")");
  return 0;
}

// Wire the engine's reply delivery: record every reply in the ring that backs
// the web chat page, and forward it to Telegram when a bot sender is configured.
// `sender` is a pointer-to-pointer so the daemon can fill it in after the bot is
// validated, without re-installing the hook.
void installReplyDelivery(nimbusd::NimbusdRig& rig, nimbusd::ReplyBuffer& replies,
                          nimbusd::EngineThread& eng,
                          std::atomic<nimbusd::TelegramChannel*>* sender) {
  // Runs on the engine thread. `sender` is atomic because the main thread fills
  // it in (below) after the bot is validated, concurrently with the first turns.
  rig.setDeliver([&replies, &eng, sender](const std::string& chat, const std::string& text) {
    // Tag the channel (so web matches only its own) AND the web turn this reply
    // answers (currentWebTurn, 0 for Telegram/non-web) so the web chat surface
    // pairs each turn to its own reply by id, not ring position (CUM-293).
    replies.push("assistant", text, chat, eng.currentWebTurn());
    nimbusd::TelegramChannel* s = sender->load(std::memory_order_acquire);
    if (s) { std::string e; s->sendMessage(chat, text, e); }
  });
}

// Run one turn and print the reply (a keyed smoke check).
int cmdOnce(nimbusd::Config& cfg, const std::string& text) {
  nimbusd::NimbusdRig rig(cfg, buildOptions(cfg));
  rig.refreshMistralWorkspace();   // same startup probe the daemon runs
  auto t = rig.say("owner", text);
  std::printf("%s\n", t.reply.empty() ? "(no reply)" : t.reply.c_str());
  return t.reply.empty() ? 1 : 0;
}

// Boot log: the data layout plus each provider's key presence (masked). The
// Cumulo router key (CUM-286, the flagship one-key path) is reported like any
// other provider so a keyed instance's boot log tells the honest story.
void logStartupConfig(const nimbusd::Config& cfg, const nimbusd::NimbusdRig::Options& opt) {
  logLine("starting nimbusd: data=" + opt.dataDir + " name=" + opt.devName +
          " priority=" + opt.priority +
          " subPriority=" + (opt.subPriority.empty() ? "(same)" : opt.subPriority) +
          " orchHost=" + (opt.orchHost.empty() ? "(first keyed)" : opt.orchHost) +
          " toolLoop=" + (opt.toolLoop ? "on" : "off"));
  for (const char* h : {"openai", "anthropic", "mistral"})
    logLine(std::string("provider ") + h + ": " +
            (cfg.providerKey(h).empty() ? "no key" : nimbusd::Config::mask(cfg.providerKey(h))));
  const std::string ck = cfg.get(nimbusd::kCumuloEnvKey);
  logLine(std::string("provider cumulo (router): ") +
          (ck.empty() ? "no key" : nimbusd::Config::mask(ck)));
  logLine(std::string("embeddings: ") +
          (opt.embeddings ? ("on (" + opt.embedHost + ")") : "off (no key)"));
}

int runDaemon(nimbusd::Config& cfg) {
  auto opt = buildOptions(cfg);
  logStartupConfig(cfg, opt);

  nimbusd::NimbusdRig rig(cfg, opt);
  nimbusd::EngineThread eng(&rig);
  eng.start();
  // The Mistral workspace answer is RAM state: probe it at startup so an enabled
  // Studio connector (gcal/notion/slack) is usable after a restart without anyone
  // pressing verify (a hosted page has no verify button). A no-op without a Mistral
  // key or an enabled Studio connector; runs on the engine thread before any turn.
  if (rig.claimProbe()) eng.postWork([&rig] { rig.refreshMistralWorkspace(); });

  // The reply ring that backs the web chat page (GET /api/replies). Every reply
  // the engine produces is recorded here and, when a bot is configured, also
  // forwarded to Telegram. The delivery hook is set once, before any turn runs,
  // so no reply is lost; `sender` is filled in below if a bot token is present.
  nimbusd::ReplyBuffer replies(/*cap=*/50);
  std::atomic<nimbusd::TelegramChannel*> sender{nullptr};
  installReplyDelivery(rig, replies, eng, &sender);

  // Control surface (loopback), token-gated.
  const std::string webToken = cfg.get("NIMBUSD_WEB_TOKEN");
  nimbusd::HttpControl http(&eng, cfg.get("NIMBUSD_CONTROL_ADDR", "127.0.0.1"),
                           cfg.getInt("NIMBUSD_CONTROL_PORT", 8787), webToken,
                           &replies, &rig);
  const int port = http.start();
  if (port < 0) { logLine("FAILED to bind the control surface"); eng.stop(); return 1; }
  logLine("control surface on " + cfg.get("NIMBUSD_CONTROL_ADDR", "127.0.0.1") + ":" +
          std::to_string(port) + (webToken.empty() ? " (UNGATED - set NIMBUSD_WEB_TOKEN)" : " (token-gated)"));

  // Telegram: separate transports for the long-poll and for sends so a held
  // long-poll never blocks a reply.
  const std::string tgToken = cfg.get("TELEGRAM_BOT_TOKEN");
  std::unique_ptr<nimbusd::DaemonHttpTransport> pollHttp, sendHttp;
  std::unique_ptr<nimbusd::TelegramChannel> tgPoll, tgSend;
  std::thread pollThread;

  if (!tgToken.empty()) {
    pollHttp.reset(new nimbusd::DaemonHttpTransport());
    sendHttp.reset(new nimbusd::DaemonHttpTransport());
    tgPoll.reset(new nimbusd::TelegramChannel(tgToken, pollHttp.get(), opt.dataDir + "/tg_offset"));
    tgSend.reset(new nimbusd::TelegramChannel(tgToken, sendHttp.get(), opt.dataDir + "/tg_send_unused"));
    // Device parity (telegram.cpp poll start): the allowlist fails CLOSED, so say
    // loudly when nobody is approved yet.
    if (rig.telegramAccess().allowEmpty())
      logLine("telegram: allowlist EMPTY - every chat is refused until the owner approves "
              "one in the web app (Assistant, Connectors, Telegram)");
    std::string user, err;
    if (tgPoll->getMe(user, err)) logLine("telegram: bot @" + user + " validated");
    else logLine("telegram: getMe failed (" + err + ") - poll loop will still retry");

    // Route replies to this bot too (the delivery hook above forwards to it).
    sender.store(tgSend.get(), std::memory_order_release);

    pollThread = std::thread([&] {
      logLine("telegram long-poll started");
      // Every update goes through the device trust model (CUM-459): an approved chat
      // becomes a turn; anyone else is queued for the owner's approval and told so.
      // The refusal rides the POLL transport, which this thread owns.
      nimbusd::TgInboundIo io;
      io.turn = [&eng](const std::string& chat, const std::string& text) { eng.postMessage(chat, text); };
      io.send = [&tgPoll](const std::string& chat, const std::string& text) {
        std::string e;
        if (!tgPoll->sendMessage(chat, text, e)) logLine("telegram: refusal to " + chat + " not sent: " + e);
      };
      while (!g_stop.load()) {
        std::vector<nimbus::tg::Update> ups;
        std::string err;
        if (!tgPoll->poll(25, ups, err)) {
          if (!g_stop.load()) { logLine("telegram poll error: " + err); std::this_thread::sleep_for(std::chrono::seconds(3)); }
          continue;
        }
        const auto st = nimbusd::routeTelegramUpdates(ups, rig.telegramAccess(), io, std::time(nullptr));
        if (st.refused)
          logLine("telegram: refused " + std::to_string(st.refused) +
                  " update(s) from unapproved chats (waiting for the owner's approval)");
      }
    });
  } else {
    logLine("telegram: no TELEGRAM_BOT_TOKEN - running control-surface only");
  }

  std::signal(SIGINT, onSignal);
  std::signal(SIGTERM, onSignal);
  logLine("nimbusd ready");

  while (!g_stop.load()) std::this_thread::sleep_for(std::chrono::milliseconds(200));

  logLine("shutting down (flushing memory)");
  if (pollThread.joinable()) pollThread.join();
  http.stop();
  eng.stop();          // joins the engine thread
  rig.flush();         // final durable flush (dtor also flushes)
  logLine("stopped cleanly");
  return 0;
}

}  // namespace

int main(int argc, char** argv) {
  nimbusd::Config cfg;
  // Load the config file (env still wins per-key). Default path lives under the
  // data dir so a mounted config travels with the volume.
  const char* dataEnv = std::getenv("NIMBUSD_DATA_DIR");
  const std::string dataDir = dataEnv && *dataEnv ? dataEnv : "/data";
  const char* cfgEnv = std::getenv("NIMBUSD_CONFIG");
  cfg.loadFile(cfgEnv && *cfgEnv ? cfgEnv : (dataDir + "/config.env"));

  std::string cmd, arg;
  for (int i = 1; i < argc; i++) {
    std::string a = argv[i];
    if (a == "--help" || a == "-h") {
      std::puts("nimbusd - the hosted Nimbus daemon\n"
                "  nimbusd                 run the daemon\n"
                "  nimbusd --getme         validate TELEGRAM_BOT_TOKEN and exit\n"
                "  nimbusd --once \"text\"   run one turn, print the reply, exit\n");
      return 0;
    }
    if (a == "--getme") cmd = "getme";
    else if (a == "--once") { cmd = "once"; if (i + 1 < argc) arg = argv[++i]; }
  }

  if (cmd == "getme") return cmdGetMe(cfg);
  if (cmd == "once") return cmdOnce(cfg, arg);
  return runDaemon(cfg);
}

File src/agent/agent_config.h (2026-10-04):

#pragma once
#include "nimbus/cloud/relay_heap.h"  // CUM-404 v2: reuse the relay-proven per-connection
                                      // largest-block floor (kRelayHeapFloorLargest) for the
                                      // chat hot path - same handshake, CYD-safe (pure lib/core)
// agent_config - device-side constants for the Orchestrator subsystem, ported
// from Nuage-Solide include/config.h (the Head-Orchestrator / heavy-fabric block).
//
// The PORTABLE ceilings (memory caps, journal capacity, MAX_ACTIVE_INFLIGHT,
// spawn field sizes) are the source of truth in lib/core (nimbus/orch/caps.h);
// this header holds only the DEVICE-side numbers the portable core has no opinion
// on: provider REST endpoints, model choice lists, heap floors, poll cadence, and
// the NVS key names. The heap floors + poll cadence are the no-PSRAM survival
// values; keep as-is for P5 and relax behind a flag after on-hardware heap-watch
// (plan §3.7).
//
// VERIFY(2026-09): model lists + defaults refreshed against the providers'
// September 2026 catalogs (OpenAI gpt-6-astra + the gpt-5.6 Sol/Terra/Luna
// tiers, Anthropic Claude 5, Z.ai GLM-5.3). These are the COLD-START fallback
// only: the live /v1/models harvest replaces them on the first verify.
// Endpoints below are copied from Nuage-Solide
// verified live 2026-06-25. Re-verify at implementation: OpenAI has no "-latest"
// flagship alias (needs a periodic bump), Anthropic managed-agents beta header +
// endpoints, model overview pages.

// ---- Provider model choice lists (comma-separated) --------------------------
#define MISTRAL_MODEL_CHOICES "mistral-large-latest,mistral-medium-latest,mistral-small-latest"
#define OPENAI_MODEL_CHOICES  "gpt-6-astra,gpt-5.6,gpt-5.6-terra,gpt-5.6-luna,o4-mini-deep-research"
#define ANT_MODEL_CHOICES     "claude-opus-5,claude-sonnet-5,claude-haiku-4-5"
// Router providers (Cumulo Nimbus, Z.ai) run the assistant as first-class heads.
// These are the fallback choice lists + default head model when the live /models
// harvest has not landed yet; the harvested list wins when present. Cumulo speaks
// the OpenAI-compatible router (default upstream openai), so its defaults are the
// proven router models.
#define CUMULO_MODEL_CHOICES  "gpt-5.6,gpt-5.6-terra,gpt-5.6-luna"
#define CUMULO_MODEL          "gpt-5.6"
#define ZAI_MODEL_CHOICES     "glm-5.3,glm-5.2,glm-5.3-flash"
#define ZAI_MODEL             "glm-5.3"

// ---- Anthropic REST endpoints ----------------------------------------------
#define ANTHROPIC_HOST  "api.anthropic.com"
#define ANTHROPIC_PORT  443
#define ANTHROPIC_VER   "2023-06-01"
// Default Anthropic model (orchestrator + sub-session fallback).
#define ANT_MODEL       "claude-sonnet-5"

// ---- OpenAI REST endpoints -------------------------------------------------
#define OPENAI_HOST  "api.openai.com"
#define OPENAI_PORT  443
// No "-latest" flagship alias exists for OpenAI, so this needs a periodic bump.
#define OPENAI_MODEL "gpt-5.6"

// ---- Mistral REST endpoints (host ported 2026-07 - Conversations API) -------
#define MISTRAL_HOST "api.mistral.ai"

// Z.ai (GLM) - OpenAI-compatible, but the base path is /api/paas/v4 (NOT /v1). The
// token answers at one of two hosts; the device probes both and pins the winner.
#define ZAI_HOST_PRIMARY  "api.z.ai"
#define ZAI_HOST_FALLBACK "open.bigmodel.cn"
#define ZAI_BASE_PATH     "/api/paas/v4"

// Cumulo Nimbus router - one key, upstream selectable per role. OpenAI-compatible
// wire under /router/<upstream>/v1/...; verify + the model harvest hit the
// router's own GET /router/models (the routable catalog: "<upstream>/<model>"
// ids with size_class + billed-rate metadata), so the Cumulo dropdown tracks
// what the router can actually route.
#define CUMULO_HOST_DEFAULT "app.cumulo-nimbus.ai"
#define MISTRAL_PORT 443
// Default Mistral model (orchestrator + sub-session fallback); the "-latest"
// alias tracks the flagship without a periodic bump.
#define MISTRAL_MODEL "mistral-large-latest"
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

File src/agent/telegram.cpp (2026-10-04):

// Hand-rolled Telegram Bot API client for Nimbus. Ported from Nuage-Solide
// src/telegram_client.cpp (Head Orchestrator v2). Single FreeRTOS task (tg_poll,
// core 0, 16 KB stack) interleaves long-poll GET and outbound POST sendMessage so
// only one TLS session is open at any moment. No UniversalTelegramBot; inbound is
// hand-scanned (no ArduinoJson) so the mbedTLS handshake keeps its stack.
//
// Dropped from the Nuage original (Nimbus doesn't have these modules): the
// heaptrace tracer, provider_verify gate, and the netheal self-heal ladder. What
// remains is the full poll/send/voice machinery + a simple consecutive-fail
// backoff. The RST-close (net_util tlsClose) and the persistent poll socket are
// kept - they survive the S3/PSRAM relaxation (plan §3.7).
//
// LIVE-GATED: needs a bot token + allowlist + STA WiFi. VOICE is BENCH-BROKEN +
// key-gated - the STT sink (setSttSink) is unset here so voice notes are answered
// "please send text"; the download/getFile machinery is ported compile-clean.
#include "telegram.h"
#include "../sys/config_nvs.h"   // sys::deviceName - self-identifying 409 alert
#include "../sys/net_util.h"
#include "agent_config.h"
#include "store.h"
#include "../sys/agent_log.h"
#include <esp_task_wdt.h>       // quiesce() feeds the main-task WDT while it waits
#include "memory_subsystem.h"   // captureMediaFile - durable voice-note sidecar
#include "adapters/image_vision.h"   // a photo enters the conversation as words
#include "files_subsystem.h"        // per-sender storage limit, checked pre-download
#include "orchestrator.h"           // roleOfChat / tenantQuotaOf - who is sending
#include "nimbus/mem_cap.h"         // utf8CapLen - never sever a character

#include "nimbus/telegram_offset.h"   // nimbus::core::nextTelegramOffset (host-tested)
#include "nimbus/tg_updates.h"        // nimbus::tg::parseUpdates (host-tested filtered parse)
#include "nimbus/orch/msg_batch.h"    // CUM-398 rapid-message batcher + drainPages (host-tested)
#include "nimbus/net/telegram_auth.h" // nimbus::net::TelegramAuthFailDetector (host-tested)
#include "nimbus/net/tg_poll_sched.h" // CUM-462 idle waits yield to local turns (host-tested)
#include "adapters/http_multipart.h"  // media send (sendDocument/Photo/Voice)

#include <WiFi.h>
#include <WiFiClientSecure.h>
#include <Esp.h>
#include <LittleFS.h>
#include <freertos/FreeRTOS.h>
#include <freertos/queue.h>
#include <esp_heap_caps.h>   // MALLOC_CAP_SPIRAM - queue storage on PSRAM (docs/memory-model.md)
#include "nimbus/tg_html.h"   // v4.1.1: markdown -> Telegram HTML (plain fallback below)

#define TG_HOST "api.telegram.org"
static const int TG_PORT = 443;

namespace agent {
namespace telegram {

namespace {

struct PendingReply {
  char    chatId[32];
  char    text[4097];   // ONE Telegram message: 4096 chars max + NUL. Long turn
                        // replies / sub-agent results are split into numbered (k/N)
                        // parts by send() BEFORE they reach this buffer - never truncated.
  uint8_t tries;        // resend attempts so far (transient TLS failures)
};

struct InboundMsg {
  char chatId[32];
  char from[32];   // honest origin for the unified chat view (was hardcoded "web"
                   // in the drain - a voice/serial inject showed as web-sent)
  char text[4097]; // one full Telegram message (4096 + NUL) - lifts the old 1023
                   // cap on injected (web/serial/voice) messages. The queue slots
                   // live in PSRAM (xQueueCreateWithCaps), so this costs no internal
                   // heap - only the drain's stack local (tg_poll, 16 KB).
  uint32_t queuedAt;   // millis() at injectMessage: the drain logs how long the
                       // message waited for tg_poll (the CUM-462 bench seam)
};

// A voice note seen during a poll, downloaded + transcribed AFTER the getUpdates
// TLS closes (only one TLS session at a time on the single arena).
struct PendingVoice {
  char fileId[128];
  char chatId[32];
  char from[64];
  bool set;
};
static PendingVoice g_voice = {};

// An inbound photo or document seen during a poll. Same deferral as a voice
// note: the download needs the TLS arena, which getUpdates is holding, so the
// work happens after the poll socket closes. One slot per cycle; a second
// attachment in the same batch is left un-acked and re-served next poll rather
// than dropped.
struct PendingAttach {
  char fileId[128];
  char chatId[32];
  char from[64];
  char fileName[64];
  char mime[48];
  char caption[257];
  uint32_t size;
  bool photo;      // false = document
  bool set;
};
static PendingAttach g_attach = {};

// A media file to SEND (device -> owner), drained on the poll task after the poll
// socket closes so only one TLS session is ever resident. One slot: the next
// send overwrites a still-pending one (media sends are rare + owner-facing).
struct PendingMedia {
  char chatId[32];
  char kind[12];     // "document" | "photo" | "voice"
  char path[96];     // source file (LittleFS, or SD /mem/... when sd=true - E1)
  char caption[256];
  bool sd;           // stream from memory::dataFs() (SD) instead of LittleFS
  bool set;
};
static PendingMedia g_media = {};
// sendMedia() may be called from another task/core (console TTSTG/TGSEND on the
// main loop) while the poll task drains g_media - publish/consume the slot under a
// spinlock so the drain never sees a half-written struct (torn 'set').
static portMUX_TYPE g_mediaMux = portMUX_INITIALIZER_UNLOCKED;
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

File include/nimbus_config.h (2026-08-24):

#pragma once
// Nimbus device configuration - single source of truth for timings, thresholds
// and defaults. Hardware pin choices live in solide-drivers' board header
// (solide/boards/board_solide_s3.h); this file holds Nimbus policy only.

// ---- Interaction defaults (profile presets may override; see profile.cpp) --
// How long after the last detent a busy panel may hold the cursor glow as the
// "panel syncing" shimmer. Beyond this window a busy panel is doing unrelated
// work (ambient coalesce flush, attention screen) and must not resurrect the
// glow. The value is a legacy of the slow-panel era (a dwell plus two full
// refreshes); the ring cursor still honors it, so it is kept byte-stable.
#define NIMBUS_CURSOR_SYNC_HOLD_MS 4728

// ---- LED ring ---------------------------------------------------------------
#define NIMBUS_RING_LEDS             45
#define NIMBUS_ATTN_LED_INDEX         0   // Passive posture: the one attention LED
#define NIMBUS_ATTN_HUE_AUTO         -1   // sentinel: derive hue from top-priority state
#define NIMBUS_ATTN_PERIOD_MS      2400   // breathe period for the attention LED
// How long a POST /api/preview holds the ring on the requested profile's look
// before auto-reverting to the live composed state (src/main.cpp startPreview()).
#define NIMBUS_PREVIEW_MS          4000

// ---- Battery policy (hardware TBD - consumed by lib/core/power) -------------
#define NIMBUS_BATT_T1_PCT           20   // force Battery Saver + warn
#define NIMBUS_BATT_T2_PCT            8   // flush journals + clean deep sleep
#define NIMBUS_BATT_HYST_PCT          5   // exit thresholds at T + HYST
#define NIMBUS_VBUS_DEBOUNCE_MS    1500   // stable VBUS before auto-Desk switch

// Battery hardware pins - PLACEHOLDERS until a fuel gauge + VBUS sense are added
// to the board (solide-drivers v0.1.0 has neither). Reserve a spare GPIO for
// VBUS and the I2C bus for a MAX17048-class gauge (plan §1). Define
// NIMBUS_HAS_FUEL_GAUGE to compile + use src/hw/power_fuelgauge; without it the
// firmware runs on NullMonitor (desk-powered, battery UI hidden).
#define NIMBUS_FUELGAUGE_SDA          8   // I2C SDA (verify against final board)
#define NIMBUS_FUELGAUGE_SCL          9   // I2C SCL (verify against final board)
#define NIMBUS_VBUS_SENSE_PIN         4   // VBUS divider -> ADC/GPIO (reserved)

// ADC battery voltage sampling - the resistor-divider alternative to the I2C fuel
// gauge (no extra chip; coarser SoC). Define NIMBUS_HAS_BATTERY_ADC to compile + use
// src/hw/power_battery_adc. Wiring (board hardware.md): tap BAT+ BEFORE the DC-DC,
// e.g. a 2S pack (6.0-8.4 V) via 220k(top)/100k(bot) into GPIO4. ⚠ Must be an ADC1
// pin (GPIO1-10) - WiFi owns ADC2. Free ADC1 spares: 3, 4, 5, 6, 9.
#define NIMBUS_BATT_SENSE_PIN         4   // ADC1 GPIO on the divider node
#define NIMBUS_BATT_DIVIDER_X100    320   // (Rtop+Rbot)/Rbot * 100 - 220k+100k = ÷3.2
#define NIMBUS_BATT_CELLS             2   // series cells (2 = 2S 18650 pack, 1 = LiPo)
#define NIMBUS_BATT_NOMINAL_MAH    3500   // per-cell nominal (LiitoKala INR18650-35E,
                                          // externally measured) - absolute mAh anchor:
                                          // capacityMah = health% * this (battery-measurement)
#define NIMBUS_BATT_VBUS_PIN         -1   // digital USB-present pin, or -1 to infer from V

// ---- WiFi / captive portal + web config (src/net) ---------------------------
// The AP hosts the config UI + a captive DNS; STA (once creds are saved) gives
// the config page reachability on the LAN via mDNS. The config page exposes no
// secrets, but a WPA2 AP still matches the fleet style and needs a >=8-char
// password (softAP silently opens if it's shorter).
#define NIMBUS_AP_SSID       "Nimbus-setup"
// FALLBACK ONLY: the setup AP normally uses the per-device passphrase generated
// on first boot + stored in NVS (agent::store::setupApPass, shown on the setup
// screen). This constant is used only if that store is unusable - it must never
// again be the fleet-wide shipped password.
#define NIMBUS_AP_PASS       "nimbus1234"   // WPA2 min 8 chars; "" => open AP
#define NIMBUS_MDNS_HOST     "nimbus"       // -> http://nimbus.local
// NVS keys (<=15 chars) for STA creds, stored via solide::memory::setString.
// The single slot is now the MRU MIRROR of the known-networks list below, kept so an
// OTA rollback to an older image still finds the network most likely to work.
#define NIMBUS_KEY_STA_SSID  "staSsid"
#define NIMBUS_KEY_STA_PASS  "staPass"
// Known networks (<=5) as one JSON blob. NVS and not a LittleFS file: net::begin()
// runs long before LittleFS is mounted, so a file-backed list would read empty on the
// boot-join path. It also keeps factory reset honest - nvs_flash_erase() still wipes
// every saved network, exactly as the Danger-zone copy promises.
#define NIMBUS_KEY_STA_NETS  "staNets"

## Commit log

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2026-08-31 CUM-245: compute anyKeyed over the slots in the zero-key gate test
    The fresh-device provider-gate leg now derives anyKeyed the way the device does
    (an OR over every provider slot + custom) instead of hardcoding false, so a slot
    that ever ships keyed-by-default flips anyKeyed and fails the leg.
    [main.cpp]
2026-08-31 CUM-255: fail-closed MCP prov routing - a LAN URL never reaches a provider head
    A device-dialed MCP entry with prov omitted parsed to "any", so attachOpenAIWire
    forwarded its LAN URL to the OpenAI head as server_url; OpenAI's cloud cannot
    reach a private IP, so the head turn died HTTP 424 and killed the whole turn
    (found live, CUM-61).
    Guard at the config/attach level, fail-closed:
    - forwardsToProviderHead(c, head): the single routing predicate the three
    attach*Wire builders now use. A device-dialed entry at the default prov "any"
    is device-side only; a kind==mcp entry whose URL is private/loopback/link-local/
    .local/non-http is never forwarded; an unknown/future prov matches no head.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
    [main.cpp]
2026-08-31 CUM-245: address self-review - de-duplicate flip test, pin the registry
    Four-lens self-review findings (both test-quality, no shipped-firmware bug):
    - Flip-compose: the three orientTouch point asserts duplicated test_touch_cal.
    Replaced with the genuinely-new fresh-device claim - EVERY kind's default flags
    are flip-independent (never invertX) - keeping the panel-wide bijection property.
    - Provider gate: the anyKeyed reconstruction was tautological and the comment
    overclaimed. Now pins the canonical provider REGISTRY (the CUM-242 class: a
    provider some surface fails to enumerate ships ungated) - every slot is a
    first-class gated slug, exactly one flagship, custom routed separately -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
    [main.cpp]
2026-08-31 Lane TF-N3 - CUM-257: uptime + soak counters on /api/state
    Add uptimeMs (millis since boot) and the FT6336U touch liveness counters
    (solide::touch::health, driver v0.8.0) to GET /api/state, alongside the
    existing ringBackstopFires, so the LAN-driven soak legs (CUM-243, CUM-248)
    can read device liveness over HTTP without a serial open that resets the
    board mid-run. The three soak fields are centralized in a portable,
    host-tested helper (nimbus/net/soak_state.h); buildState() only supplies the
    live values. New host test test_soak_state asserts field presence,
    value passthrough, cross-snapshot monotonicity, and the resistive-board
    all-zero shape. Docs: soak observability section in development.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
    [main.cpp]
2026-08-31 CUM-255: harden the routability guard against URL-encoding evasions
    In-session adversarial review (security + correctness lenses) confirmed several
    ways a private/LAN address slipped urlRoutableToProviderHead and reached a head:
    - hostOf ended the authority only at '/', so a query/fragment (http://127.0.0.1?x)
    left the IP glued to the query and parsed as a public host -> now split on /?#;
    - IPv4-mapped IPv6 (::ffff:10.0.0.1) and non-canonical loopback (0:0:...:1) missed
    the tiny IPv6 prefix allowlist -> now decode the embedded IPv4 and a zero-run
    loopback/unspecified spelling;
    - a trailing-dot FQDN (localhost., printer.local., 10.0.0.1.) defeated the name and
    IPv4 checks -> strip one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
    [main.cpp]
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2026-08-31 CUM-256: device MCP OAuth acquisition driver + web sign-in flow + docs
    Device seam (agent::connectors::mcp::oauth): single-flight state machine advanced
    one bounded TLS step per pump() on the main loop, reusing the shared work arbiter
    and socket helpers - no new task, single TLS slot (frozen invariant). PKCE S256,
    metadata discovery, dynamic registration, code exchange; the minted refresh token
    lands in the connector's existing T3 oauth blob slot so refreshAccess() takes over.
    Secrets never logged. Cross-task handoff via portMUX + fixed buffers.
    Web: /api/connectors/oauth/{start,status,cancel} (token-gated) + /oauth/go redirect
    and /oauth/cb capture; Connectors card gains a Sign in button t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
    [main.cpp]
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2026-08-31 CUM-256: harden OAuth acquisition after self-review
    - SSRF: gate resourceUrl, issuer, and authorize/token/registration endpoints to
    public https (reuses the CUM-255 non-private predicate); browser sign-in is for
    hosted servers only, local servers keep using a static token.
    - Callback clobber: publish the expected state and drop a non-matching or already-
    pending /oauth/cb before it touches the single handoff slot (non-allocating strcmp
    inside the critical section), so a LAN peer cannot cancel an in-progress consent.
    - RFC 9728/8414 path scoping: portable wellKnownProtectedResourcePath() + issuer-path
    insertion; discovery tries the path-suffixed metadata location first, then origin,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
    [main.cpp]
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2026-08-31 Lane TF-VN1 - CUM-263: nimbusd serves a chat page at "/"
    Virtual Nimbus had no reachable UI: GET /d/<id>/ proxied to nimbusd, which
    served only API routes, so the portal's Open landed on {"error":"not found"}.
    nimbusd now serves a self-contained dark chat page at "/" (and /index.html):
    inline CSS/JS, no external resources (the tunnel forces nosniff and reaches no
    other origin), talking to the gated API over relative URLs so it works under
    the /d/<id>/ relay prefix. The composer POSTs /api/message; the page polls a
    new GET /api/replies?after=<seq> every ~2s.
    Replies ride a bounded, thread-safe ring (reply_buffer.h): the owner prompt is
    recorded on POST, every engine reply via the always-on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
    [main.cpp, rig.h]
2026-08-31 CUM-238: cache provider-config reads so the NVS poll stops hot-looping
    The provider credentials + routing keys (orchHost, the priority lists, the
    per-provider keys) were read straight from NVS on every getter call. The screen
    render resolves the active host provider every frame via resolvedOrchHost(), and
    the engine re-checks provider readiness each turn, so on a fresh/wiped device
    (keys unset) this spammed hundreds of getString() NOT_FOUND reads per second -
    NVS wear, wasted CPU, and a console drowned in log noise during exactly the
    first-run diagnosis that matters most (CUM-237).
    Add a dirty-gated snapshot cache (lib/core/include/nimbus/store/provider_cache.h,
    portable + host-tested). sto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
    [main.cpp]
2026-08-31 Lane TF-N6 - CUM-189: first-run touch calibration step for resistive panels
    The deferred acceptance piece (per the CUM-189 DECISION): a fresh resistive
    panel now runs the guided tap-the-crosses step once on its own; capacitive
    panels skip it entirely.
    - lib/core touch_cal: pure firstRunCalPolicy(TouchKind) + firstRunCalPending()
    as the single source the boot seam reads. Switch has no default branch; the
    host class guard pins TouchKind::Count so a new touch class that ships without
    a first-run policy fails the build.
    - Host class guard (test_touch_cal): over every TouchKind - capacitive skips,
    resistive pends + drives CalWizard to completion + persists; a stored cal
    never re-offers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
    [main.cpp]
2026-08-31 Lane TF-VN1 - CUM-263: harden the reply path after self-review
    Two fixes from the in-session security pass:
    - Encode the entry role through the same JSON escaper as text, so a future
    non-literal role can never break out of the /api/replies JSON string (defense
    in depth; role is a fixed literal today).
    - Make the Telegram sender pointer std::atomic. The delivery hook runs on the
    engine thread and could read the pointer while the main thread fills it in
    after bot validation - a startup-only data race. acquire/release loads and
    stores remove the UB; behavior is otherwise unchanged.
    [main.cpp]
2026-08-31 CUM-189: suppress redundant first-run cal if owner calibrated during setup
    Self-review finding: g_firstRunCalPending is armed at boot and drained after
    setup, so if the owner calibrates via Settings > Display or the web field DURING
    setup, the drain would re-run calibration a second time. Re-evaluate
    firstRunCalPending against the current stored-cal state at drain time so any
    calibration done meanwhile suppresses the offer. Guarded as an if-block (not an
    early return) so the loop's render pass is never skipped.
    [main.cpp]
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2026-08-31 CUM-207: lib/core failover-aware recovery, reorder op, N/M status copy
    Portable pieces for wiring the multi-network Wi-Fi failover machine (step 8):
    - decideSetupAp() gains failoverActive: while the supervisor cycles scan -> next
    saved network, recovery stands down so trying the NEXT network is progress, not
    churn; the setup AP only returns once failover is exhausted. Class-level test over
    every (sta, ap, onboarded, since, board) combo.
    - moveNetwork(): optional user priority reorder (a tie-break hint, not a hard pin).
    - LinkView candIndex/candCount + WifiPolicy::candidateIndex(): fail-honest on-screen
    status 'Joining <ssid> 2/3...', guarded against a lone candidate and bad counts.
    A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
    [main.cpp]
2026-08-31 CUM-207: wire multi-network failover supervisor to the live radio (step 8)
    New src/net/wifi_link: an additive, engage-on-failure supervisor driving the
    host-tested WifiPolicy inline from loop() (no task, no concurrency). It stays passive
    - the bench-verified core auto-reconnect + decideSetupAp path is untouched - except
    when Orchestrator + onboarded + >=2 saved networks + link down past an 8s grace + no
    manual join/AP-client. Then it stops the core hammering the dead SSID, scans, and
    tries the next saved network by signal; on GOT_IP it records the join and hands
    steady-state back to the core. Single-network and first-run flows are byte-identical.
    - decideSetupAp fed link::failoverActive() s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
    [main.cpp]
2026-08-31 fix(ota): never surface HIL sim-arm residue to owners (CUM-264 #2)
    simArm wrote 'sim-arm <slot>' into the persisted OTA last-result; simClear left
    it behind and lastResultStale only clears 'ok vX' records, so 'sim-arm crash'
    (OTASIM arm crash, the L29 rollback drill) survived into a later production
    reflash and showed on the owner panel.
    - isSimResult() class predicate in lib/core (guards on kSimResultPrefix)
    - bootGuard clears sim-* residue in the nothing-pending branch
    - simClear clears the last-result on HIL teardown
    - production lastResult() accessor filters sim-* immediately (pre-restart)
    - L29 rollback drill clears in a finally so residue never survives a failed run
    - host class test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
    [main.cpp]
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2026-08-31 fix(webui): single-source the OTA verdict line from ota.status (CUM-264 #1)
    The 'You are on the latest version' verdict was written once by the check action
    and left frozen in the DOM; applyState refreshed the status field from d.ota every
    3s but never the verdict, so a stale 'latest' line could sit next to status=available
    with an active Install button (the owner screenshot).
    - applyState now re-derives fwMsg from d.ota (the same read as the Status field) on
    every render, for the terminal verdict states; a live action's own spinner/error
    is left alone. A stale positive verdict can no longer contradict the status.
    - host class test: for EVERY State, the verdict line and status token can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
    [main.cpp]
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2026-08-31 nimbusd: harden + fix review findings (CUM-265)
    Security (prism security-audit): remove the ungated /api/signin/exchange that
    handed back the gating web token to any loopback caller (the served page already
    seeds the token, so the endpoint was a redundant secret-disclosure); cap the
    pre-auth request body at 1 MiB (413) so an unauthenticated peer cannot make the
    daemon buffer an unbounded/negative Content-Length body.
    Correctness (prism peer/correctness review):
    - engineRead returns 503 (not 200) on busy/stopping, and short-circuits to 503
    when a turn is in flight so a dispatched mem/tools poll never blocks the single
    HTTP thread (which also serves /healthz, /readyz and the snapshot rout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
    [main.cpp]
2026-08-31 CUM-207: fix review findings (self-review, four lenses)
    HIGH (security lens): saveAndConnect() never cleared the failover supervisor's manual
    hold, so after the escape-hatch flow (publishap -> wizard join) failover stayed silently
    disabled for the rest of uptime - the device would hunt a dead SSID at a new location
    exactly as before the feature. Fix: markManualHoldClear() (off-task-safe volatile flag,
    applied on the main loop like markKnownDirty), called from saveAndConnect.
    LOW: seam scan wedge 15s -> 10s so it stays below the policy's 12s scanTimeout (they were
    inverted); status() no longer surfaces a stale 'trying N/M' once the policy falls past
    Scanning/Joining. Simplify lens: drop an u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
    [main.cpp]
2026-08-31 CUM-207: fix pre-merge review findings (F1 HIGH, F2, F4)
    F1 (HIGH): empty-candidate out-of-bounds in WifiPolicy. A Forget (or any list edit) while a
    join is in flight calls setKnown(), which clears cands_ but leaves state Joining; the two
    retry-same-candidate branches then indexed the empty/shrunk vector -> OOB read -> panic or a
    garbage-credential join, mid-recovery. Guard candIdx_ < cands_.size() in both branches
    (fall to advanceCandidate -> Unreachable). Added two mid-cycle host tests, proven RED before
    the guard ('Expected 4 Was 2' = a stale Join) and GREEN after.
    F2 (MEDIUM): disengage() set setAutoReconnect(true) but never re-begins, and the core
    short-circuits auto-reconnect after ou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
    [main.cpp]
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2026-08-31 CUM-256: MCP robustness class tests (host) + SRAM-headroom HIL leg
    Host class-tests (test/test_mcp_robustness), each fails against an absent guard:
    - many connectors configured, no silent drop; one flapping server's cooldown is
    isolated to its own per-server breaker (not a global).
    - serialization: every request builder emits exactly one JSON-RPC request, never
    a batch array, so the transport never carries two calls in flight.
    - big payloads: the transport-error class is exhaustive over ErrorKind (a new
    transport kind fails the test), an over-cap body is refused with the honest cap
    line (not the parse-error line the truncated prefix would get), oversize is not
    retryable, and an und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
    [main.cpp]
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2026-08-31 CUM-274 + CUM-275: OAuth /oauth/go launch-key gate; provenance-based outbound moderation exemption
    CUM-274 (HIGH): the MCP connector OAuth /oauth/go redirect was unauthenticated and
    handed the CSRF `state` to any LAN caller, letting a peer race the callback and bind
    their own provider account to the owner's connector (account fixation). The device now
    mints a per-flow 128-bit launch key at the authenticated flow start, carries it only on
    the owner's verify URL / web-UI QR (both owner-only paths), and requires it (?k=) on
    /oauth/go. authorizeUrl(key) returns the state-bearing URL only for the matching key;
    a keyless or wrong-key request is sent to the home page and never sees `state`. Gate is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
    [main.cpp, orchestrator.cpp]
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2026-08-31 CUM-286: nimbusd consumes CUMULO_API_KEY (the VN one-key path's last inch)
    The hosted daemon read MISTRAL/OPENAI/ANTHROPIC keys from the environment but
    never the Cumulo router key, so a keyed Virtual Nimbus still reported
    "Provider: degraded - no provider key" and refused to reply. This mirrors the
    device seam (src/agent/orchestrator.cpp cumulo head + store_config
    routerFallbackHost) on the daemon:
    - Config reads canonical env CUMULO_API_KEY.
    - The rig registers a first-class "cumulo" head (orchTurnCustom over the fixed
    router base app.cumulo-nimbus.ai + /router/openai/v1 + the router key) when
    the key is present.
    - provider.routerFallbackHost -> "cumulo" when only the router key is se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
    [main.cpp, rig.h]
2026-08-31 CUM-288: fold ladder falls back to the router head (Cumulo-only can compact)
    TurnEngine::foldHostCandidates() built its ladder from orchHost() + the
    hasKey()-gated BYOK priority walk only. The Cumulo router key is not a BYOK
    slot (hasKey("cumulo") is false), so a Cumulo-only instance produced an empty
    candidate list: canFoldNow() was always false and runFold never dispatched.
    Chat worked (runTurn already consults routerFallbackHost()), but memory never
    folded, so context grew unbounded until turns failed.
    - engine.cpp foldHostCandidates(): when the BYOK ladder is empty, fall back to
    routerFallbackHost() (registered + in budget, NOT hasKey-gated; the fn embeds
    its own turn-time key check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
    [main.cpp, rig.h]
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2026-09-01 CUM-218: fix mid-turn chat handling (silent drop + stale reply replay) + hosted honesty r3
    Server (nimbusd): the web reply slot was single-owner and fenced one entry too
    early - chatPost captured the fence before pushing its prompt row, so a still-in-
    flight prior turn's later reply matched as this turn's answer (the '6' replay), and
    a second concurrent POST clobbered the slot (silent drop). Replace with a per-turn
    FIFO: chatPost fences on its own prompt-row seq and returns it as turn id; chatGet
    matches ?turn=<id>, consuming assistant replies oldest-first and monotonically
    (webConsumedSeq_). Reply-ring entries are now tagged by delivery channel so a
    Telegram/routine reply landing mid-web-tu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
    [main.cpp]
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2026-09-01 CUM-292: restore rest glow if external power connects while deep-dimmed
    Prism (roast/correctness) finding: deep-dim is a battery-only state, but only the
    ENTRY was gated on it. If a charger auto-connected while the panel was already
    deep-dimmed (backlight off), nothing lifted it back to the rest glow, leaving a
    powered device looking broken - the exact 'and now it's black' confusion the rest
    glow exists to prevent. Add the symmetric one-shot exit: on external power while
    deep-dimmed, restore kBacklightRestPct. Fires once, mutually exclusive with the
    entry block, and a tap still wakes fully.
    [main.cpp]
2026-09-01 CUM-293: per-turn correlation id for web chat replies (burst-of-N drop)
    The web chat reply matcher paired each turn to a reply by RING POSITION (the
    next assistant seq after a per-turn fence). That assumes exactly one assistant
    delivery per turn; a real turn can deliver an interim line then its final answer
    (two) or nothing (a silent/errored turn). Any turn whose delivery count is not
    one then shifted every later turn's reply forward and dropped the last - the
    owner saw a burst of three messages answer the first two and never the third
    (the second stacked entry). The rapid-fire N=8 host test never caught it because
    it feeds exactly one substituted reply per turn.
    Thread a per-turn correlati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
    [main.cpp]
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2026-09-01 CUM-189: fresh-CYD out-of-box - upright render + no spurious e-ink notice on erased NVS
    Two out-of-box defects on a fresh / NVS-erased all-in-one (CYD) board:
    1. E-INK MISCONFIG NOTICE ON AN ERASED KEY.
    agent::store::screenModel() defaulted an ABSENT scrModel key to "eink", so a
    board that never set the key read as a stale e-ink unit and main.cpp raised the
    "Unsupported display setting" page. The notice is meant only for an EXPLICIT
    legacy value (a real e-ink migration).
    Fix: default the key to "tft" (the only supported display), and decide the notice
    from the RAW stored value via a host-tested resolver
    (nimbus::display::showsUnsupportedNotice): absent -> silent color p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
    [main.cpp]
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2026-09-01 CUM-281: TF-P1 audit residuals - dashboard XSS, serial-log redaction seam, minimp3 pin
    F3 (XSS): the memory dashboard error line rendered an embedding-provider error
    string (d.error) into #memlist innerHTML unescaped. Escape it at the sink with
    _wesc, the same helper the Wi-Fi list already uses. Re-blessed the web-UI byte
    snapshot (only that one line changed, inspected) and regenerated the hosted page
    (nimbusd/src/webui_page.h) from the fragments. Added a Playwright class test
    (70_xss F3, desktop + phone) that fails on the vulnerable code and passes on the
    fix; an <img onerror> payload never becomes a real element.
    F4 (serial-log redaction bypass): alog()/alogf() printed the raw message to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
    [main.cpp]
2026-09-02 CUM-294: Wi-Fi failover kickOwed fix - a blocked re-begin edge is no longer consumed forever
    The failover supervisor hands a live retry back to the Arduino core (one WiFi.begin,
    the "re-begin kick") when it bows out of an engaged failover with the link still down.
    That kick fired only on the engaged->disengaged EDGE, so an edge blocked by a transient
    radio owner - a manual credential test in flight (msSinceJoinAttempt), a client on the
    setup AP, or the escape-hatch hold - was dropped and never re-issued. The STA then sat
    idle until a scan, a manual join, or a reboot. Live-reproduced 2026-09-02: a manual join
    to a phone hotspot that then vanished stranded the device ~27 min (the bow-out kick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
    [main.cpp]
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2026-09-02 feat(danger-zone): honest Format offer-gate + confirm/quota class tests (CUM-15)
    Danger-zone v2 hardening. Once the driver gained solide::storage::format() the
    sdFormat hook is wired unconditionally, so webui's canFormat went always-true and
    the Format Card control showed even on a device with no card - a knob that can only
    fail (the CUM-290 lying-knob class). Gate it on a card actually being present.
    - lib/core danger_zone.h: one destructive-action matrix (slug + typed confirm +
    offer rule) with a Count sentinel + static_assert, so a new destructive action
    that lands without a matrix row fails the build instead of shipping ungated.
    Pure predicates offerRuleFor / shouldOffer / offerFo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
    [main.cpp]
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2026-09-02 CUM-295: sign-in code hand-entry gets a 10-minute window + honest countdown
    The "Show code" fallback exists for the owner who cannot scan the Sign-in QR, but
    it displayed the durable token with no TTL, and the wider design left the scan-path
    2-minute code as the only timed credential. Reading a code off the screen and typing
    it into another machine routinely blew past 2 minutes, and a stale code sat on screen
    as if valid, which read as "the code is broken" instead of "you were too slow".
    Now the Show-code (TokenDetail) screen shows a single-use, TTL-bounded sign-in code
    minted with a 10-minute display TTL and a live mm:ss countdown that re-mints and
    repaints the moment it expires, so a dead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
    [main.cpp]
2026-09-02 CUM-49: host-test the code-sandbox SD round-trip (capture limits + integrity)
    Extract the two provider-file capture decisions into portable, host-tested
    lib/core helpers and refactor the device adapter to call them:
    - captureFitsCap: the streaming byte cap (overflow-safe) - the sandbox exec limit.
    - captureVerdict: the download integrity gate (refuse truncated/empty/non-200).
    provider_file_fetch.cpp now uses both (behavior-preserving; the empty-file case
    gets a clearer reason). New test_provider_capture covers the cap boundary and
    overflow, every verdict failure mode, and a byte round-trip via BlobHasher
    (write, read, same hash; a flipped byte is detected).
    The sandbox software and provider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
    [main.cpp]
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

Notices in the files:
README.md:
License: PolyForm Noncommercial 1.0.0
